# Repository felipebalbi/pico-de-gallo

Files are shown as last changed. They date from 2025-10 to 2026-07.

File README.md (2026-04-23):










# Pico de Gallo

A USB bridge that turns a [Raspberry Pi Pico 2](https://www.raspberrypi.com/products/raspberry-pi-pico-2/)
into a host-accessible I²C, SPI, UART, GPIO, PWM, ADC, and 1-Wire interface. Write and test
embedded Rust drivers on your development machine without cross-compiling
or flashing firmware to a target board.

## Overview

Pico de Gallo provides:

- **I²C**: read, write, write-then-read, bus scanning, and transaction batching
- **SPI**: read, write, full-duplex transfer, write-then-read, and transaction batching
- **UART**: read, write, flush, and baud rate configuration
- **GPIO**: digital input/output, edge event monitoring (subscribe/unsubscribe)
- **PWM**: 4-channel PWM output with configurable frequency and duty cycle
- **ADC**: 4 GPIO-based analog inputs (12-bit)
- **1-Wire**: bus reset, read, write, strong pullup, and ROM search (PIO hardware)
- **Configuration**: runtime I²C/SPI/UART/PWM frequency and SPI mode changes

All communication uses [postcard-rpc](https://docs.rs/postcard-rpc) over
USB — a compact, typed, binary RPC protocol.

## Book

The [Pico de Gallo Book](https://opendevicepartnership.github.io/pico-de-gallo/)
covers hardware assembly, firmware flashing, and a step-by-step guide to
writing an embedded device driver using Pico de Gallo.

## Crates

| Crate | Description |
|---|---|
| [`pico-de-gallo-firmware`](crates/pico-de-gallo-firmware) | Embassy-rs firmware for the RP2350 |
| [`pico-de-gallo-lib`](crates/pico-de-gallo-lib) | Async host library (requires tokio) |
| [`pico-de-gallo-hal`](crates/pico-de-gallo-hal) | `embedded-hal` + `embedded-hal-async` implementation |
| [`pico-de-gallo-ffi`](crates/pico-de-gallo-ffi) | C FFI bindings (shared library + header) |
| [`gallo`](crates/pico-de-gallo-app) | CLI application for batch-mode access |
| [`pico-de-gallo-internal`](crates/pico-de-gallo-internal) | Shared wire-protocol types (internal) |

### Firmware

Embassy-rs firmware for the RP2350 that exposes I²C, SPI, UART, and GPIO
peripherals over USB via postcard-rpc endpoints.

### Library

Async host-side library wrapping the postcard-rpc transport. Provides
typed methods for every firmware endpoint. Requires the tokio runtime.

### HAL

Implements both `embedded-hal` and `embedded-hal-async` traits — including
`I2c`, `SpiBus`, `SpiDevice`, GPIO digital I/O, delay, and `embedded-io`
Read/Write for UART — so embedded device drivers written against those traits
can be tested on a host machine with real hardware attached to the Pico de Gallo.

### App

Command-line tool (`gallo`) for interactive and batch-mode I²C/SPI/UART/GPIO
access. Supports hex, binary, and ASCII output formats.

### FFI

C-compatible shared library wrapping the Rust host library. Generates a
C header via cbindgen. Suitable for integration into C/C++/Python/etc.
projects.

### Internal

Shared wire-protocol crate defining all postcard-rpc endpoints, request
and response types, and constants. Used by both firmware and host crates.

## Hardware

KiCAD schematic and PCB design for a Pico 2 daughter board. The v1.1
board features a single keyed 2x12 shrouded header that routes all 20
firmware signals with on-board I²C pull-ups and ADC input protection.

## Case

3D-printable snap-fit enclosure (FreeCAD) in two parts — body and lid.

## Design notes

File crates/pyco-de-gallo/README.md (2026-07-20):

# pyco-de-gallo

Python bindings for [Pico de Gallo](https://github.com/OpenDevicePartnership/pico-de-gallo),
a USB-attached protocol bridge built on the
[Raspberry Pi Pico 2](https://www.raspberrypi.com/products/raspberry-pi-pico-2/)
(RP2350). Talk **I²C, SPI, UART, GPIO, PWM, ADC, and 1-Wire** straight from
Python — no cross-compiling, no flashing on every change. Develop and test
your embedded drivers on your laptop and let the Pico do the wiggling.

The native extension wraps the async Rust host library (`pico-de-gallo-lib`)
with [PyO3](https://pyo3.rs). Every method is **synchronous** from Python's
point of view; the async USB I/O is driven by a Tokio runtime owned by each
device handle, and the GIL is released for the duration of each round-trip so
your other Python threads keep running.

## Requirements

`pip install` gives you the host-side library. To do anything useful you also
need the hardware: a Raspberry Pi Pico 2 (or a Pico de Gallo landing board)
running the [Pico de Gallo firmware](https://github.com/OpenDevicePartnership/pico-de-gallo).

- **Python:** CPython 3.8+ (and PyPy). Prebuilt wheels are published for
  CPython 3.8–3.14.
- **Platforms:** Linux (x86_64 / aarch64, manylinux + musllinux),
  Windows (x64 / x86), macOS (Apple silicon).

## Installation

```sh
pip install pyco-de-gallo
```

The Python import name is `pyco_de_gallo` (underscores), while the
distribution name on PyPI is `pyco-de-gallo` (hyphens).

## Quick start

```python
import pyco_de_gallo as gallo

# Connect to the first attached board and verify the firmware is
# wire-compatible with this library. Raises RuntimeError on mismatch.
dev = gallo.open_strict()

v = dev.version()
print(f"Firmware {v.major}.{v.minor}.{v.patch}")

# I²C: switch to 400 kHz, then write a register pointer and read it back.
dev.i2c_set_config(gallo.I2cFrequency.Fast)
data = dev.i2c_write_read(0x50, [0x00], 16)   # e.g. read 16 bytes from an EEPROM
print(list(data))
```

If several boards are connected, pick one deterministically by serial number:

```python
import pyco_de_gallo as gallo

for d in gallo.list_devices():
    print(d.serial_number, d.manufacturer, d.product)

dev = gallo.open_strict_with_serial_number("E6625C087B...")
```

> `open()` / `open_with_serial_number()` are the lazy variants: they connect
> but only surface failures on the first RPC call. Prefer the `*_strict`
> variants in real code — they fail fast with a clear exception if the device
> is unreachable or the firmware schema doesn't match.

## Peripherals

| Bus | Highlights |
|---|---|
| I²C | `i2c_read` / `i2c_write` / `i2c_write_read`, `i2c_scan`, `i2c_batch`, 100 kHz–1 MHz |
| SPI | `spi_read` / `spi_write` / `spi_transfer`, `spi_batch` under chip-select, configurable phase/polarity |
| UART | `uart_read` (with timeout) / `uart_write` / `uart_flush`, configurable baud rate |
| GPIO | read/write, blocking edge waits (with optional timeout), and push-based edge events |
| PWM | per-channel duty cycle, frequency, phase-correct, enable/disable |
| ADC | single-shot 12-bit reads on 4 channels |
| 1-Wire | reset/presence, read/write, strong-pullup, and ROM search |

> Some peripherals (ADC, UART, 1-Wire) require **hw-rev2** firmware, and not
> every signal is broken out on the V1 landing board. See the firmware and
> hardware docs for the routing details.

### Blink an LED (GPIO)

```python
import time
import pyco_de_gallo as gallo

dev = gallo.open_strict()
dev.gpio_set_config(0, gallo.GpioDirection.Output, gallo.GpioPull.Disabled)

while True:
    dev.gpio_put(0, True)
    time.sleep(0.5)
    dev.gpio_put(0, False)
    time.sleep(0.5)
```

### React to GPIO edges (push events)

```python
import pyco_de_gallo as gallo

dev = gallo.open_strict()

# The subscription must be live before the firmware will buffer events.
with dev.subscribe_gpio_events() as events:
    dev.gpio_subscribe(0, gallo.GpioEdge.Falling)
    for event in events:
        print(event.pin, event.edge, event.state, event.timestamp_us)
```

### Scan the I²C bus

```python
import pyco_de_gallo as gallo

dev = gallo.open_strict()
dev.i2c_set_config(gallo.I2cFrequency.Standard)

for addr in dev.i2c_scan(include_reserved=False):
    print(f"0x{addr:02x}")
```

## Error handling

Failures from the underlying transport and firmware are raised as Python
`RuntimeError` exceptions with a descriptive message (for example, an I²C
NACK, a GPIO timeout, or a firmware schema mismatch).

## More examples

Runnable scripts for every peripheral — including a live TMP108 temperature
graph, a PWM sine-wave fade, a SPI loopback test, and a 1-Wire ROM search —
live in the
[`examples/`](https://github.com/OpenDevicePartnership/pico-de-gallo/tree/main/crates/pyco-de-gallo/examples)
directory.

## Documentation

- Project book: <https://opendevicepartnership.github.io/pico-de-gallo/>
- Source and issues: <https://github.com/OpenDevicePartnership/pico-de-gallo>

## License

MIT

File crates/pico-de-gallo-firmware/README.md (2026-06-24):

# Pico de Gallo Firmware

Embassy-rs firmware for the Raspberry Pi Pico 2 (RP2350) that turns it into
a USB bridge for I2C, SPI, and GPIO access.

## Building

```console
$ rustup target add thumbv8m.main-none-eabihf
```

For rev1 hardware:

```console
$ cargo build --release --manifest-path crates/pico-de-gallo-firmware/Cargo.toml --target thumbv8m.main-none-eabihf
```

For rev2 hardware:

```console
$ cargo build --release --manifest-path crates/pico-de-gallo-firmware/Cargo.toml --target thumbv8m.main-none-eabihf --no-default-features --features hw-rev2
```

## Flashing

Convert the ELF to UF2 and copy to the Pico 2 in BOOTSEL mode:

```console
$ picotool uf2 convert crates/pico-de-gallo-firmware/target/thumbv8m.main-none-eabihf/release/pico-de-gallo-firmware -t elf firmware.uf2
$ picotool load firmware.uf2
```

Or simply drag `firmware.uf2` onto the `RP2350` USB mass storage drive.

## Peripheral Mapping

| Function | RP2350 Pins | Notes |
|---|---|---|
| I2C1 SDA | GPIO 2 | 7-bit addressing, async mode |
| I2C1 SCL | GPIO 3 | |
| SPI0 SCK | GPIO 6 | DMA-backed full-duplex |
| SPI0 TX  | GPIO 7 | |
| SPI0 RX  | GPIO 4 | |
| GPIO 0–7 | GPIO 8–15 | Input/output/edge-wait |
| USB | Native USB  | postcard-rpc transport |

## License

Licensed under the terms of the [MIT license](http://opensource.org/licenses/MIT).

## Contribution

Any contribution intentionally submitted for inclusion in the work by
you shall be licensed under the terms of the same MIT license, without
any additional terms or conditions.

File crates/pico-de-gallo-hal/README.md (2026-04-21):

# Pico de Gallo HAL




[embedded-hal](https://crates.io/crates/embedded-hal) and
[embedded-hal-async](https://crates.io/crates/embedded-hal-async)
implementation backed by a [Pico de Gallo](https://github.com/OpenDevicePartnership/pico-de-gallo)
USB bridge.

Run embedded Rust drivers on your host machine by forwarding I²C, SPI,
GPIO, and delay operations to real hardware via USB.

## Quick Start

```rust
use pico_de_gallo_hal::Hal;
use embedded_hal::i2c::I2c;

let hal = Hal::new();
let mut i2c = hal.i2c();

let mut buf = [0u8; 2];
i2c.write_read(0x48, &[0x00], &mut buf).unwrap();
```

Check out the
[examples](https://github.com/OpenDevicePartnership/pico-de-gallo/tree/main/crates/pico-de-gallo-hal/examples)
for more usage patterns.

## Implemented Traits

| Peripheral | Blocking | Async |
|---|---|---|
| GPIO | `OutputPin`, `InputPin`, `StatefulOutputPin` | `Wait` |
| I²C | `I2c` | `I2c` |
| SPI | `SpiBus`, `SpiDevice` | `SpiBus`, `SpiDevice` |
| Delay | `DelayNs` | `DelayNs` |

`SpiDevice` manages chip-select (CS) automatically via a GPIO pin.
Use `hal.spi_device(cs_pin)` to create one. For raw bus access without
CS management, use `hal.spi()`.

# License

Licensed under the terms of the [MIT license](http://opensource.org/licenses/MIT).

# Contribution

Any contribution intentionally submitted for inclusion in the work by
you shall be licensed under the terms of the same MIT license, without
any additional terms or conditions.

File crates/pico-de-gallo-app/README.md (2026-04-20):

# Gallo




Command-line interface for the [Pico de Gallo](https://github.com/OpenDevicePartnership/pico-de-gallo)
USB bridge. Provides direct access to I²C, SPI, and GPIO peripherals
in batch mode.

# Usage

```console
$ gallo list                             # List connected devices
$ gallo version                          # Query firmware version
$ gallo i2c scan                         # Scan I2C bus
$ gallo i2c read -a 0x48 -c 2            # Read 2 bytes from address 0x48
$ gallo i2c write -a 0x50 -b 0xDE 0xAD   # Write bytes to address 0x50
$ gallo spi transfer -b 0x01 0x02        # Full-duplex SPI transfer
$ gallo spi read -c 10 -f ascii          # Read 10 bytes, ASCII output
```

## Output Formats

Read data can be displayed in three formats via `-f` / `--format`:

- `hex` (default): hexadecimal byte dump
- `binary`: raw bytes to stdout
- `ascii`: printable characters, non-printable shown as `.`

# License

Licensed under the terms of the [MIT license](http://opensource.org/licenses/MIT).

# Contribution

Any contribution intentionally submitted for inclusion in the work by
you shall be licensed under the terms of the same MIT license, without
any additional terms or conditions.

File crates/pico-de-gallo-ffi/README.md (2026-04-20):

# Pico de Gallo FFI




C-compatible FFI bindings for the [Pico de Gallo](https://github.com/OpenDevicePartnership/pico-de-gallo)
USB bridge. Wraps the Rust host library in an opaque-pointer API with
integer status codes, suitable for use from C, C++, Python, and other
languages.

## Usage

```c
#include "pico_de_gallo.h"

const PicoDeGallo *gallo = gallo_init();
uint32_t id = 42;
Status status = gallo_ping(gallo, &id);
gallo_free(gallo);
```

A C header (`pico_de_gallo.h`) is generated automatically by
[cbindgen](https://docs.rs/cbindgen) at build time.

# License

Licensed under the terms of the [MIT license](http://opensource.org/licenses/MIT).

# Contribution

Any contribution intentionally submitted for inclusion in the work by
you shall be licensed under the terms of the same MIT license, without
any additional terms or conditions.

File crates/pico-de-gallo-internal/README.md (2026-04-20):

# Pico de Gallo Internal




Shared wire-protocol types for the [Pico de Gallo](https://github.com/OpenDevicePartnership/pico-de-gallo)
USB bridge. This crate defines all [postcard-rpc](https://docs.rs/postcard-rpc)
endpoints, request/response types, and constants used by both the
firmware and host-side library.

> **Note:** This is an internal crate. Application code should use
> [`pico-de-gallo-lib`](https://crates.io/crates/pico-de-gallo-lib) or
> [`pico-de-gallo-hal`](https://crates.io/crates/pico-de-gallo-hal) instead.

## Features

- `use-std` — Enables `Vec<u8>` response types for the host side.
  Without this feature (the firmware default), responses use borrowed
  `&[u8]` slices.

# License

Licensed under the terms of the [MIT license](http://opensource.org/licenses/MIT).

# Contribution

Any contribution intentionally submitted for inclusion in the work by
you shall be licensed under the terms of the same MIT license, without
any additional terms or conditions.

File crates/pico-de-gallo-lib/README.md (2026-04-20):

# Pico de Gallo Lib




Async host-side library for communicating with a [Pico de Gallo](https://github.com/OpenDevicePartnership/pico-de-gallo)
USB bridge device. Provides typed methods for I²C, SPI, GPIO, and
device configuration over USB.

Requires the [tokio](https://tokio.rs) async runtime.

## Quick Start

```rust
use pico_de_gallo_lib::PicoDeGallo;

#[tokio::main]
async fn main() {
    let gallo = PicoDeGallo::new();
    let version = gallo.version().await.unwrap();
    println!("Firmware v{}.{}.{}", version.major, version.minor, version.patch);
}
```

See the [examples](https://github.com/OpenDevicePartnership/pico-de-gallo/tree/main/crates/pico-de-gallo-lib/examples)
for more usage patterns.

# License

Licensed under the terms of the [MIT license](http://opensource.org/licenses/MIT).

# Contribution

Any contribution intentionally submitted for inclusion in the work by
you shall be licensed under the terms of the same MIT license, without
any additional terms or conditions.

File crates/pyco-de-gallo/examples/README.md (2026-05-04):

# pyco-de-gallo examples

Runnable Python scripts that demonstrate how to drive a Pico de Gallo
device from the `pyco_de_gallo` Python module.

## Setup

From the `crates/pyco-de-gallo` directory:

```sh
python -m venv .env
. .env/bin/activate          # Windows: .env\Scripts\Activate.ps1
pip install maturin
maturin develop --release
```

This builds the native extension and installs it into the active
virtual environment.

## Running

With the device plugged in:

```sh
python examples/tmp108_read.py
```

## Examples

| Script | Peripheral | What it does |
|---|---|---|
| `device_info.py`  | none | Lists every attached device and prints firmware/schema versions plus a capability matrix. |
| `i2c_scan.py` | I2C | Scans the I2C bus and prints every responding 7-bit address. |
| `tmp108_read.py`  | I2C | Reads ambient temperature from a TMP108 sensor at `0x48`. |
| `tmp108_live.py`  | I2C | Live scrolling temperature graph (Rich + braille). Needs `pip install rich`. |
| `gpio_blink.py` | GPIO | Blinks an LED on GPIO0. |
| `gpio_events.py`  | GPIO | Subscribes to falling edges on GPIO0 and prints each event. |
| `pwm_fade.py` | PWM | Smoothly fades an LED with a sine wave on PWM channel 0. |
| `adc_read.py` | ADC | Reads all 4 ADC channels and prints millivolts (needs hw-rev2 firmware). |
| `spi_loopback.py` | SPI | Verifies SPI by short-circuiting MOSI to MISO. |
| `uart_echo.py` | UART | Verifies UART by short-circuiting TX to RX (needs hw-rev2 firmware). |
| `onewire_scan.py` | 1-Wire | Discovers ROM IDs of every device on the 1-Wire bus (needs hw-rev2 firmware). |

Each script has a wiring comment at the top describing exactly how to
connect the parts. On the **V1 landing board**, only I2C, SPI (without
CS), GPIO 0–3, and PWM 0–3 are routed to connectors — for ADC, UART,
1-Wire, or SPI-CS you need to wire to the bare Pico's castellated
pads.

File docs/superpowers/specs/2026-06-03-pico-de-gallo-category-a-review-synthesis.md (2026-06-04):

# Spec: Category A Hotfix — Review Synthesis

- **Date:** 2026-06-03
- **Status:** Draft — basis for `2026-06-03-pico-de-gallo-category-a-hotfix.md` plan
- **Scope:** Captures findings from three parallel read-only subagent
  reviews (reviewer / reliability / architect) of the seven crates in
  `crates/` and partitions them into three categories. Specifies the
  Category A hotfix (this spec → that plan). Lists Category B and C as
  out-of-scope for the hotfix but tracked for future work.

## 1. Background

After PR #56 (the AI-agent HAL guide) shipped, we dispatched three
read-only subagents in parallel to audit the seven Rust crates under
`crates/`:

- **reviewer** (adversarial correctness) — looked for surface gaps,
  wire-protocol inconsistencies, cross-crate parity drift, test
  coverage holes, hygiene issues, book/code drift.
- **reliability** (failure modes) — looked for host crash recovery,
  USB transport failure, firmware-side panics / wedges, race
  conditions, timeouts, idempotency, observability.
- **architect** (design) — looked for module/crate boundary mistakes,
  API shape problems, error-type design, wire-protocol scalability,
  versioning model, long-term evolution.

This spec deduplicates their findings, prioritizes by severity, and
groups them by what work each finding implies.

## 2. Findings (43 items, prioritized)

### 2.1 Critical bugs — Category A (fix before next release)

| # | Finding | Source | Severity |
|---|---|---|---|
| 1 | `validate()` ignores `schema_major` — only compares minor. Today the minor is the pre-1.0 breaking-change axis so the check works; the moment `internal` hits 1.0 or someone bumps major by mistake, validation silently accepts a mismatched device. | reviewer B1: `crates/pico-de-gallo-lib/src/lib.rs:667` | Blocker for 1.0 |
| 2 | GPIO `wait_for_*` wedges the entire firmware dispatcher. Host crash + `gpio_wait_for_high` on a pin that never transitions = device unusable until power-cycle. Worse than the original `system/reset-subscriptions` regression because it bricks the whole device. | reliability B1: `crates/pico-de-gallo-firmware/src/handlers/gpio.rs:86–143` | Blocker — field reproducible |
| 3 | No watchdog in firmware. Any handler hang (B2 above, I²C stuck bus, 1-Wire PIO stall) requires power-cycle to recover. | reliability R5: `crates/pico-de-gallo-firmware/src/main.rs:354–468` | Blocker — defense-in-depth |

### 2.2 Real bugs — Category A (fix before next release if practical)

| # | Finding | Source | Effort |
|---|---|---|---|
| 4 | Schema validation opt-in everywhere except FFI `gallo_get_device_info`. `Hal::new`, `gallo_init`, `pyco::open`, `app::Cli::connect` all skip `validate()`. | reliability R4 | S |
| 5 | HAL doesn't expose `system_reset_subscriptions` or `validate`. (PR #56 side finding #1; reliability R2.) | known | S |
| 6 | `AdcChannel`, `GpioDirection`, `GpioPull`, `GpioEdge`, `AdcConfigurationInfo` not re-exported by `pico-de-gallo-hal`. (PR #56 side finding #2.) | known | XS |
| 7 | `gpio_subscribe_handler` capacity-1 channel can wedge dispatcher. Same shape as B1, requires multiple things to go wrong but it exists. | reliability S6 | S |
| 8 | I²C stuck-bus has no recovery. Slave holds SDA after host crash → every future I²C op fails until power-cycle. Need 9-SCL bit-bang recovery or new `i2c/recover` endpoint. | reliability B3 | M |
| 9 | FFI error mappers route every `*::Other` to the *read* failure code regardless of which operation was called. Dedicated `*GetConfigFailed`/`*WriteFailed` codes exist but are unreachable. | reviewer S1: `crates/pico-de-gallo-ffi/src/lib.rs:223, 231, 242, 255, 268, 276, 287` | S |
| 10 | `spi_batch_handler` mutates GPIO direction without updating `pin_modes` — silent hardware/state divergence. | reliability S2: `crates/pico-de-gallo-firmware/src/handlers/spi.rs:138` | S |
| 11 | `pico-de-gallo-ffi` has no GPIO event subscription read surface. Codes exist; subscribe/unsubscribe exist; but no `gallo_gpio_poll_event` or iter. | reviewer S2 | M |
| 12 | `pyco-de-gallo` ADC binding takes raw `u8` instead of `AdcChannel` enum. Bypasses Python type system. | reviewer S5: `crates/pyco-de-gallo/src/lib.rs:1287` | XS |
| 13 | Stale doc reference to `Hal::uart_set_config` at `crates/pico-de-gallo-hal/src/lib.rs:1282`. (PR #56 side finding #3.) | known | XS |
| 14 | `pico-de-gallo-internal` GPIO range docs inconsistent — some say `0..=7` (wrong), some say `0..=3` (right). | reviewer S3 + PR #56 side finding #4: `crates/pico-de-gallo-internal/src/lib.rs:470, 482, 510, 547, 586` | XS |
| 15 | Book endpoint catalog (`book/src/appendix/endpoints.md` lines 77–88) describes `gpio/event` topic wrong — implies one stream per pin, actually one multiplexed stream. | reviewer S6 | XS |

### 2.3 Test / hygiene additions — Category A

| # | Finding | Source | Effort |
|---|---|---|---|
| 34 | FFI `Status` enum has no discriminant-uniqueness test. Copy-paste during enum extension could collide. | reviewer B2 | XS |
| 35 | `crates/pico-de-gallo-internal/build.rs` schema constants have no test asserting they match `[package].version`. Stale incremental cache could ship a mismatched build. | reviewer S8 | XS |
| 36 | CI grep guard for the PR #56 agent-guide markdown not yet implemented. (PR #56 side finding #5.) | known | XS |

### 2.4 Architectural commitments — Category B (decide before 1.0)

These are not part of the Category A hotfix. Listed for tracking and
for the post-hotfix architectural discussion.

| # | Decision | Source | Cost if deferred |
|---|---|---|---|
| 16 | Freeze `internal` enum-ordering ABI with explicit discriminants on every wire enum + golden-file postcard snapshot tests. Today enforced only by comments. | architect 1.1 | Major break post-1.0 |
| 17 | `PicoDeGallo` is a flat god-object (50+ methods). Split into per-peripheral handles so HAL is mostly mechanical and there's a place for cached session state. | architect 1.2 | Major break post-1.0 |
| 18 | FFI `Status` enum is sequential-by-insertion-order, not grouped. Reserve ranges per peripheral now, while still 0.x. | architect 1.6 + reviewer S1 | Major C ABI break post-1.0 |
| 19 | Add `gpio_pin_count`, `pwm_channel_count`, `adc_channel_count`, `i2c_bus_count`, `spi_bus_count` to `DeviceInfo` now. Host currently assumes 4/4/4/1/1. | architect 1.8 | Major break post-1.0 |
| 20 | Add optional `bus: u8` (default 0) to every peripheral request type now, before 1.0. Adding a second I²C/SPI bus later means duplicating every endpoint. | architect 3.1 | Major wire break post-1.0 |
| 21 | `Comms(String)` in seven HAL error types loses error chains. Carry the typed `HostErr<WireError>` instead. | architect 1.5 | Locked into stringly-typed errors |
| 22 | HAL pin ownership is runtime-enforced (`GpioError::PinMonitored`). Compile-time pin ownership tokens + typed pin direction would close the foot-gun. | architect 1.3 + 1.4 | One more outage of the same class |
| 23 | `Hal::new()` `.unwrap()` on `Runtime::new()` + silent multi-runtime creation. Should return `Result`, detect `current_thread` flavor, accept an existing `Handle`. | architect 1.7 | API break, but worse if it ships into 1.0 |

### 2.5 Sharp edges — Category C (convenience fixes, file as issues)

| # | Finding | Source | Effort |
|---|---|---|---|
| 24 | `SpiDev` cancellation-safety docstring is wrong. | reliability S1: `crates/pico-de-gallo-hal/src/lib.rs:1086–1091` | XS |
| 25 | No `system/reset-all` endpoint. Only `system/reset-subscriptions` exists; pin direction / PWM enable / configs survive across host crashes. | reliability R1 | M |
| 26 | `gallo_init` / `pyco::open` / `app::Cli::connect` are lazy — no enumeration check. | reliability R3 | S |
| 27 | `gpio_unsubscribe` race — event for unsubscribed pin can arrive after `Ok(())`. Doc only. | reliability S3 | XS |
| 28 | GPIO event publish failures silent. Add `warn!` on drop. | reliability S4 | XS |
| 29 | USB OTP-read failure → serial = `"0000000000000000"`. Collision risk. | reliability S5 | XS |
| 30 | `nusb` claims interface exclusively. Document "one host per device". | reliability S8 | XS doc-only |
| 31 | `onewire_search` silently restarts mid-enumeration if called instead of `search_next`. | reliability S9 | XS |
| 32 | PWM compare scaling truncates silently when reconfiguring frequency. 100%-on becomes 99.x%-on. | reliability S10: `crates/pico-de-gallo-firmware/src/handlers/pwm.rs:148–158` | S |
| 33 | `i2c_scan` blocks dispatcher for entire scan. **Becomes Category A** as a prereq for the watchdog (finding #3). | reliability B2 | S |
| 37 | `pico-de-gallo-driver-tests` crate that runs canonical drivers as HIL `#[test]`s gated by env var. | architect 2.5 | M (post-1.0) |
| 38 | `pyco-de-gallo` has no Rust-side tests. | known | M |
| 39 | `pico-de-gallo-app` magic `4` for event channel size. | reviewer S7: `crates/pico-de-gallo-app/src/lib.rs:1015` | XS |
| 40 | AGENTS.md is 800+ lines. Split into top-level + per-crate. | architect 3.6 | M (process work) |
| 41 | (Done in PR #56) — Hal::new async usage warning. | known | done |
| 42 | `Capabilities::contains(NONE)` always returns true — add doctest. | reviewer S4 | XS |
| 43 | (Will be done in Cat A) — Add gotcha rows to AGENTS.md §13 for B1, R4, B3. | reliability rec | XS |

## 3. Things verified clean (no work needed)

The reviewer and reliability subagents independently verified these
are **not** problems:

- Enum-variant ordering in `internal` (no reorderings vs. wire-index
  expectations).
- Endpoint catalog in `internal` matches AGENTS.md §6.3 and
  `book/src/appendix/endpoints.md` line-for-line.
- `Cargo.lock` present and committed for both workspaces.
- Pinned-deps rationale (`embassy-usb-driver = "=0.2.0"`) documented
  in AGENTS.md §7.2.
- All seven crates have `CHANGELOG.md`.
- 300+ wire-type round-trip tests in `internal`.
- FFI null-pointer tests for every batch / transfer / system endpoint.
- `Capabilities` round-trip + bitop tests present.
- CLI `version` correctly handles `LegacyFirmware` fallback.
- Cargo.toml metadata complete on all six published crates.
- `pyco` correctly `publish = false`.
- All seven crates pin `rust-version = "1.90"`.
- Batch handlers (`i2c_batch`, `spi_batch`) walk ops twice (validate-
  then-execute) — no partial state mutation on bad encoding.
- `map_validate_error` policy correct.
- `spi_set_config` and `uart_set_config` guard against zero
  frequency / baud.
- `pwm_channel_parts` bounds-checks — no `unwrap` reaches
  `pwm_slices`/`pwm_configs`.
- GPIO `set_config` correctly rejects monitored pins.
- No firmware NVM / persistent state — boot-clean.
- `compute_pwm_params` bounded loop, no panic paths.

## 4. Category A scope (this hotfix)

The Category A hotfix ships as **two PRs**:

### 4.1 PR 1 — wire-change lockstep release

Covers findings **#1** (validate major), **#2** (GPIO wait wedge),
**#3** (no watchdog), **#33** (i2c_scan blocks dispatcher — prereq
for the watchdog timing budget).

**Wire change:** append `timeout_ms: u32` field to all five
`gpio_wait_*` request types in `pico-de-gallo-internal`; append
`GpioError::Timeout` variant at end of enum. Bumps schema minor
0.6 → 0.7. Per AGENTS.md §6.5, requires lockstep release of
`internal`, `firmware`, and every host crate.

**Firmware changes:** wrap `gpio_wait_*` handlers in
`embassy_time::with_timeout` when `timeout_ms > 0`; enable
`embassy_rp::watchdog::Watchdog` at 2 s in a dedicated
`embassy_executor::task` that feeds periodically; fix `i2c_scan`
with per-address `with_timeout(50ms)` to bound worst-case below
the watchdog window.

**Host changes:** every host surface adds a `_with_timeout(Duration)`
overload (`lib`, `hal`, `ffi`, `app` CLI flag, `pyco`).

### 4.2 PR 2 — host-only fixes

Covers findings **#1** (validate major check), **#4** (schema
validation at all entry points), **#5** (HAL exposes
`system_reset_subscriptions` + `validate`), **#6** (HAL re-exports),
**#13** (stale doc), **#14** (GPIO range doc drift), **#15**
(book endpoints doc), **#34** (Status uniqueness test),
**#35** (schema version test), **#36** (agent-guide CI guard).

No wire change. Each crate releases independently via release-please.

### 4.3 Out of scope

- All Category B items (architectural commitments — separate plan).
- All Category C items (file as issues, batch later).
- Findings 7, 8, 10, 11, 12 (deferred to Category C unless trivial
  to fold into PR 2):
  - **#7** GPIO subscribe wedge — kept on Cat C; same fix shape as
    the watchdog covers the worst case.
  - **#8** I²C stuck bus — Cat C; requires bit-bang recovery design.
  - **#10** SPI batch pin_mode tracking — Cat C; doc-fix it in the
    same area in PR 2 if cheap.
  - **#11** FFI GPIO event read surface — Cat C; design needed.
  - **#12** pyco ADC raw u8 — Cat C; folded into a pyco hygiene PR.
  - **#9** FFI Other → ReadFailed mis-routing — Cat C; structural,
    needs the renumbering decision (#18) first.

## 5. Acceptance criteria

The Category A hotfix is complete when:

1. PR 1 is open as a draft against `OpenDevicePartnership/pico-de-gallo:main`
   from `felipebalbi:category-a-hotfix-wire`.
2. PR 2 is open as a draft against the same base from
   `felipebalbi:category-a-hotfix-host`.
3. Every finding in §2.1, §2.2, §2.3 has a closing commit in one of
   the two PRs.
4. Every commit honors AGENTS.md §4 hard rules (LF endings, both AI
   attribution trailers, no `Signed-off-by:`, lockfile pairing,
   `--locked` validation, no enum reordering).
5. CI on both PRs is green (`check`, `lockfile`, `deny`, `semver`,
   `actionlint`, `nostd`).
6. PR 1's description contains the release-operator runbook from
   the plan (six-step merge order, 60-second waits, re-run
   instructions, tag-prefix typo trap).
7. AGENTS.md §13 has two new rows logging the regressions closed
   (B1 dispatcher wedge, R4 silent schema mismatch).

## 6. Open questions

None. All decisions are locked. Discussion is in this conversation's
brainstorming and review history.

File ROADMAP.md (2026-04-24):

# Pico de Gallo — Roadmap to 1.0

> Last updated: 2026-04-24

This document lays out the path to a 1.0 release of the pico-de-gallo
project. Changes are grouped into phases and listed in ascending order of
complexity. Each entry explains *what*, *why*, and *what it unlocks*.

---

## Table of Contents

- [Where We Are Today](#where-we-are-today)
- [Design Philosophy](#design-philosophy)
- [Phase 1 — Polish What Exists](#phase-1--polish-what-exists)
- [Phase 2 — New Protocols (Software Only)](#phase-2--new-protocols-software-only)
- [Phase 3 — Advanced Features](#phase-3--advanced-features)
- [Phase 4 — Hardware Rev 2](#phase-4--hardware-rev-2)
- [Phase 5 — 1.0 Release Criteria](#phase-5--10-release-criteria)
- [Should the RP2350 Stay?](#should-the-rp2350-stay)
- [Appendix A — embedded-hal Trait Coverage Matrix](#appendix-a--embedded-hal-trait-coverage-matrix)
- [Appendix B — Competitive Landscape](#appendix-b--competitive-landscape)
- [Appendix C — RP2350 Peripheral Budget](#appendix-c--rp2350-peripheral-budget)
- [Conventions — How to Update This File](#conventions--how-to-update-this-file)

---

## Progress Overview

| Phase | Description | Items | Done | Status |
|---|---|---|---|---|
| **1** | Polish What Exists | 6 | 6 | ✅ Complete |
| **2** | New Protocols | 4 | 3 | 🟡 In progress (2.6 blocked) |
| **3** | Advanced Features  | 6 | 3 | 🟡 In progress (3.4–3.6 deferred) |
| **4** | Hardware Rev 2 | 6 | 1 | 🟡 In progress |

---

## Where We Are Today

| Area | Status |
|---|---|
| **I2C** | 1 bus (I2C1), 7-bit addressing, read/write/write-read/scan, configurable frequency (Standard/Fast/Fast+) |
| **SPI** | 1 bus (SPI0), read/write/flush/transfer, configurable polarity/phase, DMA-backed |
| **UART** | 1 bus (UART0), read/write/flush, configurable baud rate, interrupt-driven with 1024-byte TX/RX buffers. **hw-rev2 only.** |
| **GPIO** | 4 pins (GPIO8–11), input/output/wait-for-edge, push-based edge event monitoring |
| **USB** | Full Speed (12 Mbps), postcard-rpc over raw USB bulk |
| **HAL traits**  | `I2c`, `SpiBus`, `InputPin`, `OutputPin`, `StatefulOutputPin`, `Wait`, `DelayNs`, `embedded_io::{Read,Write}` (sync + async) |
| **Hardware** | v1.0 landing board (7 connectors, 13/20 signals); v1.1 landing board (2×12 header, all 20 signals, I²C pull-ups, ADC protection). `hw-rev1`/`hw-rev2` feature flags gate peripheral availability. No level shifters, no ESD. |
| **Host crates** | internal (protocol), lib (high-level API), hal (embedded-hal bridge), ffi (C bindings), app (CLI) |
| **Endpoints** | 27 total (ping, version, I2C×5, SPI×5, UART×5, GPIO×8, config×4). UART/ADC/1-Wire return `Unsupported` on hw-rev1. |
| **Tests** | 298 unit + 5 doctests, CI on every push (both hardware revisions) |

### What's Missing

Compared to what embedded developers routinely need, pico-de-gallo is
still missing:

- **10-bit I2C** — some devices use extended addressing (blocked on upstream embassy-rp)
- **Voltage flexibility** — hardware is 3.3 V only; no path to 1.8 V or 5 V
- **Target power** — users must externally power their target

---

## Design Philosophy

Pico de Gallo's unique value proposition is not raw speed or protocol
coverage — commercial bridges like the FT2232H and Total Phase Aardvark
will always win on throughput and polish. The value is:

> **Any driver on crates.io that uses `embedded-hal` traits can be
> developed and tested on a host PC using pico-de-gallo as the hardware
> backend.**

Every design decision should maximize embedded-hal trait coverage and
driver compatibility. If a driver author uses `I2c + OutputPin + DelayNs`
(the most common combination), pico-de-gallo should Just Work™.

The priority order for trait implementations is driven by how commonly
each trait appears in crates.io drivers:

1. `I2c` — ✅ done
2. `SpiDevice` / `SpiBus` — ✅ done
3. `OutputPin` / `InputPin` — ✅ done
4. `DelayNs` — ✅ done
5. `embedded-io Read/Write` (UART) — ✅ done
6. `SetDutyCycle` (PWM) — ✅ done

---

## Phase 1 — Polish What Exists

*Complexity: low. No new hardware. Mostly non-breaking changes.*

These are quality improvements that make the existing feature set more
reliable and complete before adding new capabilities.

| | Item | Tracking |
|---|---|---|
| ☑ | [1.1 Rich Error Types](#11-rich-error-types) | [#1](https://github.com/OpenDevicePartnership/pico-de-gallo/issues/1) |
| ☑ | [1.2 SpiDevice Trait](#12-spidevice-trait-implementation) | [#2](https://github.com/OpenDevicePartnership/pico-de-gallo/issues/2) |
| ☑ | [1.3 I2C Bus Scan](#13-i2c-bus-scan-endpoint) | [#3](https://github.com/OpenDevicePartnership/pico-de-gallo/issues/3) |
| ☑ | [1.4 GPIO Direction Control](#14-gpio-direction-control) | [#4](https://github.com/OpenDevicePartnership/pico-de-gallo/issues/4) |
| ☑ | [1.5 Config Query Endpoints](#15-configuration-query-endpoints) | [#5](https://github.com/OpenDevicePartnership/pico-de-gallo/issues/5) |
| ☑ | [1.6 MAX_TRANSFER_SIZE Audit](#16-max_transfer_size-audit) | [#6](https://github.com/OpenDevicePartnership/pico-de-gallo/issues/6) |

### 1.1 Rich Error Types

**What:** Replace unit-struct failures (`I2cReadFail`, `SpiWriteFail`, etc.)
with enums carrying error detail from the firmware.

**Why:** When an I2C write fails, the user currently gets `I2cWriteFail` with
no indication whether it was a NACK, bus timeout, arbitration loss, or
firmware bug. Real embedded-hal `ErrorKind` variants (`NoAcknowledge`,
`Bus`, `ArbitrationLoss`, `Overrun`) should propagate from firmware through
the host crates.

**Impact:** Breaking change to internal + lib + hal. This is the single most
impactful quality improvement possible.

```
Firmware  →  I2cError::Nack  →  postcard  →  lib  →  hal  →  ErrorKind::NoAcknowledge
```

### 1.2 SpiDevice Trait Implementation

**What:** Implement `embedded_hal::spi::SpiDevice` (and the async variant)
in the HAL crate, with firmware-managed CS assertion.

**Why:** Most SPI drivers on crates.io use `SpiDevice`, not `SpiBus`.
`SpiDevice` wraps a full CS-assert → transfer → CS-deassert transaction.
Without it, users must manually wrap `SpiBus` with `embedded-hal-bus`
adapters, which adds friction and can be error-prone over USB.

**Design:** Add a firmware endpoint `spi/transaction` that holds CS low
across a sequence of operations, or use one of the existing GPIO pins as a
firmware-controlled CS with automatic assertion on each SPI endpoint call.

### 1.3 I2C Bus Scan Endpoint

**What:** Add an `i2c/scan` endpoint that probes all 7-bit addresses
(0x08–0x77) and returns a list of responding addresses.

**Why:** This is the first thing every embedded developer does when hooking
up an I2C bus. Every competing tool has it. The CLI app should print a
nice matrix like `i2cdetect`.

### 1.4 GPIO Direction Control

**What:** Add endpoints to configure individual GPIO pins as input or
output at runtime, with optional pull-up/pull-down configuration.

**Why:** Currently the firmware decides pin direction. Users should be able
to reconfigure pins dynamically — this is especially important for
open-drain protocols and bidirectional signaling.

### 1.5 Configuration Query Endpoints

**What:** Add `i2c/get-config` and `spi/get-config` endpoints that return
the current bus configuration.

**Why:** When writing multi-step automation scripts or debugging, it's
useful to confirm what configuration is active without relying on
local state.

### 1.6 MAX_TRANSFER_SIZE Audit

**What:** `pico-de-gallo-internal` defines `MAX_TRANSFER_SIZE = 4096`, but
comments in `pico-de-gallo-lib` still reference `512`. Audit and
synchronize all documentation and buffer sizes.

**Why:** Mismatched expectations between crates could cause silent data
truncation.

---

## Phase 2 — New Protocols (Software Only)

*Complexity: medium. No new hardware required (pins are already broken out
on the Pico 2 module), but requires new firmware drivers and new
endpoint families.*

| | Item | Tracking |
|---|---|---|
| ☑ | [2.1 UART Support](#21-uart-support) | [#7](https://github.com/OpenDevicePartnership/pico-de-gallo/issues/7) |
| ☑ | [2.2 PWM Support](#22-pwm-support) | [#8](https://github.com/OpenDevicePartnership/pico-de-gallo/issues/8) |
| ☑ | [2.3 ADC Support](#23-adc-support) | [#9](https://github.com/OpenDevicePartnership/pico-de-gallo/issues/9) |
| ☐ | [2.4 10-Bit I2C Addressing](#24-10-bit-i2c-addressing) | [#12](https://github.com/OpenDevicePartnership/pico-de-gallo/issues/12) |

### 2.1 UART Support

**What:** Implement UART bridging using RP2350's UART0 peripheral. Add
endpoints for read, write, and configuration (baud rate, data bits,
parity, stop bits). Implement `embedded_io::Read` and `embedded_io::Write`
(plus async variants) in the HAL crate.

**Why:** UART is the most universal embedded interface. It's used for:
- Serial console access
- Bootloader communication
- GPS modules, cellular modems, Bluetooth modules
- Debug logging
- Firmware upload/recovery

Not having UART is the single biggest functional gap compared to every
competing tool. Even the $4 CH340 does UART.

**Pin assignment:** Use GPIO0 (TX) and GPIO1 (RX) — these are the default
UART0 pins and are directly accessible on the Pico 2 header.

**Hardware note:** UART doesn't need board changes. The Pico 2's GPIO0/1
are already on the module header. A future board revision could add a
dedicated UART header/connector, but it's not required.

**Baud rates:** Support standard rates: 9600, 19200, 38400, 57600, 115200,
230400, 460800, 921600. Expose as a plain `u32` — the RP2350 will silently
clamp out-of-range values. Data bits, parity, and stop bits are deferred
to a future version (requires unsafe PAC register writes while interrupts
are active).

### 2.2 PWM Support

**What:** Expose 2–4 PWM outputs using RP2350's PWM slices. Add endpoints
for setting frequency, duty cycle, enable/disable. Implement the
`embedded_hal::pwm::SetDutyCycle` trait in the HAL crate.

**Why:** PWM is essential for:
- Servo control
- LED brightness (backlight controllers, RGB LEDs)
- Motor drivers
- Buzzer/audio tone generation
- Power supply enable/control

The `SetDutyCycle` trait is the last "common" embedded-hal trait not
implemented. Adding it means pico-de-gallo covers every standard trait
in embedded-hal 1.0.

**Pin assignment:** Repurpose 2–4 of the current GPIO pins (GPIO8–15 map
to PWM slices 4–7), or use additional Pico 2 header pins. PWM and GPIO
can coexist — a pin configured for PWM simply stops being a
general-purpose GPIO until reconfigured.

### 2.3 ADC Support

**What:** Expose RP2350's ADC channels (GPIO26–29 = ADC0–3).
Add endpoints for single-shot reads and
optionally continuous sampling. There is no standard embedded-hal ADC trait
in 1.0, so expose a project-specific API.

**Why:** ADC enables:
- Voltage monitoring (power rails, battery levels)
- Analog sensor reading (thermistors, potentiometers, light sensors)
- Signal level debugging

**Resolution:** RP2350 has a 12-bit ADC with 500 ksps. Single-shot reads
are simple; continuous streaming would benefit from DMA but pushes against
USB FS bandwidth limits for high sample rates.

**Hardware note:** GPIO26–29 are on the Pico 2 module header. No board
change needed, but a future revision should break these out to dedicated
ADC-labeled headers.

### 2.4 10-Bit I2C Addressing

**What:** Support `TenBitAddress` in addition to `SevenBitAddress` for I2C
operations.

**Why:** Some devices (particularly EEPROMs with large address spaces) use
10-bit addressing. The `embedded_hal::i2c::I2c` trait is generic over
address type, so the HAL should implement both.

---

## Phase 3 — Advanced Features

*Complexity: high. Software only, but requires deeper firmware
architecture changes.*

| | Item | Tracking |
|----|---|---|
| ☑  | [3.1 GPIO Event Topics](#31-gpio-event-topics-push-notifications) | [#13](https://github.com/OpenDevicePartnership/pico-de-gallo/issues/13) |
| ☑  | [3.2 Transaction Batching](#32-i2cspi-transaction-batching) | [#14](https://github.com/OpenDevicePartnership/pico-de-gallo/issues/14) |
| ☑  | [3.3 1-Wire via PIO](#33-1-wire-support-via-pio) | [#15](https://github.com/OpenDevicePartnership/pico-de-gallo/issues/15) |
| ⏳ | [3.4 Protocol Sniffing](#34-protocol-sniffing--logic-capture) | [#16](https://github.com/OpenDevicePartnership/pico-de-gallo/issues/16) — deferred to post-1.0 |
| ⏳ | [3.5 Config Persistence](#35-configuration-persistence) | [#17](https://github.com/OpenDevicePartnership/pico-de-gallo/issues/17) — deferred to post-1.0 |
| ⏳ | [3.6 Multi-Device Host](#36-multi-device-host-support) | [#18](https://github.com/OpenDevicePartnership/pico-de-gallo/issues/18) — deferred to post-1.0 |

### 3.1 GPIO Event Topics (Push Notifications)

**What:** Use postcard-rpc's topic mechanism (currently unused —
`TOPICS_IN_LIST` and `TOPICS_OUT_LIST` are empty) to push GPIO state
changes from firmware to host without polling.

**Why:** Polling `gpio/wait-*` endpoints ties up a USB transfer for each
pin being monitored. With topics, the firmware can notify the host of edge
events asynchronously. This enables interrupt-driven workflows and is
closer to how real embedded systems handle GPIO interrupts.

**Design:** Define a `GpioEvent` topic containing `{ pin: u8, state:
GpioState, timestamp_us: u64 }`. The host subscribes and receives events
as they occur.

### 3.2 I2C/SPI Transaction Batching

**What:** Allow a sequence of I2C or SPI operations to be sent as a single
USB transfer and executed atomically on the firmware side.

**Why:** Each USB round-trip adds 1–2 ms of latency. For multi-register
reads or device initialization sequences that require dozens of
operations, the cumulative latency dominates. Batching could speed up
EEPROM programming by 10–50×.

**Design:** A new `i2c/batch` endpoint that accepts a `Vec<I2cOperation>`
and returns `Vec<I2cResult>`. Similar for SPI.

### 3.3 1-Wire Support via PIO

**What:** Implement 1-Wire protocol using RP2350's PIO (Programmable I/O)
state machine. Embassy-rp already has a PIO 1-Wire program.

**Why:** 1-Wire is used by DS18B20 temperature sensors (extremely popular),
iButton devices, and some ID/authentication chips. It's a niche but
well-loved protocol that few USB bridges support — this would be a genuine
differentiator.

**Complexity:** PIO programming is non-trivial, but embassy-rp's existing
`pio_programs/onewire.rs` provides a starting point.

### 3.4 Protocol Sniffing / Logic Capture

**What:** Use a PIO state machine to passively monitor an I2C or SPI bus
and stream decoded frames to the host.

**Why:** This transforms pico-de-gallo from a pure master/controller into
a debugging tool. Being able to sniff what's happening on a bus (even one
driven by a different controller) is invaluable for hardware debugging.

**Limitations:** USB FS bandwidth caps continuous capture at ~700 KB/s
raw throughput. This is adequate for I2C (max 1 MHz = 125 KB/s) and
moderate SPI, but not for high-speed SPI or comprehensive logic analysis.
This is NOT a Saleae replacement — it's a "quick look at what's on the
bus" tool.

### 3.5 Configuration Persistence

**What:** Store the current bus configurations (I2C frequency, SPI mode,
GPIO directions, UART baud rate) in RP2350's flash so they survive
power cycles.

**Why:** Users who always work with the same target shouldn't have to
reconfigure on every plug-in. Useful for production test fixtures that
need deterministic startup.

### 3.6 Multi-Device Host Support

**What:** Allow multiple host applications to connect to separate
interfaces on the same pico-de-gallo simultaneously (e.g., one app uses
I2C, another uses UART).

**Why:** In complex setups, different tools may need to access different
buses. This requires firmware-side resource locking and multiple USB
endpoints or interfaces.

---

## Phase 4 — Hardware Rev 2

*Complexity: high. Requires PCB re-spin, component sourcing, and
potentially case redesign.*

This is the section that addresses the board re-spin directly. Changes are
ordered by impact-to-cost ratio.

| | Item | Tracking |
|----|---|---|
| ☐  | [4.1 Voltage Level Translators](#41-voltage-level-translators) | [#20](https://github.com/OpenDevicePartnership/pico-de-gallo/issues/20) |
| ☐  | [4.2 Target Power Output](#42-target-power-output) | [#21](https://github.com/OpenDevicePartnership/pico-de-gallo/issues/21) |
| ✅ | [4.3 Dedicated Connector Layout](#43-dedicated-connector-layout) | [#22](https://github.com/OpenDevicePartnership/pico-de-gallo/issues/22) — shipped in v1.1 |
| ☐  | [4.4 ESD Protection](#44-esd-protection) | [#23](https://github.com/OpenDevicePartnership/pico-de-gallo/issues/23) |
| ☐  | [4.5 Activity LEDs](#45-activity-leds) | [#24](https://github.com/OpenDevicePartnership/pico-de-gallo/issues/24) |
| ☐  | [4.6 Board Size and Mounting](#46-board-size-and-mounting) | [#25](https://github.com/OpenDevicePartnership/pico-de-gallo/issues/25) |

### 4.1 Voltage Level Translators

**Priority: CRITICAL — the single most impactful hardware change.**

**What:** Add bidirectional voltage level translators between the RP2350
(3.3 V) and the target connectors, with a user-selectable target voltage
(VREF) pin.

**Why:** The embedded world runs at many voltages:

| Voltage | Common Uses |
|---|---|
| 1.8 V | Modern SoCs, LPDDR interfaces, low-power sensors |
| 2.5 V | Some FPGAs, legacy parts |
| 3.3 V | Most microcontrollers, sensors, EEPROMs |
| 5.0 V | Arduino ecosystem, RS-232 level, automotive, legacy industrial |

Without level translators, pico-de-gallo is limited to 3.3 V targets.
This excludes a huge portion of the embedded ecosystem, especially:
- 5 V Arduino shields and legacy sensors
- 1.8 V modern SoC I2C buses (increasingly common)
- Mixed-voltage designs where the bridge must match the target

**Recommended parts:**

| Bus | Part | Notes |
|---|---|---|
| I2C | **PCA9306** or **TXS0102** | Bidirectional, open-drain compatible, designed for I2C. Do NOT use TXB0108 for I2C — it fights the open-drain pull-ups. |
| SPI / GPIO | **TXB0108** or **SN74LVC8T245** | Unidirectional or auto-direction. The SN74LVC8T245 is more predictable for high-speed SPI. |
| UART | **SN74LVC2T45** | 2-channel, dual-supply. TX is always host→target, RX is target→host, so direction is fixed. |

**Design approach:**
- Add a **VREF pin** on the target connector. The user supplies target
  voltage on this pin (or a jumper selects from 3.3 V / 5 V).
- Level translators reference VREF on the target side and 3.3 V on the
  RP2350 side.
- If VREF is not supplied, the translators can be powered from the
  on-board 3.3 V rail (passthrough mode, no translation).

### 4.2 Target Power Output

**What:** Provide switchable 3.3 V and 5 V power outputs to power small
target boards directly from USB.

**Why:** When prototyping with a single sensor or small target board,
needing a separate power supply is friction. The Total Phase Aardvark
provides target power and it's one of its most-loved features.

**Implementation:**
- **5 V:** Directly from USB VBUS through a current-limited switch
  (e.g., TPS2051B, 500 mA limit).
- **3.3 V:** From the Pico 2's on-board regulator or a dedicated LDO,
  also current-limited.
- **Control:** A GPIO pin enables/disables target power via firmware. Add
  a `power/enable` endpoint.
- **Protection:** Include a polyfuse or electronic fuse to protect against
  target short circuits.

**Budget:** USB 2.0 provides 500 mA total. The Pico 2 itself draws
~30–50 mA. Safely offer 200–300 mA to targets.

### 4.3 Dedicated Connector Layout

**What:** Redesign the connector layout with labeled, purpose-specific
headers:

| Connector | Type | Pins |
|---|---|---|
| **I2C** | JST SH 4-pin (Qwiic/STEMMA QT compatible) | VCC, GND, SDA, SCL |
| **SPI** | 2×4 pin header | VCC, GND, SCK, MOSI, MISO, CS0, CS1, CS2 |
| **UART**  | 1×4 pin header | VCC, GND, TX, RX |
| **GPIO**  | 2×5 pin header | 8× GPIO + GND + VREF |
| **ADC** | 1×6 pin header | 4× ADC channels + GND + VREF |
| **PWM** | 1×4 pin header | 2–4× PWM outputs + GND |
| **Power** | 1×3 pin header | 5V, 3.3V, GND |

**Why the Qwiic/STEMMA QT connector matters:** The JST SH 4-pin I2C
connector is a de facto standard in the maker/prototyping ecosystem.
SparkFun (Qwiic) and Adafruit (STEMMA QT) both use it. Adding one means
users can plug in any Qwiic/STEMMA sensor board with a single cable — no
wiring, no breadboard.

### 4.4 ESD Protection

**What:** Add ESD protection diodes (e.g., TPD4E05U06 for 4-channel, or
PRTR5V0U2X for USB/I2C) on all external-facing signal lines.

**Why:** USB bridges get plugged and unplugged constantly, often into
unknown targets. A single ESD event can destroy the RP2350. This is
table stakes for any tool that's meant to be handled daily.

**Cost:** Negligible — TVS diode arrays are $0.10–0.30 each.

### 4.5 Activity LEDs

**What:** Add per-bus activity LEDs:

| LED | Color | Indicates |
|---|---|---|
| Power | Green | Board powered |
| USB | Blue | USB enumerated |
| I2C | Yellow | I2C bus activity |
| SPI | Orange | SPI bus activity |
| UART  | Red | UART TX/RX activity |
| Error | Red (blink) | Last operation failed |

**Why:** Visual feedback is surprisingly important for debugging. "Is it
even talking to the bus?" is a question users ask constantly. A quick
glance at blinking LEDs answers it immediately.

**Implementation:** Use remaining GPIOs to drive LEDs. The firmware
toggles them in the endpoint handlers. Total current draw: ~12 mA for
6 LEDs at 2 mA each.

### 4.6 Board Size and Mounting

**What:** Consider whether the case design needs updating for the new
connectors. The current design uses M3 mounting holes; keep those but
potentially expand the PCB footprint to accommodate level translators and
additional connectors.

**Tradeoff:** A larger board costs more to fabricate and doesn't fit the
current 3D-printed case, but a cramped board with too-small connectors is
worse.

---

## Phase 5 — 1.0 Release Criteria

The 1.0 release should be declared when the items below are complete.
Each references the phase item where the work is tracked — check progress
there, not here.

### Must Have (1.0 blockers)

| Requirement | Phase Item |
|---|---|
| All `embedded-hal` 1.0 sync + async traits implemented | 1.2, 2.2 |
| `embedded-io` Read/Write for UART | 2.1 |
| Rich error types mapping firmware errors to `ErrorKind` | 1.1 |
| I2C bus scan | 1.3 |
| GPIO direction + pull configuration | 1.4 |
| UART support (at least one UART) | 2.1 |
| Configuration query endpoints | 1.5 |
| All public API types documented with rustdoc | — (ongoing)|
| Book updated with all interfaces and examples | — (ongoing)|
| Stable wire protocol (no breaking serialization changes after 1.0) | — (policy) |

### Should Have (target for 1.0, can slip)

| Requirement | Phase Item |
|---|---|
| PWM support | 2.2 |
| ADC support (at least single-shot reads) | 2.3 |
| GPIO event topics | 3.1 |
| I2C transaction batching | 3.2 |
| 10-bit I2C addressing | 2.4 |
| CLI app with bus scan, UART terminal, interactive GPIO | — (app work) |

### Nice to Have (post-1.0)

| Requirement | Phase Item |
|---|---|
| 1-Wire via PIO | 3.3 |
| Protocol sniffing | 3.4 |
| Configuration persistence | 3.5 |
| Multi-device host support | 3.6 |
| SPI target mode | — (future) |
| Hardware Rev 2 features | Phase 4 |

---

## Should the RP2350 Stay?

**Short answer: Yes.**

### The Case For RP2350

| Factor | Assessment |
|---|---|
| **Price** | ~$1 chip, ~$5 Pico 2 board. Unbeatable. |
| **Embassy support** | First-class. Active upstream development. |
| **Peripheral set**  | 2× I2C, 2× SPI, 2× UART, 12× PWM, 4× ADC, 3× PIO — more than enough. |
| **PIO** | Unique advantage. Enables 1-Wire, protocol sniffing, custom protocols. No competitor at this price has anything similar. |
| **SRAM** | 520 KB. Plenty for USB buffers and protocol state. |
| **Dual-core** | Available if needed for parallel bus monitoring. |
| **Community** | Huge Raspberry Pi ecosystem. Easy to source globally. |
| **Tooling** | UF2 flashing, SWD debug, picotool — all mature. |

### The USB Full Speed Question

The RP2350 only supports USB Full Speed (12 Mbps). In practice, bulk
transfers achieve ~700 KB/s to ~1 MB/s. Is this a problem?

**For I2C:** No. I2C Fast+ (the fastest mode pico-de-gallo supports) runs
at 1 MHz = 125 KB/s. USB FS has 5–8× headroom.

**For SPI:** Marginal. SPI at 8 MHz full-duplex = 1 MB/s, which is right
at the USB FS ceiling. For sustained streaming (e.g., display refresh),
USB becomes the bottleneck. For transactional workloads (register reads,
EEPROM pages), it's fine because the per-transfer overhead dominates
anyway.

**For UART:** No. Even at 921600 baud, that's only ~92 KB/s. Trivial for
USB FS.

**For ADC:** Depends on sample rate. Single-shot reads are fine.
Continuous streaming at 500 ksps × 12-bit = 750 KB/s — right at the
limit. A practical continuous mode would need to decimate or buffer.

**For protocol sniffing:** USB FS is the real constraint. I2C sniffing is
comfortable; SPI sniffing at high clock rates would need on-device
buffering and burst transfers.

**The Total Phase Aardvark also uses USB Full Speed** and is the industry
standard at $375. If it's good enough for professional engineers paying
$375, it's good enough for pico-de-gallo.

### What Would USB High Speed Buy?

If USB HS were critical, the alternatives are:

| MCU | USB | Price | Embassy Support | Notes |
|---|---|---|---|---|
| **STM32F723** | HS with internal PHY | ~$8 | Yes (embassy-stm32) | Rare chip with built-in HS PHY. Limited availability. |
| **STM32H7xx** | HS with external ULPI PHY | ~$12 + $3 PHY | Yes (embassy-stm32) | Complex layout, BGA packages, 4+ layer PCB. |
| **ESP32-S3** | FS only | ~$3 | No (no embassy) | Same FS limitation, worse ecosystem. |
| **NXP i.MX RT** | HS with internal PHY | ~$10 | Experimental | Overkill. Cortex-M7, complex clock tree. |

**Verdict:** Moving to USB HS would 3-5× the BOM cost, require a 4-layer
PCB, and add significant design complexity — all for a throughput gain
that only matters in a few niche scenarios (continuous high-speed SPI
streaming, high-rate ADC capture). The RP2350's PIO capability, price,
and Embassy support make it the right choice for a tool focused on
driver development and hardware prototyping.

**Recommendation:** Keep RP2350. If a "Pro" variant is ever warranted,
the STM32F723 (HS PHY built-in) would be the most practical upgrade path,
but that's a separate product, not a replacement.

---

## Appendix A — embedded-hal Trait Coverage Matrix

| Trait | Crate | Blocking | Async | Status |
|---|---|---|---|---|
| `I2c<SevenBitAddress>` | `embedded-hal` | ✅ | ✅ | Done |
| `I2c<TenBitAddress>` | `embedded-hal` | ❌ | ❌ | Phase 2.4 |
| `SpiBus` | `embedded-hal` | ✅ | ✅ | Done |
| `SpiDevice` | `embedded-hal` | ✅ | ✅ | Done |
| `InputPin` | `embedded-hal` | ✅ | — | Done |
| `OutputPin` | `embedded-hal` | ✅ | — | Done |
| `StatefulOutputPin` | `embedded-hal` | ✅ | — | Done |
| `Wait` | `embedded-hal-async` | — | ✅ | Done |
| `DelayNs` | `embedded-hal` | ✅ | ✅ | Done |
| `SetDutyCycle` | `embedded-hal` | ✅ | — | Done |
| `Read` | `embedded-io` | ✅ | ✅ | Done |
| `Write` | `embedded-io` | ✅ | ✅ | Done |
| `ReadReady` | `embedded-io` | ❌ | — | Future |
| `WriteReady` | `embedded-io` | ❌ | — | Future |

**At 1.0:** every cell should be ✅ or have a documented reason for
exclusion.

---

## Appendix B — Competitive Landscape

| Feature | Pico de Gallo (current) | Pico de Gallo (1.0 target) | Total Phase Aardvark ($375) | FTDI FT2232H (~$30) | Bus Pirate (~$40) | MCP2221A (~$5) |
|---|---|---|---|---|---|---|
| **I2C** | ✅ (+ scan, batch) | ✅ (+ 10-bit) | ✅ (+ slave) | ✅ (MPSSE) | ✅ | ✅ |
| **SPI** | ✅ (+ SpiDevice) | ✅ | ✅ (+ slave) | ✅ (MPSSE) | ✅ | ❌ |
| **UART** | ✅ | ✅ | ❌ | ✅ (dual) | ✅ | ✅ |
| **GPIO** | ✅ (8 pins) | ✅ | ✅ (6 pins) | ✅ (limited) | ✅ | ✅ (4 pins) |
| **PWM** | ✅ | ✅ | ✅ | ✅ | ✅ | ✅ |
| **ADC** | ✅ (4-ch, 12-bit) | ✅ | ❌ | ❌ | ✅ | ✅ (3-ch) |
| **1-Wire** | ✅ (PIO) | ✅ | ❌ | ❌ | ✅ | ❌ |
| **Level shift**  | ❌ | Rev 2 | ❌ (accessory) | ❌ (5V tolerant) | ✅ | ❌ |
| **Target power** | ❌ | Rev 2 | ✅ | ❌ | ✅ | ❌ |
| **embedded-hal** | ✅ | ✅ (complete) | ❌ | ❌ | ❌ | ❌ |
| **Rust-native**  | ✅ | ✅ | ❌ | ❌ | ❌ | ❌ |
| **USB speed** | FS | FS | FS | HS | FS | FS |
| **Open source**  | ✅ | ✅ | ❌ | ❌ | ✅ | ❌ |
| **Price** | ~$5 | ~$10–15 (Rev 2) | $375 | ~$30 | ~$40 | ~$5 |

**Unique differentiators at 1.0:**
1. Only bridge with native `embedded-hal` trait support
2. Only bridge that's both open-source hardware AND Rust-native
3. Price/feature ratio competitive with Bus Pirate, with far better
   Rust integration
4. PIO enables custom protocols no other bridge at this price can match

---

## Appendix C — RP2350 Peripheral Budget

The RP2350 (as used on Pico 2) has the following peripherals. This table
shows current usage and planned allocation:

| Peripheral | Total Available | Currently Used | Planned (1.0) | Notes |
|---|---|---|---|---|
| **I2C** | 2 (I2C0, I2C1) | 1 (I2C1) | 1 | Second bus dropped |
| **SPI** | 2 (SPI0, SPI1) | 1 (SPI0) | 1 | Second bus dropped |
| **UART** | 2 (UART0, UART1)  | 1 (UART0) | 1 (UART0) | GPIO0/1 |
| **PWM** | 12 slices (24 ch) | 4 slices | 4 slices | GPIO8–15, PWM slices 4–7 |
| **ADC** | 4 GPIO | 4 (GPIO26–29) | 4 GPIO | GPIO26–29 |
| **PIO** | 3 (PIO0–2) | 1 (1-Wire) | 1–2 | 1-Wire, sniffing |
| **DMA** | 16 channels | 2 (SPI) | 4–6 | ADC continuous, UART, SPI |
| **GPIO** | 30 (on Pico 2) | 10 (I2C: 2, SPI: 3, user: 8, USB: ~0) | ~24 | Plenty of headroom |
| **USB** | 1 (FS) | 1 | 1 | Fully committed |
| **Flash**  | 4 MB (on Pico 2)  | ~256 KB firmware | ~256 KB + config | Config persistence in reserved sector |
| **SRAM** | 520 KB | ~64 KB (estimated) | ~128 KB | Buffer growth for batching/ADC |

**Conclusion:** The RP2350 has substantial unused peripheral capacity.
We can implement every feature in this roadmap without running out of
resources. The main constraint is USB bandwidth, not peripheral count.

---

## Summary

The path to 1.0 is primarily a **software effort**. The RP2350 hardware
is capable of far more than we currently use. The recommended sequence:

1. **Phase 1** (polish) — can start immediately, mostly non-breaking
2. **Phase 2** (new protocols) — the big value add; UART is the priority
3. **Phase 3** (advanced) — differentiating features; topics and batching
   have the highest impact
4. **Phase 4** (hardware) — plan the Rev 2 board in parallel with Phase 2
   software work; order prototypes during Phase 3
5. **Phase 5** (release) — 1.0 when all must-have criteria are met

The hardware re-spin should be done **once** with all changes in this
document. Level translators and ESD protection are the non-negotiable
additions. Target power and the Qwiic connector are high-value, low-cost
additions that should be included. Activity LEDs are nice to have if board
space permits.

The RP2350 is the right MCU. Keep it.

---

## Conventions — How to Update This File

### Checking off items

When a phase item is complete, update its row in the phase summary table:

```
| ☑ | [1.3 I2C Bus Scan](#13-i2c-bus-scan-endpoint) | #42 |
```

Then update the [Progress Overview](#progress-overview) table: increment
the "Done" column and update the status emoji:

- 🔴 Not started (0 done)
- 🟡 In progress (some done)
- 🟢 Complete (all done)

### Linking issues and PRs

Use the **Tracking** column to record the GitHub issue or PR number that
implements the item. Use `#N` format for issues/PRs in this repo:

```
| ☐ | [2.1 UART Support](#21-uart-support) | #57, #63 |
```

### Adding new items

If a new work item is discovered:

1. Add it to the appropriate phase as a new subsection (e.g., `### 2.7 ...`)
2. Add a row to that phase's summary table
3. Update the item count in the Progress Overview
4. If it's a 1.0 requirement, add a row to Phase 5

### Updating the date

Update the `> Last updated:` line at the top whenever you commit changes
to this file.

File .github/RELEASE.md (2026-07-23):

# Release process (manual)

Releases in this repository are performed **by hand**. There is no
release automation: no release-please, no bots opening release PRs,
no auto-generated CHANGELOG. A maintainer bumps versions, writes the
CHANGELOG, merges to `main`, and pushes tags. The tag-triggered
publish workflows then take over.

> **Why manual?** The release-please setup caused repeated,
> hard-to-diagnose problems (version/manifest drift that silently
> disabled releases, seven-PR fan-out per cycle, plugin interaction
> bugs). We traded automation for a small, explicit checklist that a
> human runs and can reason about.

## What is still automated

Tag-triggered workflows fire on pushed tags — these are unchanged and
remain the publish mechanism:

| Workflow | Tag trigger | Produces |
|---|---|---|
| `release-crates.yml` | `internal-v*`, `library-v*`, `hal-v*`, `ffi-v*`, `application-v*` | `cargo publish` to crates.io |
| `release-application.yml` | `application-v*` | `gallo` binaries (Linux/Windows/macOS) |
| `release-ffi.yml` | `ffi-v*` | `.so` / `.dll` / `.dylib` + C header |
| `release-firmware.yml` | `firmware-v*` (and PRs, build-only) | `.uf2` + `.elf` |
| `release-pyco.yml` | `pyco-v*` | Python wheels (attached to GitHub Release)  |
| `release-hardware.yml` | `hardware-v*` | KiCad gerbers, schematic PDF |

You create the tag; the workflow does the rest. **Creating and
pushing the tag is now a manual step** (release-please used to create
it when a release PR merged).

## Source of truth

Each crate's `[package].version` in its own `Cargo.toml` is the
single source of truth for that crate's version. There is no manifest
file to keep in sync anymore. Edit the version directly.

## Tag conventions

| Crate | Tag prefix | Publishes to |
|---|---|---|
| `pico-de-gallo-internal` | `internal-v*` | crates.io |
| `pico-de-gallo-lib` | `library-v*` | crates.io |
| `pico-de-gallo-hal` | `hal-v*` | crates.io |
| `pico-de-gallo-ffi` | `ffi-v*` | crates.io |
| `gallo` (CLI) | `application-v*` | crates.io + binaries|
| `pyco-de-gallo` | `pyco-v*` | PyPI (wheels) |
| `pico-de-gallo-firmware` | `firmware-v*` | `.uf2` / `.elf` |
| KiCad gerbers | `hardware-v*` | gerbers / PDF |

Common typos that break a release: `lib-v*` (it's `library-v*`),
`app-v*` (it's `application-v*`), `fw-v*` (it's `firmware-v*`). The
tag prefix is `library`/`application`, not the crate directory name.

## Cross-crate dependency graph

Bumping a crate that others depend on means bumping the dependents'
`version = "..."` dep specs too (there is no `cargo-workspace` plugin
rewriting them anymore):

```text
internal ──► lib ──► hal
                 ├─► ffi
                 ├─► application (gallo)
                 └─► pyco
internal ──► firmware        (separate workspace)
```

crates.io publish order is therefore: `internal → lib → {hal, ffi,
application}`. `pyco` publishes to PyPI (not crates.io); `firmware`
produces artifacts only.

## Wire-protocol lockstep invariant

`pico-de-gallo-internal`'s `[package].version` is reflected at runtime
via `SCHEMA_VERSION_{MAJOR,MINOR,PATCH}` (auto-generated by
`build.rs` — do not hand-edit those constants). When the wire
protocol changes (see AGENTS.md §6):

- bump **`pico-de-gallo-internal`** (pre-1.0: minor bump for any wire
  change),
- bump **every other released component in the same release** so the
  firmware encodes the new schema version and every host surface sees
  the new types: `lib`, `hal`, `ffi`, `application`, `pyco`,
  `firmware`.

Nothing enforces this for you now — it is on the maintainer. A
version bump alone does not change the firmware's schema encoding;
the firmware source must carry the matching change.

## Step-by-step: cutting a release

Suppose you are releasing a wire-protocol change that bumps every
component. Adjust the crate set for a non-wire, single-crate release.

1. **Pick the new version(s).** Pre-1.0, a wire change is a minor
   bump on `internal` and every dependent (e.g. `0.6.0 → 0.7.0`). A
   non-wire fix is a patch bump on just the affected crate(s).

2. **Bump `[package].version`** in each crate's `Cargo.toml` that is
   part of this release.

3. **Bump cross-crate dep specs.** For every dependent, update the
   `version = "..."` in its `pico-de-gallo-* = { version = "...",
   path = "..." }` lines to match the new versions. Dependents:
   - `lib` → `internal`
   - `hal`, `ffi`, `application`, `pyco` → `lib`
   - `firmware` → `internal` (separate workspace — do not forget it)

4. **Update `CHANGELOG.md`** by hand, following
   [Keep a Changelog](https://keepachangelog.com/). Add a dated
   section per crate that changed. This is no longer generated — an
   empty or missing entry means the release ships undocumented.

5. **Regenerate both lockfiles** so they match the new versions:
   ```bash
   # host workspace (repo root)
   cargo update --workspace --locked
   # firmware workspace
   cd crates/pico-de-gallo-firmware
   cargo update -p pico-de-gallo-internal
   ```
   If `--locked` refuses because versions moved, drop it for the
   regeneration step, then verify with a locked check below.

6. **Verify both workspaces build locked:**
   ```bash
   cargo check --locked                                   # repo root
   cd crates/pico-de-gallo-firmware && \
     cargo check --locked --target thumbv8m.main-none-eabihf
   ```
   CI's `lockfile` job gates this; if it fails, the lock is out of
   sync with a `Cargo.toml`.

7. **Commit** everything together with a Conventional Commit, e.g.:
   ```text
   chore(release): internal/lib/hal 0.7.0, ffi/application 0.8.0, ...
   ```
   The version bumps, dep-spec bumps, both `Cargo.lock`s, and the
   `CHANGELOG.md` edits all belong in one commit.

8. **Open a PR, get CI green, merge to `main`** (rebase or
   merge-commit — no squash).

9. **Tag the merged commit** — one tag per released component, using
   the prefixes in the table above:
   ```bash
   git checkout main && git pull
   git tag internal-v0.7.0
   git tag library-v0.7.0
   git tag hal-v0.7.0
   git tag ffi-v0.8.0
   git tag application-v0.8.0
   git tag pyco-v0.5.0
   git tag firmware-v0.11.0
   git push upstream --tags
   ```
   For crates.io, push `internal-v*` first and wait ~60s for it to
   index before the dependents' tags, or expect to re-run the failed
   downstream publish jobs (crates.io indexing race — see
   `release-crates.yml`).

10. **Watch the release workflows.** Each `*-v*` tag fires its
    workflow. `release-crates.yml` publishes to crates.io;
    `release-pyco.yml` builds wheels; `release-firmware.yml` builds
    the `.uf2`/`.elf`. Re-run any job that lost the crates.io
    indexing race.

## Gotchas

- **Tag-triggered workflows use the workflow YAML as it existed at
  the tagged commit**, not tip-of-`main`. If you rewrite a release
  commit, delete and re-create the tag, and verify with
  `git show <tag>:.github/workflows/release-crates.yml`.
- **`CARGO_REGISTRY_TOKEN`** must have `publish-update` scope for the
  five published crate names (internal, lib, hal, ffi, gallo). The
  crates already exist; `publish-new` is not needed.
- **Don't forget the firmware.** It is a separate workspace with its
  own `Cargo.lock`; its `pico-de-gallo-internal` dep spec and lock
  entry must be bumped in the same release or CI's `lockfile` job
  fails.
- **`pyco-de-gallo` and `pico-de-gallo-firmware` are not on
  crates.io** (`publish = false` / artifact-only). Their tags drive
  PyPI wheels and firmware binaries respectively, not `cargo
  publish`.

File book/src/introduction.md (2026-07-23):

# Introduction

*Pico de Gallo* turns a [Raspberry Pi
Pico 2](https://www.raspberrypi.com/products/raspberry-pi-pico-2/)
into a USB-attached protocol bridge so you can drive **I²C, SPI,
UART, GPIO, PWM, ADC,** and **1-Wire** peripherals from a host PC —
and, more importantly, so you can develop and test embedded
device drivers **on your laptop**, with no flashing, no SWD probe,
no clock or pin-mux setup, and no linker scripts in your way.

If you've ever wanted to:

- prototype a driver against `embedded-hal` traits without booting
  an MCU each time you change a line,
- script a sensor or actuator from Python or a shell one-liner,
- write an integration test that talks to real silicon from your
  CI runner,

then *Pico de Gallo* is for you.

## What's in the Box

A small landing-board PCB with castellated pads for the Pico 2, a
firmware image that speaks
[postcard-rpc](https://docs.rs/postcard-rpc) over USB, and a small
constellation of host-side crates:

- **`gallo`** — a CLI for one-off and scripted access to every
  interface.
- **`pico-de-gallo-lib`** — an async Rust client built on
  [`nusb`](https://docs.rs/nusb) and `tokio`.
- **`pico-de-gallo-hal`** — a host-side
  [`embedded-hal`](https://docs.rs/embedded-hal) /
  [`embedded-hal-async`](https://docs.rs/embedded-hal-async) shim
  so existing drivers work unchanged.
- **`pico-de-gallo-ffi`** — a C shared library with a stable
  opaque-pointer API.
- **`pyco-de-gallo`** — Python bindings via PyO3 and maturin.

<table>
<tr>
<td align="center">Pico de Gallo rev1<br><em>Pico de Gallo v1.0</em></td>
<td align="center">Pico de Gallo rev1.1<br><em>Pico de Gallo v1.1</em></td>
</tr>
</table>

## Hardware Revisions at a Glance

| Revision | Firmware feature | Connector | Capabilities |
|---|---|---|---|
| **v1.0** | `hw-rev1` | seven pin headers | I²C, SPI, GPIO, PWM |
| **v1.1** | `hw-rev2` | one keyed 2×12 box | I²C, SPI, UART, GPIO, PWM, ADC, 1-Wire |
| v2 (WIP) | `hw-rev2` | 2×12 box + level Tx  | same as v1.1, plus variable VREF |

You'll want **v1.1 or later** if you need UART, ADC, or 1-Wire. See
[Revisions: v1.0 vs v1.1](./hardware/revisions.md).

## How to Read This Book

The book is laid out as six parts plus appendices:

1. **The Hardware** — what's on the PCB, which revision to pick,
   how to flash firmware.
2. **Getting Started** — install the toolchain and verify your
   device.
3. **The Interfaces** — one chapter per peripheral. Each follows
   the same template: overview, pin mapping, CLI usage, Rust,
   C, Python, error handling.
4. **The Crates** — reference for each crate in the workspace.
5. **Writing a Device Driver** — the longest part. A TMP102
   walkthrough showing the dev loop, the blocking/async parity, and
   how to write hardware-in-the-loop tests that run on your laptop.
6. **Under the Hood** — the wire protocol, schema versioning,
   firmware architecture, and the release cadence.

Read top-to-bottom for a tour, or jump straight to the chapter you
need — each chapter stands on its own.

## The Optional Case

A 3D-printable, snap-fit enclosure lives in the
[`case/`](https://github.com/OpenDevicePartnership/pico-de-gallo/tree/main/case)
folder of the repository if you want to keep the board safe on your
bench.

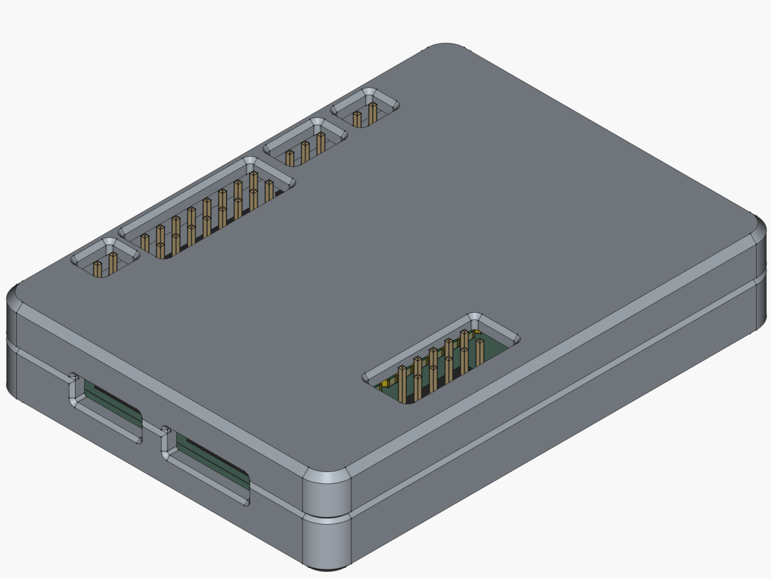
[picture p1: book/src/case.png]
3D printable case Pico de Gallo Case


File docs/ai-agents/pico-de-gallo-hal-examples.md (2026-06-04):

# Pico de Gallo HAL — AI Agent Guide

Audience: AI coding agents writing host-side examples or HIL tests that
exercise an `embedded-hal` driver against real hardware via a Pico de
Gallo USB bridge.

**Source of truth:** `crates/pico-de-gallo-hal/src/lib.rs` on `main`.
If this file contradicts that file, the source wins — file an issue at
<https://github.com/OpenDevicePartnership/pico-de-gallo/issues>.

## 1. TL;DR

You are generating either a host-side **example binary** at
`examples/<chip>.rs` or a **hardware-in-the-loop test** gated behind
`#[cfg(feature = "hil")]`. Both shapes exercise an `embedded-hal`
driver against real hardware through a Pico de Gallo USB bridge.

Decide which shape to produce (§2), pick blocking or async (§3), set
up `Cargo.toml` (§4), look up which HAL accessor your device needs
(§5 decision tree → §6 per-peripheral reference), drop a fixed-format
decision-log header at the top of the generated file (format defined
in §7), and verify against the checklist in §8.

The HAL exposes I²C, SPI, GPIO, PWM, ADC, 1-Wire, UART, and Delay.
Pin range for any GPIO is **0..=3** (the firmware only exposes four
pins). The HAL is `pico-de-gallo-hal` on crates.io.

## 2. Output-shape rule (binary vs. HIL test)

**Default: binary at `examples/<chip>.rs`.**

Pick **HIL test** (`#[cfg(feature = "hil")] #[test]` inside a driver
crate, gated behind a `hil` Cargo feature) only when **at least one**
of these is true:

- The user explicitly says "test", "validate the driver", "regression
  test", "CI", or "hardware-in-the-loop".
- The user names an existing driver crate they want regression
  coverage for.

Otherwise produce the binary. "Show me X works", "make X blink",
"read a value from X", and bring-up scripts are all binary requests.

If both shapes seem to fit, default to binary; binaries are easier to
run by hand and the user can always wrap one in a test later.

The HIL-test shape pattern is:

```rust
#[cfg(feature = "hil")]
#[test]
fn <chip>_<assertion>() {
    let hal = pico_de_gallo_hal::Hal::new();
    // ... assert something the user would actually want to know
    //     is true for their hardware ...
}
```

Gate it in the driver crate's `Cargo.toml`:

```toml
[features]
default = []
hil = ["dep:pico-de-gallo-hal"]

[dev-dependencies]
pico-de-gallo-hal = { version = "*", optional = true }
```

## 3. Sync-vs-async rule

Selection algorithm, in order:

1. If the driver crate's primary API is `async fn` → **async**
   (`#[tokio::main]`).
2. If the driver crate's primary API is blocking → **blocking**.
3. If the driver crate offers both → **blocking** (simpler).
4. If the example needs GPIO edge waits (the `Wait` trait:
   `wait_for_falling_edge`, etc.) → **async** regardless of (1)–(3).
5. If both async edge waits **and** blocking driver methods are
   needed → **async**. The HAL's `block_in_place` plumbing lets
   blocking trait calls run inside a tokio task, **but read the
   warning below first**.

> ### ⚠ Mandatory: never use `current_thread` tokio
>
> If you pick async, you MUST use the **default multi-thread**
> tokio runtime:
>
> - `#[tokio::main]` — correct.
> - `#[tokio::main(flavor = "current_thread")]` — **will panic**
>   the first time a driver issues a blocking I²C, SPI, GPIO,
>   UART, PWM, ADC, or 1-Wire call.
>
> The HAL detects "in async context" but cannot detect runtime
> flavor (see the private `in_async_context` helper at `lib.rs:463`),
> so it unconditionally calls `tokio::task::block_in_place`, which
> tokio documents as panicking on single-threaded runtimes.

Default tokio dep when async is chosen:

```toml
tokio = { version = "1", features = ["rt-multi-thread", "macros", "time"] }
```

Do **not** add `"current_thread"` to the feature list and do **not**
override the flavor.

## 4. Cargo setup

This file does not pin versions. Resolve current versions from
crates.io when you edit `Cargo.toml`. The crates you need are:

- `pico-de-gallo-hal` — the HAL itself. Goes in `[dependencies]` for
  binaries, `[dev-dependencies]` (optional, gated by the `hil`
  feature) for HIL tests.
- `embedded-hal` — required if your driver returns
  `embedded_hal::*::Error` types.
- `embedded-hal-async` — required only if you use async traits
  (`embedded_hal_async::digital::Wait`, etc.).
- `tokio` — required only if async, with features
  `["rt-multi-thread", "macros", "time"]`. **Do not** pick
  `current_thread` — see §3.
- `pico-de-gallo-lib` — required directly only when you need
  `PicoDeGallo::uart_set_config` (UART baud-rate setter; not on the
  HAL). As of HAL 0.7, `AdcChannel`, `AdcConfigurationInfo`,
  `GpioDirection`, `GpioEdge`, and `GpioPull` are re-exported by
  `pico_de_gallo_hal` and no longer require depending on the lib
  directly.
- The driver crate(s) for the device you're exercising.

Re-exported by `pico_de_gallo_hal` (no extra dependency needed):
`AdcChannel`, `AdcConfigurationInfo`, `GpioDirection`, `GpioEdge`,
`GpioEvent`, `GpioPull`, `I2cFrequency`, `SpiConfigurationInfo`,
`SpiPhase`, `SpiPolarity`, `UartConfigurationInfo`.

## 5. Peripheral decision tree

| Your device… | Jump to |
|---|---|
| Talks I²C (sensor, EEPROM, expander) | §6.1 |
| Talks SPI, driver manages CS itself | §6.2 |
| Talks SPI, you provide a CS pin (typical) | §6.3 |
| Is an LED, relay, or reset line (drives a level) | §6.4 |
| Is a button or switch you poll | §6.5 |
| Is a button you wait on (edge-triggered) | §6.6 |
| Needs streamed edge events (rotary encoder, etc.) | §6.7 |
| Is a motor or LED needing a duty cycle | §6.8 |
| Is an analog input (potentiometer, thermistor) | §6.9 |
| Is a 1-Wire device (DS18B20, DS2401) | §6.10 |
| Talks UART or serial | §6.11 |
| The driver needs `&mut impl DelayNs` | §6.12 |

Most drivers combine 2–3 of these (e.g. SPI device + GPIO output for
reset + Delay). Pull each one in from its subsection independently.

## 6. Per-peripheral reference

### 6.1 I²C

**When to use:** the device is on an I²C bus and uses 7-bit addressing.

**HAL accessor:** `hal.i2c()` → returns `I2c`.

**Traits implemented:** `embedded_hal::i2c::I2c`,
`embedded_hal_async::i2c::I2c`.

#### Snippet — binary form

```rust
// examples/<chip>.rs
// pico-de-gallo decision log:
//   shape:        binary
//   sync/async:   sync (reason: driver is blocking)
//   peripherals:  i2c
//   hal version:  <crate version observed at generation time>

use embedded_hal::i2c::I2c;
use pico_de_gallo_hal::Hal;

fn main() {
    let hal = Hal::new();
    let mut i2c = hal.i2c();

    let mut buf = [0u8; 2];
    i2c.write_read(0x48, &[0x00], &mut buf).unwrap();
    println!("raw: {:02x?}", buf);
}
```

#### Snippet — HIL-test form

```rust
#[cfg(feature = "hil")]
#[test]
fn tmp102_responds_on_default_address() {
    use embedded_hal::i2c::I2c;
    let hal = pico_de_gallo_hal::Hal::new();
    let mut i2c = hal.i2c();
    let mut buf = [0u8; 2];
    // A successful write_read with an ACK proves the device is wired.
    i2c.write_read(0x48, &[0x00], &mut buf).unwrap();
}
```

#### Gotchas

- 7-bit addressing only. Pass `0x48`, not `0x90`.
- `I2c::transaction()` (and `write_read`) is batched as a single USB
  round-trip by the HAL — prefer it over separate `write` + `read`.
- Default bus frequency is 100 kHz. Bump with
  `hal.i2c_set_config(I2cFrequency::Fast)?` for 400 kHz or
  `I2cFrequency::FastPlus` for 1 MHz.
- Async usage: see §3 for the mandatory `current_thread` warning.

#### Config knobs

- `hal.i2c_set_config(I2cFrequency)` — bus frequency. Default
  `Standard` (100 kHz). Variants: `Standard`, `Fast`, `FastPlus`.
- `hal.i2c_get_config() -> Result<I2cFrequency, _>` — read current
  frequency.
- `hal.i2c_scan(include_reserved: bool) -> Result<Vec<u8>, _>` —
  scan for devices. `false` scans `0x08..=0x77`, `true` scans the
  full `0x00..=0x7F`.

### 6.2 SPI bus (no CS)

**When to use:** rarely — only when the driver crate manages chip
select itself (passes its own GPIO handle, talks to a non-CS device,
or daisy-chains). Otherwise prefer §6.3.

**HAL accessor:** `hal.spi()` → returns `Spi`.

**Traits implemented:** `embedded_hal::spi::SpiBus`,
`embedded_hal_async::spi::SpiBus`.

```rust
use embedded_hal::spi::SpiBus;
use pico_de_gallo_hal::Hal;

fn main() {
    let hal = Hal::new();
    let mut spi = hal.spi();

    let tx = [0xAA, 0x55];
    let mut rx = [0u8; 2];
    spi.transfer(&mut rx, &tx).unwrap();
    println!("rx: {:02x?}", rx);
}
```

#### Gotchas

- No automatic CS. The bus is always live.
- Config knobs are shared with §6.3: `hal.spi_set_config(...)` and
  `hal.spi_get_config()`.
- Async usage: see §3 for the mandatory `current_thread` warning.

### 6.3 SPI device (with CS)

**When to use:** the device is on an SPI bus and you provide a GPIO
pin as chip-select. This is the common case — most drivers expect an
`SpiDevice` that wraps CS handling for them.

**HAL accessor:** `hal.spi_device(cs_pin)` → returns
`Result<SpiDev, SpiHalError>`. CS pin range: `0..=3`.

**Traits implemented:** `embedded_hal::spi::SpiDevice`,
`embedded_hal_async::spi::SpiDevice`.

#### Snippet — binary form

```rust
// examples/<chip>.rs
// pico-de-gallo decision log:
//   shape:        binary
//   sync/async:   sync (reason: driver is blocking)
//   peripherals:  spi_device(cs=0)
//   hal version:  <crate version observed at generation time>

use pico_de_gallo_hal::Hal;
use <driver_crate>::Driver;

fn main() {
    let hal = Hal::new();
    let spi = hal.spi_device(0).expect("spi_device failed");
    let mut driver = Driver::new(spi);
    // ... use driver ...
}
```

#### Snippet — HIL-test form

```rust
#[cfg(feature = "hil")]
#[test]
fn driver_who_am_i_matches_datasheet() {
    let hal = pico_de_gallo_hal::Hal::new();
    let spi = hal.spi_device(0).unwrap();
    let mut driver = <DriverCrate>::new(spi);
    assert_eq!(driver.who_am_i().unwrap(), 0xAB);
}
```

#### Gotchas

- CS pin range is `0..=3`. The pin **must not** also be used as a
  `Gpio` elsewhere in the program (no concurrent ownership).
- The async `SpiDevice::transaction` is **not** cancellation-safe:
  if the future is dropped after CS is asserted low but before it is
  deasserted, CS stays low. Match the behavior of
  `embedded-hal-bus::ExclusiveDevice`.
- `Operation::TransferInPlace(buf)` works, but the implementation
  allocates a `Vec` the same size as `buf` per occurrence in a
  transaction. For large in-place transfers prefer
  `Operation::Transfer(read, write)` with two buffers.
- Async usage: see §3 for the mandatory `current_thread` warning.

#### Config knobs

- `hal.spi_set_config(freq_hz, SpiPhase, SpiPolarity)` — clock
  frequency, phase, polarity. Defaults: 1 MHz,
  `SpiPhase::CaptureOnFirstTransition`, `SpiPolarity::IdleLow`
  (mode 0).
- `hal.spi_get_config() -> Result<SpiConfigurationInfo, _>` — read
  back current configuration.

### GPIO subsections (§§6.4–6.7) — read first

**Pin range:** `0..=3` (firmware exposes four pins). Any pin number
outside this range returns `GpioError::InvalidPin`.

**Pin state machine** — at any moment a pin is in exactly one of
these states, and only the listed ops are valid:

| State | Reached by | Allowed ops |
|---|---|---|
| Unconfigured | freshly-booted firmware | `Gpio::set_config(...)` only |
| Output | `set_config(GpioDirection::Output,_)` | `OutputPin::set_low/high`, `StatefulOutputPin::is_set_low/high`|
| Input | `set_config(GpioDirection::Input,_)`  | `InputPin::is_low/high`, async `Wait::wait_for_*` |
| Subscribed (Input) | `hal.gpio_subscribe(pin, edge)` | receive `GpioEvent`s; **no other ops** until `gpio_unsubscribe`|

Cross-state transitions: call `set_config(...)` again to flip
direction; call `gpio_unsubscribe(pin)` to leave Subscribed. **A pin
that is Subscribed cannot also be wait()'d on or read/written**: the
firmware returns `GpioError::PinMonitored`.

`use pico_de_gallo_hal::{GpioDirection, GpioPull, GpioEdge};` —
re-exported from `pico-de-gallo-lib` (HAL 0.7+).

### 6.4 GPIO output

**When to use:** drive a line high or low — LED, relay, reset line,
manual CS pin (only if you're **not** using `hal.spi_device(cs)`).

**HAL accessor:** `hal.gpio(pin)` → returns `Gpio`. Pin range
`0..=3`.

**Traits implemented:** `embedded_hal::digital::OutputPin`,
`embedded_hal::digital::StatefulOutputPin`.

#### Snippet — binary form

```rust
// examples/blink.rs
// pico-de-gallo decision log:
//   shape:        binary
//   sync/async:   sync (reason: trivial blocking loop)
//   peripherals:  gpio(0)
//   hal version:  <crate version observed at generation time>

use embedded_hal::digital::OutputPin;
use pico_de_gallo_hal::Hal;
use pico_de_gallo_hal::{GpioDirection, GpioPull};
use std::time::Duration;

fn main() {
    let hal = Hal::new();
    let mut gpio = hal.gpio(0);
    gpio.set_config(GpioDirection::Output, GpioPull::None).unwrap();

    loop {
        gpio.set_high().unwrap();
        std::thread::sleep(Duration::from_secs(1));
        gpio.set_low().unwrap();
        std::thread::sleep(Duration::from_secs(1));
    }
}
```

#### Gotchas

- Pin range `0..=3`.
- Call `set_config(Output, _)` before driving the pin — pins boot
  unconfigured.
- The CS pin you pass to `hal.spi_device(cs)` is **not** usable here.
  Don't share pin numbers.
- Async usage: see §3 for the mandatory `current_thread` warning.

#### Config knobs

- `Gpio::set_config(GpioDirection, GpioPull)` — direction + internal
  pull resistor. Variants: `GpioDirection::{Input, Output}`,
  `GpioPull::{None, Up, Down}`. Default after firmware boot: input,
  no pull.

### 6.5 GPIO input

**When to use:** poll a digital line — a switch, a status pin, a
strap.

**HAL accessor:** `hal.gpio(pin)` → returns `Gpio`. Pin range
`0..=3`.

**Traits implemented:** `embedded_hal::digital::InputPin`.

#### Snippet — binary form

```rust
// examples/<chip>.rs
// pico-de-gallo decision log:
//   shape:        binary
//   sync/async:   sync (reason: polled, no edge wait)
//   peripherals:  gpio(1)
//   hal version:  <crate version observed at generation time>

use embedded_hal::digital::InputPin;
use pico_de_gallo_hal::Hal;
use pico_de_gallo_hal::{GpioDirection, GpioPull};

fn main() {
    let hal = Hal::new();
    let mut button = hal.gpio(1);
    button.set_config(GpioDirection::Input, GpioPull::Up).unwrap();

    if button.is_low().unwrap() {
        println!("button pressed");
    }
}
```

#### Snippet — HIL-test form

```rust
#[cfg(feature = "hil")]
#[test]
fn strap_pin_reads_low_with_pullup() {
    use embedded_hal::digital::InputPin;
    use pico_de_gallo_hal::{GpioDirection, GpioPull};
    let hal = pico_de_gallo_hal::Hal::new();
    let mut pin = hal.gpio(2);
    pin.set_config(GpioDirection::Input, GpioPull::Up).unwrap();
    // Strapped low → pull-up loses, pin reads low.
    assert!(pin.is_low().unwrap());
}
```

#### Gotchas

- Pin range `0..=3`.
- Default pull is `None`. For a button-to-ground use
  `GpioPull::Up`; for a button-to-VCC use `GpioPull::Down`.
- For edge-triggered waiting use §6.6; for streamed events §6.7.
- Async usage: see §3 for the mandatory `current_thread` warning.

### 6.6 GPIO async wait

**When to use:** block the current async task until a GPIO edge or
level happens. Common for button presses, IRQ lines from sensors,
SPI BUSY/READY pins. **This subsection is the only reason most
examples need to be async.**

**HAL accessor:** `hal.gpio(pin)` → returns `Gpio`. Pin range
`0..=3`.

**Traits implemented:** `embedded_hal_async::digital::Wait` —
methods `wait_for_high`, `wait_for_low`, `wait_for_rising_edge`,
`wait_for_falling_edge`, `wait_for_any_edge`.

#### Snippet — binary form

```rust
// examples/button.rs
// pico-de-gallo decision log:
//   shape:        binary
//   sync/async:   async (reason: GPIO Wait trait is async-only)
//   peripherals:  gpio(0)
//   hal version:  <crate version observed at generation time>

use embedded_hal_async::digital::Wait;
use pico_de_gallo_hal::Hal;
use pico_de_gallo_hal::{GpioDirection, GpioPull};

#[tokio::main]               // multi-thread — DO NOT use current_thread
async fn main() {
    let hal = Hal::new();
    let mut button = hal.gpio(0);
    button.set_config(GpioDirection::Input, GpioPull::Up).unwrap();

    loop {
        button.wait_for_falling_edge().await.unwrap();
        println!("pressed");
        button.wait_for_rising_edge().await.unwrap();
        println!("released");
    }
}
```

#### Gotchas

- Pin range `0..=3`.
- The pin must be configured as Input first. The default firmware
  state is unconfigured; call `set_config(Input, _)`.
- The pin **must not** also be Subscribed (§6.7) — pick one
  mechanism per pin.
- `#[tokio::main]` only — see §3 for the mandatory `current_thread`
  warning.
- The `Wait` trait methods wait forever. Production code should
  prefer the bounded inherent methods `Gpio::wait_for_*_with_timeout(Duration)`
  (HAL 0.7+) which return `GpioHalError::Gpio(GpioError::Timeout)`
  on expiry. The trait methods exist for compatibility with
  embedded-hal drivers; the inherent methods exist because
  `embedded-hal-async::Wait` does not accept a timeout.

### 6.7 GPIO subscribe (push events)

**When to use:** the application needs a stream of edge events from
a pin (rotary encoders, repeated button events) without polling and
without holding an async `wait_for_*` future per edge.

**HAL accessors:**

- `hal.gpio_subscribe(pin, edge)` → `Result<(), GpioHalError>` —
  start firmware-side monitoring. `edge` is `GpioEdge::Rising`,
  `Falling`, or `Any`.
- `hal.gpio_unsubscribe(pin)` → `Result<(), GpioHalError>` — stop
  monitoring and return the pin to ordinary use.

Push events arrive on the `"gpio/event"` topic as `GpioEvent` values.
**Receiving them from the HAL is not currently exposed as a typed
stream**; for end-to-end push handling you may need to drop down to
`pico_de_gallo_lib::PicoDeGallo` directly.

**Traits implemented:** n/a (project-specific).

#### Snippet — binary form

```rust
// examples/<chip>.rs
// pico-de-gallo decision log:
//   shape:        binary
//   sync/async:   sync (reason: subscribe/unsubscribe are blocking calls)
//   peripherals:  gpio_subscribe(2)
//   hal version:  <crate version observed at generation time>

use pico_de_gallo_hal::Hal;
use pico_de_gallo_hal::{GpioDirection, GpioEdge, GpioPull};

fn main() {
    let hal = Hal::new();

    // Configure the pin as Input first.
    let mut pin = hal.gpio(2);
    pin.set_config(GpioDirection::Input, GpioPull::Up).unwrap();
    drop(pin);  // release the Gpio handle so the subscription owns it

    hal.gpio_subscribe(2, GpioEdge::Falling).unwrap();
    // Consume GpioEvents via pico_de_gallo_lib::PicoDeGallo if needed.
    // ... eventually:
    hal.gpio_unsubscribe(2).unwrap();
}
```

#### Gotchas

- Pin range `0..=3`.
- While subscribed, the pin **cannot** be `is_low`/`is_high`/`set_*`/`wait_for_*`'d.
  Those calls return `GpioError::PinMonitored`. Call
  `hal.gpio_unsubscribe(pin)` first.
- If a previous host process died while holding a subscription,
  subsequent GPIO operations on that pin fail with `PinMonitored`
  until the firmware is reset. **Recovery:** call
  `hal.system_reset_subscriptions()?` after connect (recommended on
  every `Hal::new_validated()` flow). As of HAL 0.7, the recovery
  endpoint is exposed directly; older HALs required dropping to
  `pico-de-gallo-lib`. Power-cycling the board also works.
- The HAL does not currently surface push events as a stream. For
  full producer/consumer behavior you'll need
  `pico-de-gallo-lib` directly.

### 6.8 PWM

**When to use:** the device needs a duty-cycle waveform — motor
ESCs, dimmable LEDs, servo control.

**HAL accessor:** `hal.pwm_channel(channel)` → returns `PwmChannel`.
Channels `0..=3` (channels 0/1 share slice 6 on GPIO 12/13, channels
2/3 share slice 7 on GPIO 14/15).

```rust
use embedded_hal::pwm::SetDutyCycle;
use pico_de_gallo_hal::Hal;

fn main() {
    let mut hal = Hal::new();
    hal.pwm_set_config(0, 1_000, false).unwrap();  // 1 kHz, edge-aligned
    let mut ch = hal.pwm_channel(0);
    ch.set_duty_cycle_percent(50).unwrap();
}
```

Gotchas: `pwm_set_config(channel, freq_hz, phase_correct)` affects
the whole slice — channels 0/1 cannot use different frequencies, and
neither can 2/3. Async usage: see §3 for the mandatory
`current_thread` warning. See
[`pico-de-gallo-hal` docs.rs](https://docs.rs/pico-de-gallo-hal) for
the full surface.

### 6.9 ADC

**When to use:** read an analog input — potentiometer, thermistor,
battery voltage.

**HAL accessor:** `hal.adc_read(channel)` →
`Result<u16, AdcHalError>`. There is **no `embedded-hal` 1.0 ADC
trait**, so this is a project-specific method.

**Traits implemented:** n/a.

```rust
use pico_de_gallo_hal::{AdcChannel, Hal}; // AdcChannel re-exported by HAL 0.7+

fn main() {
    let hal = Hal::new();
    let raw = hal.adc_read(AdcChannel::Adc0).unwrap();
    let volts = raw as f32 * 3.3 / 4096.0;
    println!("raw: {raw}, V≈{volts:.3}");
}
```

#### Snippet — HIL-test form

```rust
#[cfg(feature = "hil")]
#[test]
fn adc0_reads_in_valid_range() {
    use pico_de_gallo_hal::AdcChannel;
    let hal = pico_de_gallo_hal::Hal::new();
    let raw = hal.adc_read(AdcChannel::Adc0).unwrap();
    assert!(raw <= 4095, "12-bit ADC must be ≤ 4095, got {raw}");
}
```

#### Gotchas

- `AdcChannel` is re-exported by `pico_de_gallo_hal` as of HAL 0.7.
  Older HALs required `use pico_de_gallo_lib::AdcChannel;`.
- 12-bit raw value (`0..=4095`). Convert with `raw × 3.3 / 4096`.
- Use `hal.adc_get_config()` for resolution/reference details
  (returns `AdcConfigurationInfo`, also re-exported as of HAL 0.7).
- Async usage: see §3 for the mandatory `current_thread` warning.

### 6.10 1-Wire

**When to use:** the device is on a Dallas/Maxim 1-Wire bus — DS18B20
temperature sensor, DS2401 silicon serial number, etc.

**HAL accessor:** `hal.onewire()` → returns `OneWire`. No
`embedded-hal` 1-Wire trait exists.

**Traits implemented:** n/a.

```rust
use pico_de_gallo_hal::Hal;

fn main() {
    let hal = Hal::new();
    let ow = hal.onewire();

    let present = ow.reset().unwrap();
    println!("device present: {present}");

    // Issue ROM-skip + convert-T to all devices on the bus.
    ow.write(&[0xCC, 0x44]).unwrap();
}
```

Available methods: `reset()`, `read(len)`, `write(data)`,
`write_pullup(data, pullup_ms)`, `search()`, `search_next()`.

#### Snippet — HIL-test form

```rust
#[cfg(feature = "hil")]
#[test]
fn onewire_bus_has_at_least_one_device() {
    let hal = pico_de_gallo_hal::Hal::new();
    let ow = hal.onewire();
    assert!(ow.reset().unwrap(), "no 1-Wire device responded");
}
```

#### Gotchas

- Enumerate devices with `search()` for the first address, then
  `search_next()` until it returns `None`.
- Parasitic-power parts (DS18B20 in 2-wire mode) need
  `write_pullup(data, pullup_ms)` to hold the line high after the
  convert command.
- Async usage: see §3 for the mandatory `current_thread` warning.

### 6.11 UART

**When to use:** the device speaks serial — a GPS module, a
debug-port-on-UART chip, AT-command modem.

**HAL accessor:** `hal.uart()` → returns `Uart`. Implements
`embedded_io::{Read,Write}` and `embedded_io_async::{Read,Write}`.

```rust
use embedded_io::Write as _;
use pico_de_gallo_hal::Hal;

fn main() {
    let hal = Hal::new();
    let mut uart = hal.uart();
    uart.write_all(b"AT\r\n").unwrap();
}
```

Gotchas: read uses a timeout (default 1000 ms). Set with
`uart.set_timeout_ms(0)` for non-blocking. **Baud rate is fixed at
the firmware default. The HAL does not expose a baud-rate setter** —
to change baud, depend on `pico-de-gallo-lib` and call
`PicoDeGallo::uart_set_config(...)` directly. Async usage: see §3
for the mandatory `current_thread` warning. See
[`pico-de-gallo-hal` docs.rs](https://docs.rs/pico-de-gallo-hal) for
the full surface.

### 6.12 Delay

**When to use:** the driver wants `&mut impl DelayNs` for
register-settle delays, reset sequences, sensor warm-up.

**HAL accessor:** `hal.delay()` → returns `Delay`. Implements
`embedded_hal::delay::DelayNs` and
`embedded_hal_async::delay::DelayNs`.

```rust
use pico_de_gallo_hal::Hal;

fn main() {
    let hal = Hal::new();
    let i2c = hal.i2c();
    let mut delay = hal.delay();
    let mut sensor = MyDriver::new(i2c);
    sensor.init(&mut delay).unwrap();
}
```

Gotchas: blocking `Delay` uses `std::thread::sleep`; async `Delay`
uses `tokio::time::sleep`. Pass `&mut delay` by-mutable-reference to
driver methods. See
[`pico-de-gallo-hal` docs.rs](https://docs.rs/pico-de-gallo-hal) for
the full surface.

## 7. Worked end-to-end example

A complete `examples/shtc3.rs` for the Sensirion SHTC3 temperature
+ humidity sensor. The four-line decision log at the top is
**mandatory** in every generated example — same prefixes, same
order, four lines exactly.

```rust
// examples/shtc3.rs
// pico-de-gallo decision log:
//   shape:        binary
//   sync/async:   sync (reason: shtcx is blocking; no edge wait needed)
//   peripherals:  i2c, delay
//   hal version:  0.6

use pico_de_gallo_hal::Hal;
use shtcx::{shtc3, PowerMode};

fn main() {
    let hal = Hal::new();
    let i2c = hal.i2c();           // §6.1
    let mut delay = hal.delay();   // §6.12

    let mut sensor = shtc3(i2c);
    let m = sensor.measure(PowerMode::NormalMode, &mut delay).unwrap();

    println!(
        "{:.2} °C / {:.2} %RH",
        m.temperature.as_degrees_celsius(),
        m.humidity.as_percent(),
    );
}
```

Decision-log format — **literal, four lines, exact prefixes**:

```text
// pico-de-gallo decision log:
//   shape:        binary | hil-test
//   sync/async:   sync | async (reason: …)
//   peripherals:  i2c, gpio(3)
//   hal version:  <crate version observed at generation time>
```

Free-form variants are not permitted. The fixed format is
grep-checkable by the maintainer drift-prevention hooks (see §9).

## 8. Completion checklist

Before declaring the example done, verify every one of these:

- [ ] The `Cargo.toml` entries from §4 are present and correct.
- [ ] The chosen output shape (binary vs HIL test) matches the
      user's intent per §2.
- [ ] The sync/async choice follows §3, and if async, the runtime is
      multi-thread (`#[tokio::main]` with **no** `current_thread`
      flavor).
- [ ] Every HAL accessor used appears in the approved list below
      (i.e. is one of `hal.i2c`, `hal.spi`, `hal.spi_device`,
      `hal.gpio`, `hal.gpio_subscribe`, `hal.gpio_unsubscribe`,
      `hal.pwm_channel`, `hal.adc_read`, `hal.uart`, `hal.delay`,
      `hal.onewire`, or one of their associated `*_set_config`/
      `*_get_config` siblings). No invented APIs.
- [ ] Pin numbers are in range: GPIO `0..=3`, PWM channel `0..=3`,
      ADC channel is an `AdcChannel` enum variant.
- [ ] If using `spi_device(cs)`, the `cs` pin is **not** also used
      as a `Gpio` elsewhere.
- [ ] If using `gpio_subscribe(pin, …)`, a matching
      `gpio_unsubscribe(pin)` exists on every exit path.
- [ ] The mandatory four-line decision-log comment block is at the
      top of the example, with the literal prefixes from §7.
- [ ] If the host can run `cargo check` against the generated file,
      it passes.

## 9. Drift-prevention note (for maintainers)

This file documents the public surface of `pico-de-gallo-hal`. It is
listed in `AGENTS.md` §15.1 as a parity target for
`crates/pico-de-gallo-hal/src/`. Any PR that changes the HAL public
surface (accessor added/removed/renamed, gotcha discovered, trait
impl changed) must update this file in the same commit. Reviewers
treat omissions as a blocker, not a nit.

**Recommended CI guard (not yet implemented):** a regex check that
extracts every `hal\.\w+\(` and `Hal::\w+\b` from this file and
asserts the symbol exists as a `pub fn` in
`crates/pico-de-gallo-hal/src/lib.rs`. A one-liner that catches the
common drift mode:

```bash
diff <(grep -oE '(hal\.[a-z0-9_]+\()|(Hal::[a-z0-9_]+\b)' \
        docs/ai-agents/pico-de-gallo-hal-examples.md | sort -u) \
     <(grep -oE 'pub fn [a-z0-9_]+' \
        crates/pico-de-gallo-hal/src/lib.rs | sort -u)
```

If the file disagrees with the source, the **source wins** — file an
issue at
<https://github.com/OpenDevicePartnership/pico-de-gallo/issues>.

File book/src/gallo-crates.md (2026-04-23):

# Gallo Crates

*Pico de Gallo* provides several different crates to provide a
comfortable and ergonomic experience to its users. The most relevant
crates are discussed below.

## Gallo App

The `gallo` app's main purpose is that of one-off, or batch-mode
communication with *Pico de Gallo*'s I<sup>2</sup>C, SPI, UART, GPIO, and PWM buses. The
built-in help text gives us a little more information.

```console
$ gallo help
Access I2C/SPI devices through Pico De Gallo

Usage: gallo.exe [OPTIONS] [COMMAND]

Commands:
  list     List connected Pico de Gallo devices
  version  Get firmware version
  i2c      I2C access methods
  spi      SPI access methods
  gpio     GPIO access methods
  uart     UART access methods
  pwm      PWM control methods
  adc      ADC access methods
  onewire  1-Wire bus access methods
  help     Print this message or the help of the given subcommand(s)

Options:
  -s, --serial-number <SERIAL_NUMBER>
  -h, --help                           Print help
  -V, --version                        Print version
```
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

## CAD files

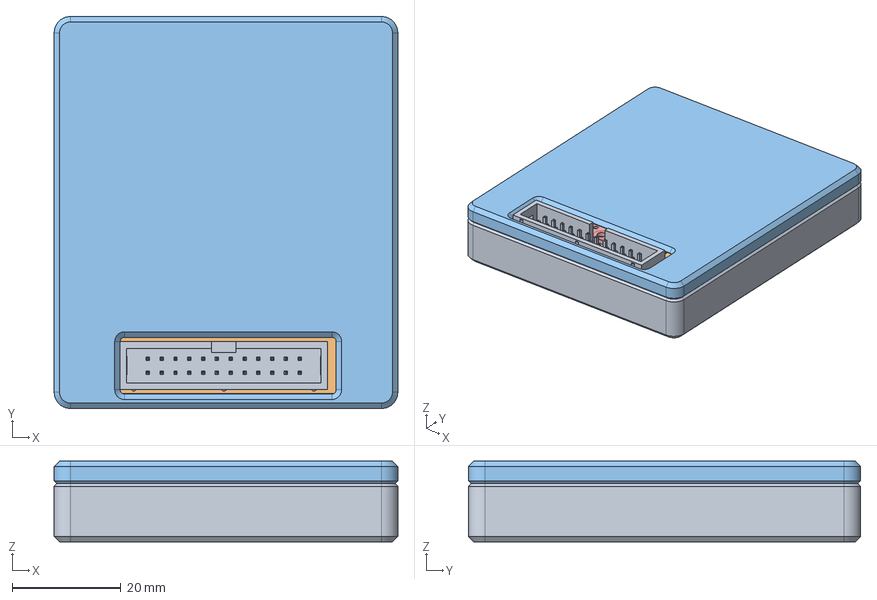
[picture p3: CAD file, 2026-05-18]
case/v1.1/Case.FCStd
63.2 x 72.1 x 14.9 mm
R_0603_1608Metric
R_0603_1608Metric001
R_0603_1608Metric002
RaspberryPi_Pico_Module_KiCad
C_0603_1608Metric
R_0603_1608Metric003
R_0603_1608Metric004
IDC-Header_2x12_P2.54mm_Vertical
pico-de-gallo_PCB
Lid

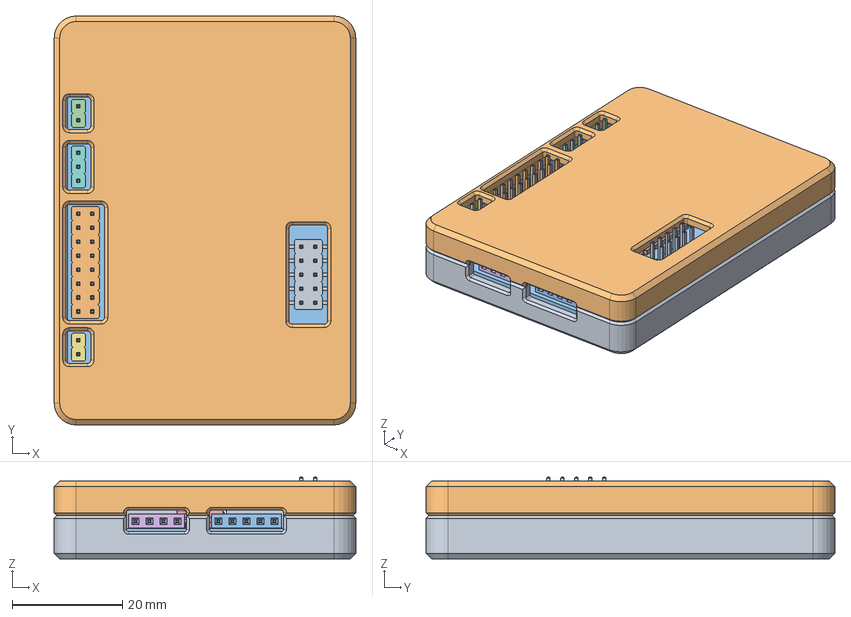
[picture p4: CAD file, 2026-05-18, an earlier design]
case/v1.0/Case.FCStd
54.8 x 74.3 x 14.9 mm
Lid
PinSocket_1x05_P2.54mm_Horizontal
PinHeader_1x02_P2.54mm_Vertical
RaspberryPi_Pico_Module_KiCad
PinSocket_1x04_P2.54mm_Horizontal
PinHeader_1x02_P2.54mm_Vertical001
PinHeader_1x03_P2.54mm_Vertical
PinHeader_2x05_P2.54mm_Vertical_SMD
PinHeader_2x08_P2.54mm_Vertical
pico-de-gallo_PCB

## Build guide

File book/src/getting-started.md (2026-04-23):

# Getting Started

There are just a few steps needed in order to get a functioning *Pico
de Gallo* on your hands:

1. Fabricate the landing board
2. Solder components
3. Flash latest Firmware

We will look at the each in the following sections, but first we need
to discuss materials and equipment needed to assemble a *Pico de
Gallo* PCB.

## Equipment and materials

1. Soldering iron or soldering station
2. Solder wire spool
3. Soldering iron tip cleaner (either sponge or brass will work)
4. Good quality no-clean liquid flux
5. Raspberry pi Pico 2 board
6. *Pico de Gallo* landing board
7. ESD-safe cleaning brushes
8. (Optional) PCB holder or *helping hands*
9. (Optional) Soldering iron tip tinner

## PCB Fabrication

There are several suitable PCB fabrication services which can consume
our Gerbers and produce high quality PCBs delivered to your door. You
are free to choose whichever your want.

**DISCLAIMER: we are not responsible for anything related to PCB
fabrication. Any costs, mistakes, damages associated with it are your
responsibility.**

Our gerbers are hosted in the
[Releases](https://github.com/OpenDevicePartnership/pico-de-gallo/releases)
page for our [Github
repository](https://github.com/OpenDevicePartnership/pico-de-gallo). For
convenience, [here's the
link](https://github.com/OpenDevicePartnership/pico-de-gallo/releases/tag/hardware-v0.1.0)
to the latest Gerber release at the time of this writing.

For most of these PCB fabrication services, you can just upload the
`gerbers.zip` file downloaded from our Hardware release above, select
your desired silk screen color, solder mask color, and surface finish
and place the order. Once the boards are ready, they should be mailed
to your door.

## Soldering Components

> [!TIP]
>
> Soldering takes practice. Before starting make sure you have all
> necessary equipment and materials around you and no unnecessary
> obstructions.
>
> Make sure that the tip of your soldering iron touches both
> components being soldered together. That is, if you're soldering the
> Pico 2 to the landing board, the iron tip should touch both the pico
> 2 and the landing board's pad at the same time.
>
> Let the area heat up for a couple seconds before introducing the
> solder wire.

When soldering, it's wise to start with the lowest height components
first. In the case of *Pico de Gallo*, that will be the Pico 2
itself.

Here are some of materials and equipment necessary:

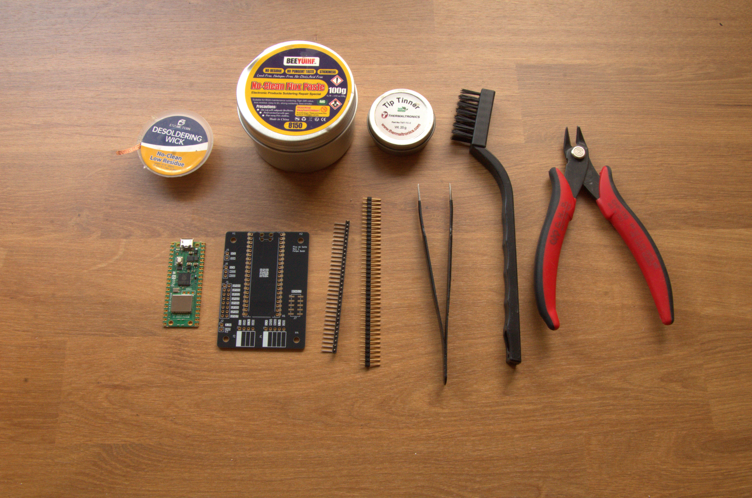
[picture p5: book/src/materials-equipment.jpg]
Materials and Equipment


### Soldering the Pico 2

Place the Pico 2 onto the landing board aligning the edge of
the Pico 2 board to the edge of the landing board as shown below:

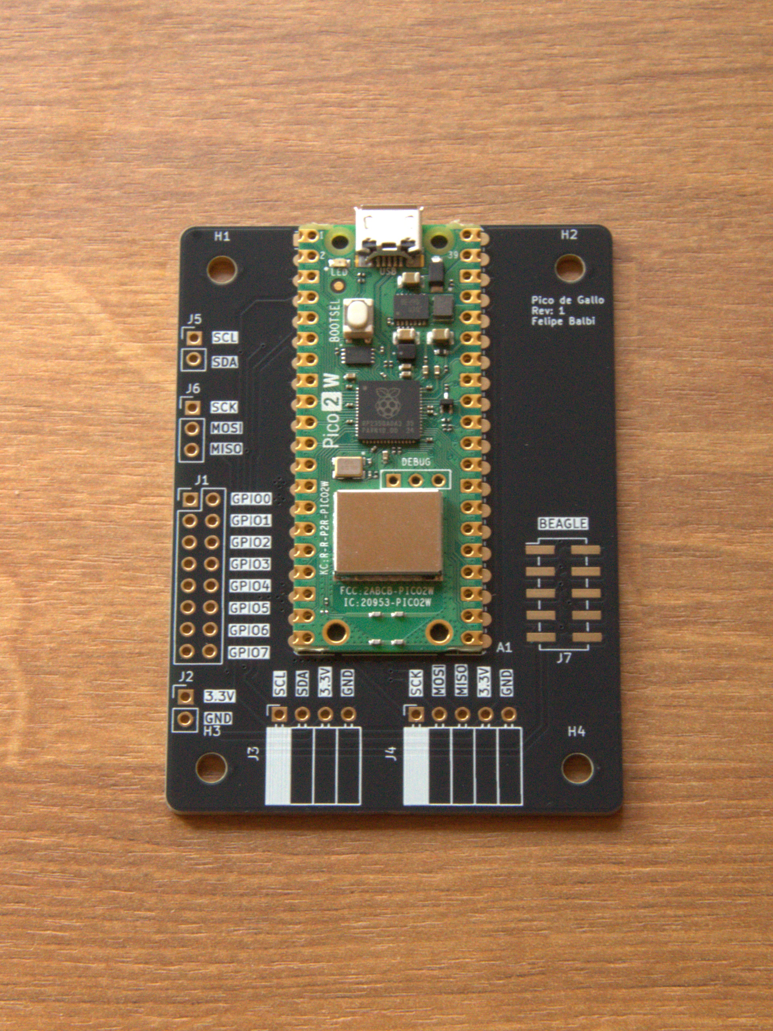
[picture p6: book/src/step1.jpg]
Step 1


Start by soldering one and only one corner pad:

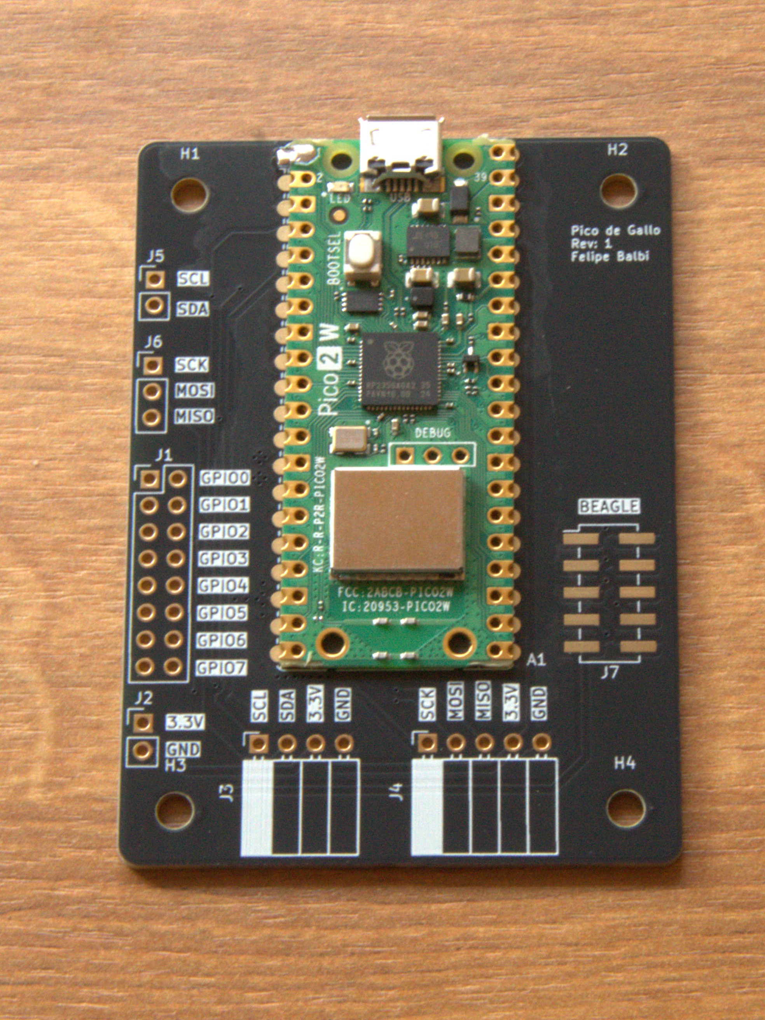
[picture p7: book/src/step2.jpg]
Step 2


This will allow you to reflow &mdash; that is, remelt &mdash; the
solder and move the board around in case it doesn't exactly align with
the other pads.

> [!TIP]
>
> Solder flux makes the process of soldering these components a lot
> easier. Grab some no-clean flux, spread around the pads and the
> solder will be *pulled onto* the pads by surface tension.
>
> As it turns out, solder really likes to stick to exposed copper and
> truly despises solder mask.

Once you align the board correctly &mdash; see the example below
&mdash;, you can move on to the opposite corner. This will help
prevent any further movement during the remainder of the soldering
process.

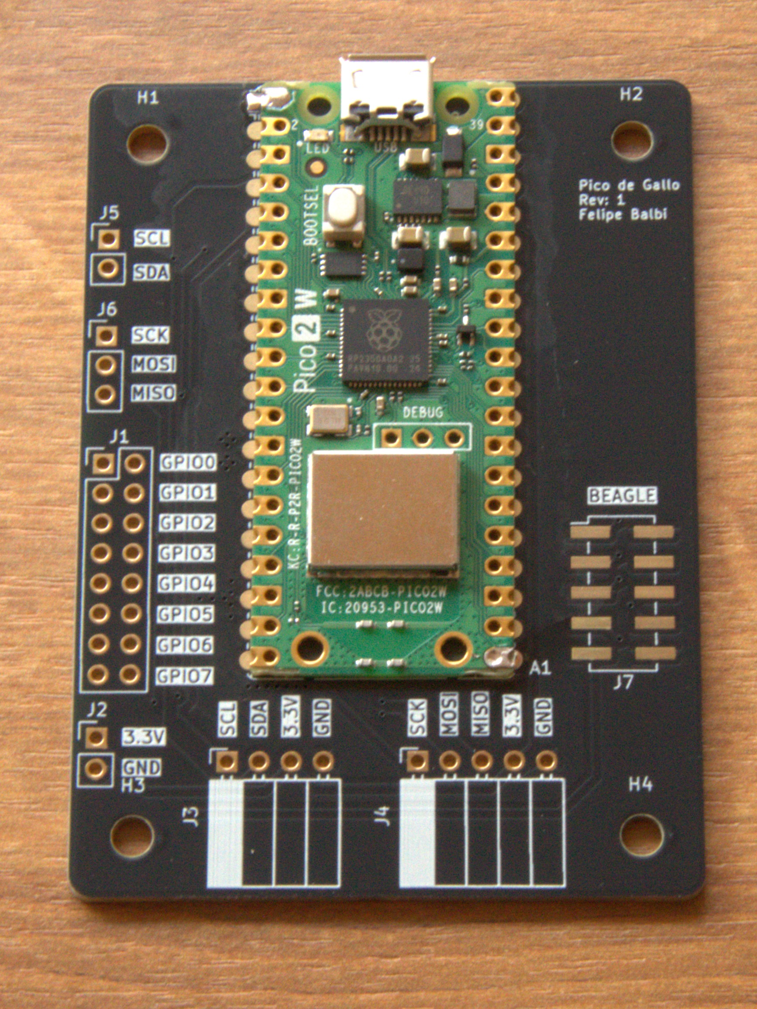
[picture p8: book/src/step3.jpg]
Step 3


At this point you are ready to solder all remaining pads. The landing
board and pico 2 should be strongly attached to one another as shown
below:

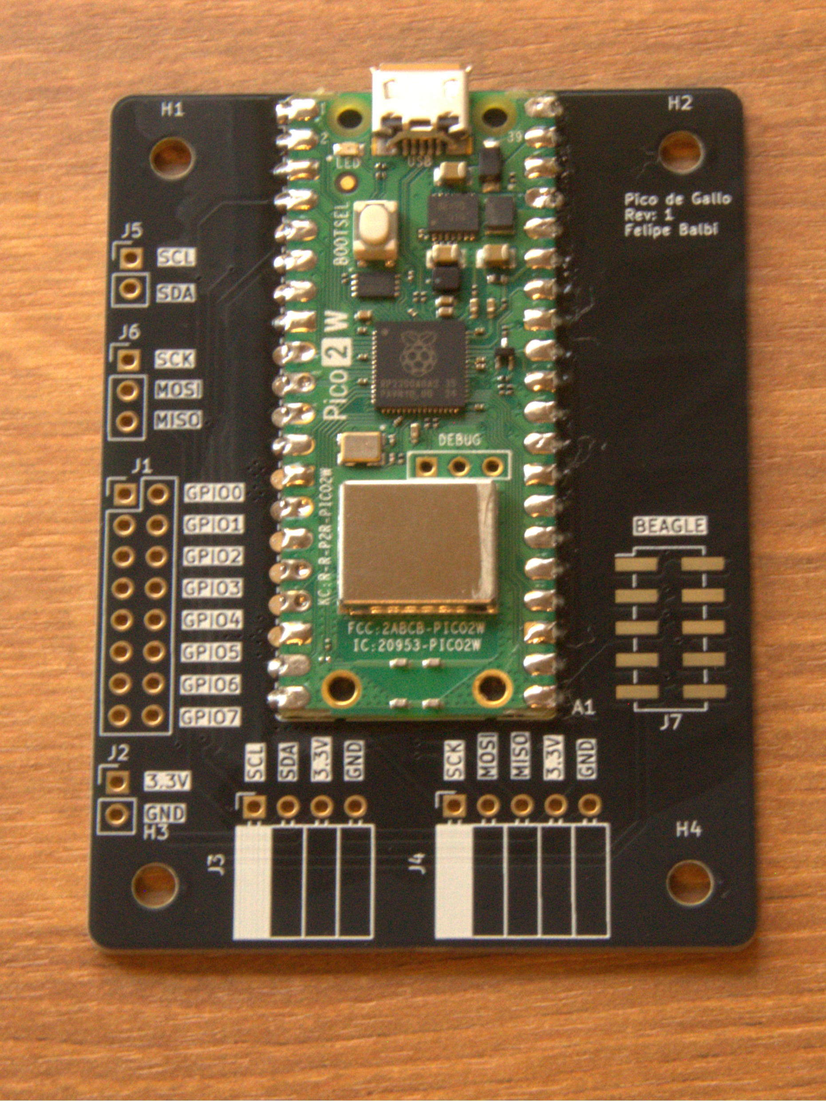
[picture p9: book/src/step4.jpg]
Step 4


### Soldering right angle headers

Next, you should move on to the right angle headers. These a bit
tricky to solder, but with some patience and, perhaps, a piece of
Polyimide Electrical Tape &mdash; also known as *Kapton Tape* &mdash;
to hold the headers while you solder, should make the process a little
easier.

Similarly to how we soldered the pico 2 to the landing board, here,
too, we want to solder one pin only and make sure everything remains
aligned before proceeding. Below you can see the process as a sequence
of images.

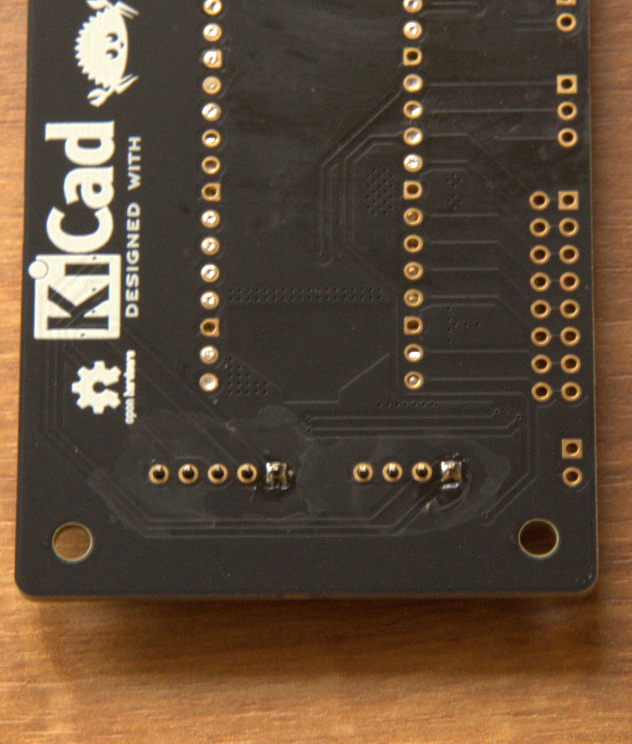
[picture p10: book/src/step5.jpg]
Step 5

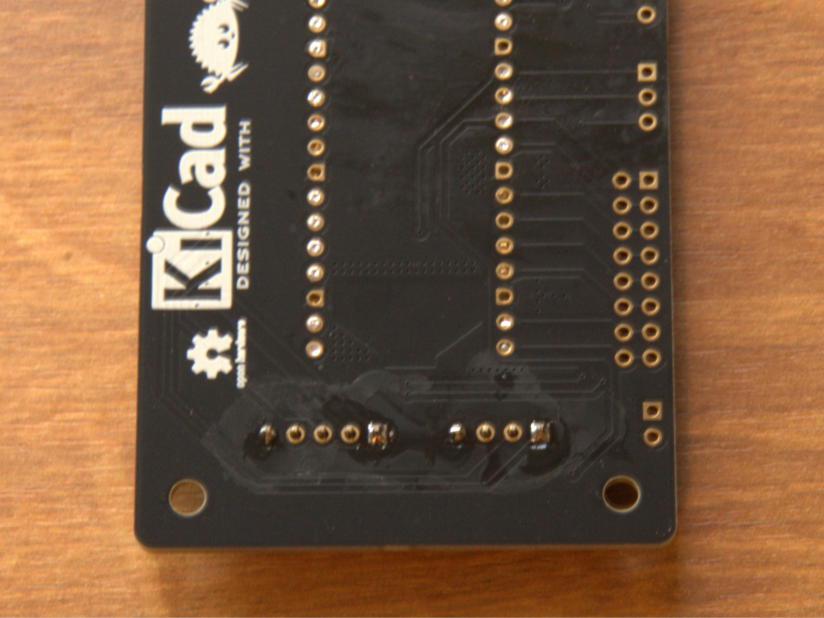
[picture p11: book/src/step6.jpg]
Step 6

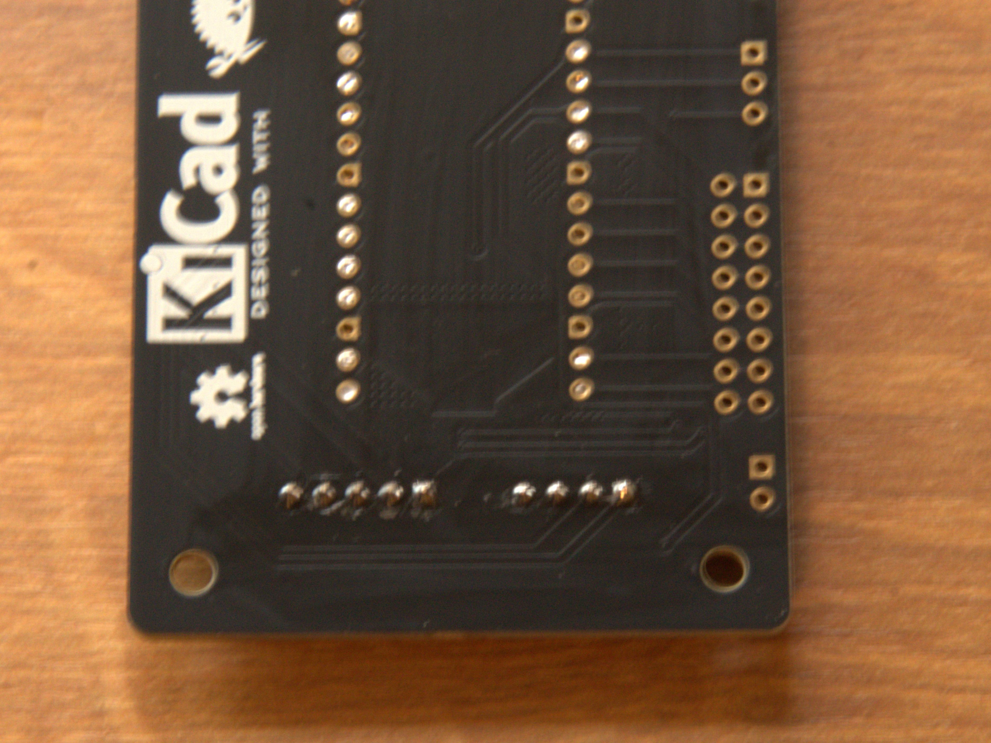
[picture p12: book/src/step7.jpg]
Step 7


Finally, we can solder all the remaining headers as they are all the
same height.

### Soldering remaining headers

Once again, solder one pin on each header:

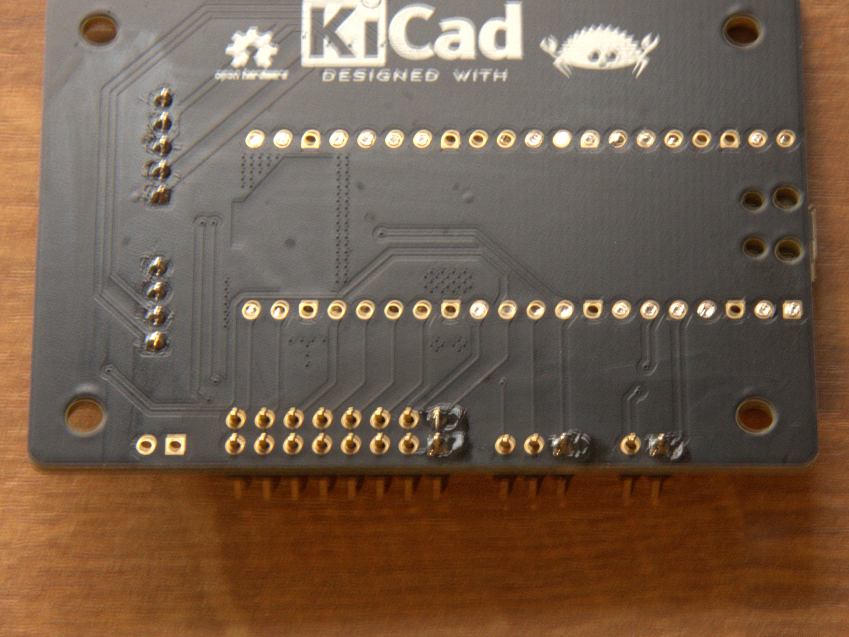
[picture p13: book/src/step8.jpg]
Step 8


If any of them hardened *crooked* or not flush with the landing board,
fix it before proceeding. Continue by soldering one more pin on the
opposite corner of each header. Finish by soldering all remaining pins.

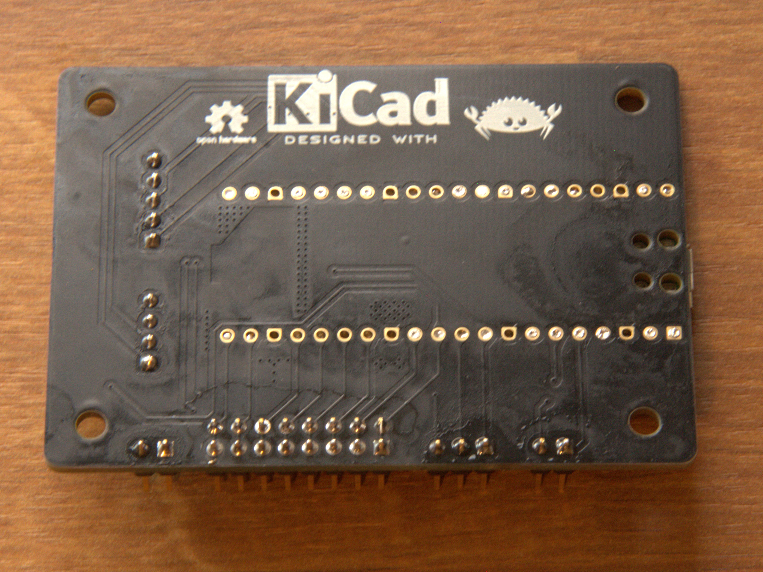
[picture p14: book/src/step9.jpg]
Step 9


### Finishing touches

Now is a good time to visually inspect the board. Make sure there are
no *bridged* pins or pads &mdash; that is, no solder shorting any
neighboring pins to each other &mdash; as that could cause unexpected
problems if you were to plug the USB cable.

After verifying that the board looks correct, now is the time to scrub
the excess flux residue off the board. This is achieved with ESD safe
brushes and 99% Isopropyl Alcohol.

> [!CAUTION]
>
> Isopropyl Alcohol (IPA) is highly flammable. Care should be taken to
> not inhale IPA fumes. Make sure you are in a well-ventilated area
> while cleaning the board with IPA.
>
> IPA can also some dryness upon skin contact.

## Flashing Firmware

With an assembled *Pico de Gallo*, the next step is to flash the
latest Firmware. In order to do so, we download the latest
`firmware.uf2` from the [Releases](https://github.com/OpenDevicePartnership/pico-de-gallo/releases)
page from our [Github
repository](https://github.com/OpenDevicePartnership/pico-de-gallo). At
the time of this writing, that is [Firmware
v0.5.0](https://github.com/OpenDevicePartnership/pico-de-gallo/releases/tag/firmware-v0.5.0).

It's very easy to update firmware on *Pico de Gallo*, simply:

1. Insert the USB cable to pico 2's micro-USB port
2. Press and hold the `BOOTSEL` button
3. Insert the other end of the USB cable to an available USB port on
   your computer

A new USB drive named `RP2350` should show on your computer. Simply
drag and drop the `firmware.uf2` file to this new USB drive. *Pico de
Gallo* will automatically disconnect and reconnect with the new
Firmware.

## Verifying Firmware Version

Finally, let's verify that the firmware running on the device matches
our expectation. Grab the `pico-de-gallo-app` suitable for your host
Operating System from our
[Releases](https://github.com/OpenDevicePartnership/pico-de-gallo/releases)
page. At the time of this writing, the latest version is [Application
v0.5.0](https://github.com/OpenDevicePartnership/pico-de-gallo/releases/tag/application-v0.5.0). We
currently support `x86_64` and `Aarch64` for both Windows and Linux,
and `Aarch64` for macOS.

Once you have the correct binary, run the `version` command:

```console
$ gallo version
Pico de Gallo FW v0.8.0
Schema v0.4.0
HW revision 1
Capabilities: I2C ✓ | SPI ✓ | UART ✗ | GPIO ✓ | PWM ✓ | ADC ✗ | 1-Wire ✗
```

Success 🎉. With this completed we can get familiarized with the other
parts of the *Pico de Gallo* ecosystem and write a driver for the
`tmp102` temperature sensor.

## Hardware Revisions

The firmware is compiled with a hardware revision feature flag that
controls which peripherals are available. The `gallo version` output
shows the hardware revision and its supported capabilities.

| Revision | Feature Flag | Connector | Capabilities |
|---|---|---|---|
| **v1.0** | `hw-rev1` (default) | 7 separate pin headers | I2C, SPI, GPIO, PWM |
| **v1.1** | `hw-rev2` | Single 2×12 shrouded header | I2C, SPI, UART, GPIO, PWM, ADC, 1-Wire |
| **v2** (future) | `hw-rev2` | Single 2×12 shrouded header + level translators | I2C, SPI, UART, GPIO, PWM, ADC, 1-Wire |

> **v1.0 — Best Effort**
>
> The v1.0 board only routes 13 of 20 firmware signals. UART (GPIO 0–1),
> SPI CS (GPIO 5), 1-Wire (GPIO 16), and ADC (GPIO 26–28) are **not
> connected** to any header. Calling an unsupported endpoint on v1
> firmware returns an `Unsupported` error. If you need the full
> peripheral set, upgrade to v1.1 or later.

The v1.1 board replaces the seven individual connectors with a single
keyed 2×12 (0.1″ pitch) shrouded header and routes all 20 firmware
signals. It uses the `hw-rev2` firmware and reports all seven
capabilities. On-board passives include I²C pull-ups (4.7 kΩ), ADC
series resistors (100 Ω), and a 100 nF decoupling capacitor.

### V1.1 Connector Pinout

Viewed from above with the USB connector facing up, pin 1 is at the
top-right of the header. The shroud key notch faces right. Even pins
(bottom row) are on the left, odd pins (top row) are on the right:

```
 Pin 2  GND          ┃ VREF (+3V3) Pin 1
 Pin 4  I2C_SCL      ┃ I2C_SDA     Pin 3
 Pin 6  SPI_MOSI     ┃ SPI_MISO    Pin 5
 Pin 8  SPI_CS       ┃ SPI_SCK     Pin 7
 Pin 10 UART_RX      ┃ UART_TX     Pin 9
 Pin 12 GPIO1        ┃ GPIO0       Pin 11
 Pin 14 GPIO3        ┃ GPIO2       Pin 13
 Pin 16 PWM1         ┃ PWM0        Pin 15
 Pin 18 PWM3         ┃ PWM2        Pin 17
 Pin 20 ADC0         ┃ ONEWIRE     Pin 19
 Pin 22 ADC2         ┃ ADC1        Pin 21
 Pin 24 GND          ┃ +3V3        Pin 23
```

**Pin 1 (VREF)** is hardwired to 3.3 V on v1.1. On the future v2
board it becomes a variable-voltage rail (1.8 V / 3.3 V / 5 V).
Adapter boards ("toppings") that plug into this header will see 3.3 V
on v1.1.

| Header Pin | Net | RP2350 GPIO | Direction | Notes |
|---|---|---|---|---|
| 1 | VREF | — | Power out | 3.3 V (hardwired) |
| 2 | GND | — | Power | Ground |
| 3 | SDA | GPIO 2 | Bidir | I²C1 SDA, 4.7 kΩ pull-up  |
| 4 | SCL | GPIO 3 | Bidir | I²C1 SCL, 4.7 kΩ pull-up  |
| 5 | SPI_MISO | GPIO 4 | Input | SPI0 RX |
| 6 | SPI_MOSI | GPIO 7 | Output | SPI0 TX |
| 7 | SPI_SCK  | GPIO 6 | Output | SPI0 SCK |
| 8 | SPI_CS | GPIO 5 | Output | SPI0 CSn |
| 9 | UART_TX  | GPIO 0 | Output | UART0 TX |
| 10 | UART_RX  | GPIO 1 | Input | UART0 RX |
| 11 | GPIO0 | GPIO 8 | Bidir | User GPIO 0 |
| 12 | GPIO1 | GPIO 9 | Bidir | User GPIO 1 |
| 13 | GPIO2 | GPIO 10 | Bidir | User GPIO 2 |
| 14 | GPIO3 | GPIO 11 | Bidir | User GPIO 3 |
| 15 | PWM0 | GPIO 12 | Output | PWM slice 6A |
| 16 | PWM1 | GPIO 13 | Output | PWM slice 6B |
| 17 | PWM2 | GPIO 14 | Output | PWM slice 7A |
| 18 | PWM3 | GPIO 15 | Output | PWM slice 7B |
| 19 | ONEWIRE  | GPIO 16 | Bidir | PIO0/SM0, open-drain |
| 20 | ADC0 | GPIO 26 | Input | Via 100 Ω series resistor |
| 21 | ADC1 | GPIO 27 | Input | Via 100 Ω series resistor |
| 22 | ADC2 | GPIO 28 | Input | Via 100 Ω series resistor |
| 23 | +3V3 | — | Power out | Direct 3.3 V |
| 24 | GND | — | Power | Ground |

## Pin Map

The table below shows every function exposed by the firmware and the
RP2350 GPIO it maps to. This is the authoritative pin assignment —
refer to this when wiring peripherals.

| Function | GPIO | HW Rev | Notes |
|---|---|---|---|
| UART TX | GPIO 0  | v1.1+  | Buffered, interrupt-driven  |
| UART RX | GPIO 1  | v1.1+  | |
| I²C SDA | GPIO 2  | v1+ | 7-bit addressing, async DMA |
| I²C SCL | GPIO 3  | v1+ | |
| SPI RX (MISO) | GPIO 4  | v1+ | DMA-backed full-duplex |
| SPI CS | GPIO 5  | v1.1+  | Active-low chip select |
| SPI SCK | GPIO 6  | v1+ | |
| SPI TX (MOSI) | GPIO 7  | v1+ | |
| GPIO 0 | GPIO 8  | v1+ | Input/output/edge events |
| GPIO 1 | GPIO 9  | v1+ | Input/output/edge events |
| GPIO 2 | GPIO 10 | v1+ | Input/output/edge events |
| GPIO 3 | GPIO 11 | v1+ | Input/output/edge events |
| PWM 0 | GPIO 12 | v1+ | Slice 6 channel A |
| PWM 1 | GPIO 13 | v1+ | Slice 6 channel B |
| PWM 2 | GPIO 14 | v1+ | Slice 7 channel A |
| PWM 3 | GPIO 15 | v1+ | Slice 7 channel B |
| 1-Wire | GPIO 16 | v1.1+  | PIO0/SM0, open-drain |
| ADC 0 | GPIO 26 | v1.1+  | 12-bit, 0–3.3 V nominal |
| ADC 1 | GPIO 27 | v1.1+  | 12-bit |
| ADC 2 | GPIO 28 | v1.1+  | 12-bit |

## Software Prerequisites

To use *Pico de Gallo* you need the `gallo` CLI application. Pre-built
binaries for Windows (x86_64, Aarch64), Linux (x86_64, Aarch64), and
macOS (Aarch64) are available on the
[Releases](https://github.com/OpenDevicePartnership/pico-de-gallo/releases) page.

If you prefer to build from source:

1. Install [Rust](https://rustup.rs/) (stable toolchain)
2. Clone the repository: `git clone https://github.com/OpenDevicePartnership/pico-de-gallo`
3. Build the CLI: `cd crates && cargo build --release -p gallo`
4. The binary will be at `target/release/gallo` (or `gallo.exe` on Windows)

### USB Driver Notes

- **Linux** — you may need a udev rule to allow non-root access. Create
  `/etc/udev/rules.d/99-pico-de-gallo.rules` with:
  ```
  SUBSYSTEM=="usb", ATTR{idVendor}=="045e", ATTR{idProduct}=="ffff", MODE="0666"
  ```
  Then run `sudo udevadm control --reload-rules && sudo udevadm trigger`.
- **Windows** — the device should be recognized automatically. If not,
  use [Zadig](https://zadig.akeo.ie/) to install the WinUSB driver.
- **macOS** — no additional drivers needed.

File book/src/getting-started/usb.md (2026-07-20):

# USB & OS Notes

The Pico de Gallo firmware uses a generic WinUSB-compatible
descriptor, so most operating systems pick it up without a custom
driver. The notes below cover the cases where you need to nudge
the OS.

## Linux

Out-of-the-box, libusb (and therefore `nusb`) requires root to
open arbitrary USB devices. To let your regular user account talk
to Pico de Gallo, drop a udev rule:

```text
# /etc/udev/rules.d/99-pico-de-gallo.rules
SUBSYSTEM=="usb", ATTR{idVendor}=="045e", ATTR{idProduct}=="067d", MODE="0666"
```

Then reload udev:

```console
$ sudo udevadm control --reload-rules
$ sudo udevadm trigger
```

Unplug and replug the device. `gallo version` should now work
without `sudo`.

> [!NOTE]
>
> The device enumerates with VID `045e` (Microsoft) and PID
> `067d`, defined by the firmware (`MICROSOFT_VID` /
> `PICO_DE_GALLO_PID` in `pico-de-gallo-internal`). They may
> change across firmware versions, so avoid hard-coding them in
> long-lived tooling.

## Windows

The firmware advertises a Microsoft OS 2.0 descriptor that tells
Windows to bind the WinUSB driver automatically. The first time
you plug in a Pico de Gallo, you may see a brief "installing
device" notification — that's normal. After that, `gallo` works
without any extra setup.

If for some reason WinUSB doesn't bind (e.g., a stale Zadig
override, or driver-signing policy on a corporate machine), use
[Zadig](https://zadig.akeo.ie/) to manually install the WinUSB
driver against the Pico de Gallo interface.

## macOS

No extra setup. macOS picks the device up automatically.

If `gallo list` returns nothing, check System Information →
USB and confirm the device enumerates. If it shows up there but
`gallo` can't find it, you might have a code-signing issue with a
locally-built `gallo` binary — try the pre-built release artifact.

## Troubleshooting

- **`gallo: device not found`** — Is the device plugged in? Did
  you flash firmware? Try `gallo list`.
- **`Permission denied` on Linux** — udev rule missing or not
  reloaded. See above.
- **`gallo version` succeeds but `gallo i2c scan` hangs** — the
  bus has no pull-ups, or your peripheral is clock-stretching
  forever. Add 4.7 kΩ pull-ups (v1.0 boards lack them on-board).
- **Device disappears after a write** — likely a brown-out from
  trying to source too much current through the on-board 3.3 V
  rail. Power the peripheral externally.

See also: [Troubleshooting](../appendix/troubleshooting.md) for
the full list.

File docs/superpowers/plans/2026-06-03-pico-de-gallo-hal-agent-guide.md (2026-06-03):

# Pico de Gallo HAL AI-Agent Guide — Implementation Plan

> **For agentic workers:** REQUIRED SUB-SKILL: Use superpowers:subagent-driven-development (recommended) or superpowers:executing-plans to implement this plan task-by-task. Steps use checkbox (`- [ ]`) syntax for tracking.

**Goal:** Add a single ~500–800-line markdown file at `docs/ai-agents/pico-de-gallo-hal-examples.md` that an AI coding agent fetches over HTTP and uses as a complete recipe for generating a working `pico-de-gallo-hal` example or HIL test. Add one row to `AGENTS.md` §15.1 so the file stays in lockstep with the HAL.

**Architecture:** Pure docs change. The file is built incrementally section-by-section (TL;DR → rules → decision tree → 12 peripheral subsections → worked example → checklist → drift note). After every task that adds code snippets, run the §15-acceptance grep to confirm no fabricated HAL accessors have appeared. One commit per task.

**Tech Stack:** Markdown only. Verification uses `grep`, `wc -l`, and `file`. No Rust, no build steps. LF line endings enforced by `.gitattributes`.

**Spec:** `docs/superpowers/specs/2026-06-03-pico-de-gallo-hal-agent-guide-design.md` is the source of truth for every decision. If the plan and spec disagree, the spec wins.

---

## Conventions

- **Working directory:** repo root (`/home/balbi/workspace/pico-de-gallo`) unless a step says otherwise.
- **Commit style:** Conventional Commit, scope `repo`, with the AI-agent attribution trailers from `AGENTS.md` §10:
  ```
  Co-authored-by: Copilot <223556219+Copilot@users.noreply.github.com>
  Assisted-by: <AGENT>:<MODEL>
  ```
  Substitute `<AGENT>:<MODEL>` with the actual agent/model running the task (verify before composing; do not guess). **Never** add `Signed-off-by:` on AI-assisted commits.
- **Per-task commit message body:** brief, ≤72-char wrap, says what and why.
- **Line endings:** LF only. After every file write, confirm with `file <path>` — output must not contain "CRLF".
- **Hard rules to honor:** AGENTS.md §4 (LF endings, never push without permission, no squash merge, AI-attribution trailers, no `Signed-off-by`, repo is `OpenDevicePartnership/pico-de-gallo`).
- **Verification grep (used in multiple tasks):**
  ```bash
  grep -oE '(hal\.[a-z_]+\()|(Hal::[a-z_]+\b)' \
      docs/ai-agents/pico-de-gallo-hal-examples.md | sort -u
  grep -oE 'pub fn [a-z_]+' \
      crates/pico-de-gallo-hal/src/lib.rs | sort -u
  ```
  Every name in the first list must appear in the second list, **or** be a method on `Gpio`, `I2c`, `Spi`, `SpiDev`, `Uart`, `PwmChannel`, `Delay`, or `OneWire` (the §11 surface table covers those).
- **Verified HAL surface** (do not invent anything beyond this — copy from spec §11):
  - `Hal::new()`, `Hal::new_with_serial_number(&str)`
  - `Hal::i2c()`, `Hal::i2c_set_config(I2cFrequency)`, `Hal::i2c_get_config()`, `Hal::i2c_scan(bool)`
  - `Hal::spi()`, `Hal::spi_device(u8) -> Result<SpiDev, SpiHalError>`, `Hal::spi_set_config(u32, SpiPhase, SpiPolarity)`, `Hal::spi_get_config()`
  - `Hal::gpio(u8) -> Gpio`, `Hal::gpio_subscribe(u8, GpioEdge)`, `Hal::gpio_unsubscribe(u8)`
  - `Hal::pwm_channel(u8) -> PwmChannel`, `Hal::pwm_set_config(u8, u32, bool)`, `Hal::pwm_get_config(u8)`
  - `Hal::adc_read(AdcChannel) -> Result<u16, AdcHalError>`, `Hal::adc_get_config()`
  - `Hal::uart() -> Uart`, `Hal::delay() -> Delay`, `Hal::onewire() -> OneWire`
  - `Gpio::set_config(GpioDirection, GpioPull)` plus blocking `OutputPin`/`InputPin`/`StatefulOutputPin` and async `Wait` trait methods (`is_high`, `is_low`, `set_high`, `set_low`, `is_set_high`, `is_set_low`, `wait_for_high`, `wait_for_low`, `wait_for_rising_edge`, `wait_for_falling_edge`, `wait_for_any_edge`).
  - `Uart::set_timeout_ms(u32)` plus `embedded_io::{Read,Write}` and `embedded_io_async::{Read,Write}` trait methods.
  - `OneWire::reset() -> Result<bool, _>`, `read(u16)`, `write(&[u8])`, `write_pullup(&[u8], u16)`, `search() -> Result<Option<u64>, _>`, `search_next()`.
  - Re-exported types from `pico_de_gallo_lib`: `GpioEvent`, `I2cFrequency`, `SpiConfigurationInfo`, `SpiPhase`, `SpiPolarity`, `UartConfigurationInfo`. **Not** re-exported: `AdcChannel`, `GpioDirection`, `GpioEdge`, `GpioPull`, `AdcConfigurationInfo`. Agent code must `use pico_de_gallo_lib::<Type>;` for those.

---

## Task 1: Create directory and frontmatter skeleton

**Files:**
- Create: `docs/ai-agents/pico-de-gallo-hal-examples.md`

- [ ] **Step 1: Create directory**

```bash
mkdir -p docs/ai-agents
ls docs/ai-agents
```
Expected: directory exists, empty.

- [ ] **Step 2: Write frontmatter + section headings shell**

Write `docs/ai-agents/pico-de-gallo-hal-examples.md` with this exact content (and nothing else yet):

```markdown
# Pico de Gallo HAL — AI Agent Guide

Audience: AI coding agents writing host-side examples or HIL tests that
exercise an `embedded-hal` driver against real hardware via a Pico de
Gallo USB bridge.

**Source of truth:** `crates/pico-de-gallo-hal/src/lib.rs` on `main`.
If this file contradicts that file, the source wins — file an issue at
<https://github.com/OpenDevicePartnership/pico-de-gallo/issues>.

## 1. TL;DR

<!-- filled in Task 2 -->

## 2. Output-shape rule (binary vs. HIL test)

<!-- filled in Task 3 -->

## 3. Sync-vs-async rule

<!-- filled in Task 4 -->

## 4. Cargo setup

<!-- filled in Task 5 -->

## 5. Peripheral decision tree

<!-- filled in Task 6 -->

## 6. Per-peripheral reference

<!-- filled in Tasks 7–11 -->

## 7. Worked end-to-end example

<!-- filled in Task 12 -->

## 8. Completion checklist

<!-- filled in Task 13 -->

## 9. Drift-prevention note (for maintainers)

<!-- filled in Task 14 -->
```

- [ ] **Step 3: Confirm LF line endings**

```bash
file docs/ai-agents/pico-de-gallo-hal-examples.md
```
Expected: output contains `UTF-8 text` and does **not** contain `CRLF`.

- [ ] **Step 4: Commit**

```bash
git add docs/ai-agents/pico-de-gallo-hal-examples.md
git commit -m "docs(repo): scaffold AI-agent guide for pico-de-gallo-hal

Add empty section skeleton at docs/ai-agents/pico-de-gallo-hal-examples.md.
Subsequent commits fill each section. See spec at
docs/superpowers/specs/2026-06-03-pico-de-gallo-hal-agent-guide-design.md.

Co-authored-by: Copilot <223556219+Copilot@users.noreply.github.com>
Assisted-by: <AGENT>:<MODEL>"
```

---

## Task 2: Fill §1 TL;DR

**Files:**
- Modify: `docs/ai-agents/pico-de-gallo-hal-examples.md` (replace the `<!-- filled in Task 2 -->` placeholder)

- [ ] **Step 1: Replace the §1 placeholder**

Replace exactly this string:

```
## 1. TL;DR

<!-- filled in Task 2 -->
```

with:

```
## 1. TL;DR

You are generating either a host-side **example binary** at
`examples/<chip>.rs` or a **hardware-in-the-loop test** gated behind
`#[cfg(feature = "hil")]`. Both shapes exercise an `embedded-hal`
driver against real hardware through a Pico de Gallo USB bridge.

Decide which shape to produce (§2), pick blocking or async (§3), set
up `Cargo.toml` (§4), look up which HAL accessor your device needs
(§5 decision tree → §6 per-peripheral reference), drop a fixed-format
decision-log header at the top of the generated file (§10.7 below),
and verify against the checklist in §8.

The HAL exposes I²C, SPI, GPIO, PWM, ADC, 1-Wire, UART, and Delay.
Pin range for any GPIO is **0..=3** (the firmware only exposes four
pins). The HAL is `pico-de-gallo-hal` on crates.io.
```

- [ ] **Step 2: Confirm placeholder is gone**

```bash
grep -n "filled in Task 2" docs/ai-agents/pico-de-gallo-hal-examples.md
```
Expected: no output (exit 1).

- [ ] **Step 3: Confirm LF endings**

```bash
file docs/ai-agents/pico-de-gallo-hal-examples.md
```
Expected: no `CRLF`.

- [ ] **Step 4: Commit**

```bash
git add docs/ai-agents/pico-de-gallo-hal-examples.md
git commit -m "docs(repo): fill TL;DR section in HAL agent guide

Co-authored-by: Copilot <223556219+Copilot@users.noreply.github.com>
Assisted-by: <AGENT>:<MODEL>"
```

---

## Task 3: Fill §2 Output-shape rule

**Files:**
- Modify: `docs/ai-agents/pico-de-gallo-hal-examples.md` (replace `<!-- filled in Task 3 -->`)

- [ ] **Step 1: Replace the §2 placeholder**

Replace:

```
## 2. Output-shape rule (binary vs. HIL test)

<!-- filled in Task 3 -->
```

with:

```
## 2. Output-shape rule (binary vs. HIL test)

**Default: binary at `examples/<chip>.rs`.**

Pick **HIL test** (`#[cfg(feature = "hil")] #[test]` inside a driver
crate, gated behind a `hil` Cargo feature) only when **at least one**
of these is true:

- The user explicitly says "test", "validate the driver", "regression
  test", "CI", or "hardware-in-the-loop".
- The user names an existing driver crate they want regression
  coverage for.

Otherwise produce the binary. "Show me X works", "make X blink",
"read a value from X", and bring-up scripts are all binary requests.

If both shapes seem to fit, default to binary; binaries are easier to
run by hand and the user can always wrap one in a test later.

The HIL-test shape pattern is:

\`\`\`rust
#[cfg(feature = "hil")]
#[test]
fn <chip>_<assertion>() {
    let hal = pico_de_gallo_hal::Hal::new();
    // ... assert something the user would actually want to know
    //     is true for their hardware ...
}
\`\`\`

Gate it in the driver crate's `Cargo.toml`:

\`\`\`toml
[features]
default = []
hil = ["dep:pico-de-gallo-hal"]

[dev-dependencies]
pico-de-gallo-hal = { version = "*", optional = true }
\`\`\`
```

> **Important:** the literal backticks in the example above must be
> escaped (`` \` ``) when typing into the markdown so they render
> inside the outer fenced block. In the actual file content, write
> ordinary backticks — the escape characters in this plan are only
> there so the plan itself can show the code fence. **Strip the
> backslashes when writing to the file.**

- [ ] **Step 2: Confirm placeholder is gone and backticks render correctly**

```bash
grep -n "filled in Task 3" docs/ai-agents/pico-de-gallo-hal-examples.md
grep -c '\\`' docs/ai-agents/pico-de-gallo-hal-examples.md
```
Expected: first grep no output (exit 1); second grep prints `0` (no escaped backticks left in the file).

- [ ] **Step 3: Confirm LF endings**

```bash
file docs/ai-agents/pico-de-gallo-hal-examples.md
```
Expected: no `CRLF`.

- [ ] **Step 4: Commit**

```bash
git add docs/ai-agents/pico-de-gallo-hal-examples.md
git commit -m "docs(repo): fill output-shape rule in HAL agent guide

Default to a host-side binary; switch to HIL test only on explicit
signals (test/CI keywords or named driver crate).

Co-authored-by: Copilot <223556219+Copilot@users.noreply.github.com>
Assisted-by: <AGENT>:<MODEL>"
```

---

## Task 4: Fill §3 Sync-vs-async rule

**Files:**
- Modify: `docs/ai-agents/pico-de-gallo-hal-examples.md` (replace `<!-- filled in Task 4 -->`)

- [ ] **Step 1: Replace the §3 placeholder**

Replace:

```
## 3. Sync-vs-async rule

<!-- filled in Task 4 -->
```

with:

```
## 3. Sync-vs-async rule

Selection algorithm, in order:

1. If the driver crate's primary API is `async fn` → **async**
   (`#[tokio::main]`).
2. If the driver crate's primary API is blocking → **blocking**.
3. If the driver crate offers both → **blocking** (simpler).
4. If the example needs GPIO edge waits (the `Wait` trait:
   `wait_for_falling_edge`, etc.) → **async** regardless of (1)–(3).
5. If both async edge waits **and** blocking driver methods are
   needed → **async**. The HAL's `block_in_place` plumbing lets
   blocking trait calls run inside a tokio task, **but read the
   warning below first**.

> ### ⚠ Mandatory: never use `current_thread` tokio
>
> If you pick async, you MUST use the **default multi-thread**
> tokio runtime:
>
> - `#[tokio::main]` — correct.
> - `#[tokio::main(flavor = "current_thread")]` — **will panic**
>   the first time a driver issues a blocking I²C, SPI, GPIO,
>   UART, PWM, ADC, or 1-Wire call.
>
> The HAL detects "in async context" but cannot detect runtime
> flavor (see `Hal::in_async_context` in `lib.rs:463`), so it
> unconditionally calls `tokio::task::block_in_place`, which tokio
> documents as panicking on single-threaded runtimes.

Default tokio dep when async is chosen:

\`\`\`toml
tokio = { version = "1", features = ["rt-multi-thread", "macros", "time"] }
\`\`\`

Do **not** add `"current_thread"` to the feature list and do **not**
override the flavor.

(Remember to strip the backslash-backticks shown in the plan — write
real backticks to the file.)
```

- [ ] **Step 2: Verify placeholder is gone**

```bash
grep -n "filled in Task 4" docs/ai-agents/pico-de-gallo-hal-examples.md
```
Expected: no output (exit 1).

- [ ] **Step 3: Confirm the `current_thread` warning is present**

```bash
grep -c "current_thread" docs/ai-agents/pico-de-gallo-hal-examples.md
```
Expected: at least `3` (warning header, prose, "do not" line).

- [ ] **Step 4: Commit**

```bash
git add docs/ai-agents/pico-de-gallo-hal-examples.md
git commit -m "docs(repo): fill sync-vs-async rule in HAL agent guide

Selection algorithm plus mandatory warning about current_thread tokio
runtimes panicking on block_in_place. See spec §10.3.

Co-authored-by: Copilot <223556219+Copilot@users.noreply.github.com>
Assisted-by: <AGENT>:<MODEL>"
```

---

## Task 5: Fill §4 Cargo setup

**Files:**
- Modify: `docs/ai-agents/pico-de-gallo-hal-examples.md` (replace `<!-- filled in Task 5 -->`)

- [ ] **Step 1: Replace the §4 placeholder**

Replace:

```
## 4. Cargo setup

<!-- filled in Task 5 -->
```

with:

```
## 4. Cargo setup

This file does not pin versions. Resolve current versions from
crates.io when you edit `Cargo.toml`. The crates you need are:

- `pico-de-gallo-hal` — the HAL itself. Goes in `[dependencies]` for
  binaries, `[dev-dependencies]` (optional, gated by the `hil`
  feature) for HIL tests.
- `embedded-hal` — required if your driver returns
  `embedded_hal::*::Error` types.
- `embedded-hal-async` — required only if you use async traits
  (`embedded_hal_async::digital::Wait`, etc.).
- `tokio` — required only if async, with features
  `["rt-multi-thread", "macros", "time"]`. **Do not** pick
  `current_thread` — see §3.
- `pico-de-gallo-lib` — required directly when you need
  `AdcChannel`, `GpioDirection`, `GpioPull`, `GpioEdge`,
  `AdcConfigurationInfo`, or `PicoDeGallo::uart_set_config` (none
  of these are re-exported by the HAL).
- The driver crate(s) for the device you're exercising.

Re-exported by `pico_de_gallo_hal` (no extra dependency needed):
`GpioEvent`, `I2cFrequency`, `SpiConfigurationInfo`, `SpiPhase`,
`SpiPolarity`, `UartConfigurationInfo`.
```

- [ ] **Step 2: Verify placeholder is gone**

```bash
grep -n "filled in Task 5" docs/ai-agents/pico-de-gallo-hal-examples.md
```
Expected: no output (exit 1).

- [ ] **Step 3: Commit**

```bash
git add docs/ai-agents/pico-de-gallo-hal-examples.md
git commit -m "docs(repo): fill Cargo setup in HAL agent guide

Name the crates without pinning versions; downstream skill resolves.
Document re-exports vs. types that require depending on
pico-de-gallo-lib directly (AdcChannel, GpioDirection, etc.).

Co-authored-by: Copilot <223556219+Copilot@users.noreply.github.com>
Assisted-by: <AGENT>:<MODEL>"
```

---

## Task 6: Fill §5 Peripheral decision tree

**Files:**
- Modify: `docs/ai-agents/pico-de-gallo-hal-examples.md` (replace `<!-- filled in Task 6 -->`)

- [ ] **Step 1: Replace the §5 placeholder**

Replace:

```
## 5. Peripheral decision tree

<!-- filled in Task 6 -->
```

with:

```
## 5. Peripheral decision tree

| Your device…                                          | Jump to       |
|-------------------------------------------------------|---------------|
| Talks I²C (sensor, EEPROM, expander)                  | §6.1          |
| Talks SPI, driver manages CS itself                   | §6.2          |
| Talks SPI, you provide a CS pin (typical)             | §6.3          |
| Is an LED, relay, or reset line (drives a level)      | §6.4          |
| Is a button or switch you poll                        | §6.5          |
| Is a button you wait on (edge-triggered)              | §6.6          |
| Needs streamed edge events (rotary encoder, etc.)     | §6.7          |
| Is a motor or LED needing a duty cycle                | §6.8          |
| Is an analog input (potentiometer, thermistor)        | §6.9          |
| Is a 1-Wire device (DS18B20, DS2401)                  | §6.10         |
| Talks UART or serial                                  | §6.11         |
| The driver needs `&mut impl DelayNs`                  | §6.12         |

Most drivers combine 2–3 of these (e.g. SPI device + GPIO output for
reset + Delay). Pull each one in from its subsection independently.
```

- [ ] **Step 2: Verify**

```bash
grep -n "filled in Task 6" docs/ai-agents/pico-de-gallo-hal-examples.md
```
Expected: no output.

- [ ] **Step 3: Commit**

```bash
git add docs/ai-agents/pico-de-gallo-hal-examples.md
git commit -m "docs(repo): fill peripheral decision tree in HAL agent guide

Co-authored-by: Copilot <223556219+Copilot@users.noreply.github.com>
Assisted-by: <AGENT>:<MODEL>"
```

---

## Task 7: Fill §6 — replace the bulk placeholder with subsection scaffolding, then fill §6.1 (I²C, Deep)

**Files:**
- Modify: `docs/ai-agents/pico-de-gallo-hal-examples.md`

- [ ] **Step 1: Replace the §6 placeholder with subsection scaffolding**

Replace:

```
## 6. Per-peripheral reference

<!-- filled in Tasks 7–11 -->
```

with:

```
## 6. Per-peripheral reference

### 6.1 I²C

<!-- filled in Task 7 -->

### 6.2 SPI bus (no CS)

<!-- filled in Task 11 -->

### 6.3 SPI device (with CS)

<!-- filled in Task 8 -->

### GPIO subsections (§§6.4–6.7) — read first

<!-- pin-state machine table filled in Task 9 -->

### 6.4 GPIO output

<!-- filled in Task 9 -->

### 6.5 GPIO input

<!-- filled in Task 9 -->

### 6.6 GPIO async wait

<!-- filled in Task 9 -->

### 6.7 GPIO subscribe (push events)

<!-- filled in Task 10 -->

### 6.8 PWM

<!-- filled in Task 11 -->

### 6.9 ADC

<!-- filled in Task 11 -->

### 6.10 1-Wire

<!-- filled in Task 11 -->

### 6.11 UART

<!-- filled in Task 11 -->

### 6.12 Delay

<!-- filled in Task 11 -->
```

- [ ] **Step 2: Replace the §6.1 placeholder with the full I²C subsection**

Replace:

```
### 6.1 I²C

<!-- filled in Task 7 -->
```

with:

```
### 6.1 I²C

**When to use:** the device is on an I²C bus and uses 7-bit addressing.

**HAL accessor:** `hal.i2c()` → returns `I2c`.

**Traits implemented:** `embedded_hal::i2c::I2c`,
`embedded_hal_async::i2c::I2c`.

#### Snippet — binary form

\`\`\`rust
// examples/<chip>.rs
// pico-de-gallo decision log:
//   shape:        binary
//   sync/async:   sync (reason: driver is blocking)
//   peripherals:  i2c
//   hal version:  <crate version observed at generation time>

use embedded_hal::i2c::I2c;
use pico_de_gallo_hal::Hal;

fn main() {
    let hal = Hal::new();
    let mut i2c = hal.i2c();

    let mut buf = [0u8; 2];
    i2c.write_read(0x48, &[0x00], &mut buf).unwrap();
    println!("raw: {:02x?}", buf);
}
\`\`\`

#### Snippet — HIL-test form

\`\`\`rust
#[cfg(feature = "hil")]
#[test]
fn tmp102_responds_on_default_address() {
    use embedded_hal::i2c::I2c;
    let hal = pico_de_gallo_hal::Hal::new();
    let mut i2c = hal.i2c();
    let mut buf = [0u8; 2];
    // A successful write_read with an ACK proves the device is wired.
    i2c.write_read(0x48, &[0x00], &mut buf).unwrap();
}
\`\`\`

#### Gotchas

- 7-bit addressing only. Pass `0x48`, not `0x90`.
- `I2c::transaction()` (and `write_read`) is batched as a single USB
  round-trip by the HAL — prefer it over separate `write` + `read`.
- Default bus frequency is 100 kHz. Bump with
  `hal.i2c_set_config(I2cFrequency::Fast)?` for 400 kHz or
  `I2cFrequency::FastPlus` for 1 MHz.
- Async usage: see §3 for the mandatory `current_thread` warning.

#### Config knobs

- `hal.i2c_set_config(I2cFrequency)` — bus frequency. Default
  `Standard` (100 kHz). Variants: `Standard`, `Fast`, `FastPlus`.
- `hal.i2c_get_config() -> Result<I2cFrequency, _>` — read current
  frequency.
- `hal.i2c_scan(include_reserved: bool) -> Result<Vec<u8>, _>` —
  scan for devices. `false` scans `0x08..=0x77`, `true` scans the
  full `0x00..=0x7F`.
```

(Strip the `\`` escapes; write real backticks.)

- [ ] **Step 3: Run the verification grep**

```bash
grep -oE '(hal\.[a-z_]+\()|(Hal::[a-z_]+\b)' \
    docs/ai-agents/pico-de-gallo-hal-examples.md | sort -u
```
Expected: every name should be one of `hal.i2c(`, `hal.i2c_set_config(`, `hal.i2c_get_config(`, `hal.i2c_scan(` — all of which match `pub fn` entries in `crates/pico-de-gallo-hal/src/lib.rs`. Confirm by:

```bash
grep -oE 'pub fn [a-z_]+' crates/pico-de-gallo-hal/src/lib.rs | sort -u
```

- [ ] **Step 4: Confirm LF endings**

```bash
file docs/ai-agents/pico-de-gallo-hal-examples.md
```
Expected: no `CRLF`.

- [ ] **Step 5: Commit**

```bash
git add docs/ai-agents/pico-de-gallo-hal-examples.md
git commit -m "docs(repo): scaffold §6 and fill I²C subsection in HAL agent guide

§6 now contains placeholders for all 12 peripheral subsections.
§6.1 (I²C, Deep tier) is fully populated: when-to-use, accessor,
traits, binary snippet, HIL-test snippet, gotchas, config knobs.

Co-authored-by: Copilot <223556219+Copilot@users.noreply.github.com>
Assisted-by: <AGENT>:<MODEL>"
```

---

## Task 8: Fill §6.3 SPI device with CS (Deep)

**Files:**
- Modify: `docs/ai-agents/pico-de-gallo-hal-examples.md`

- [ ] **Step 1: Replace the §6.3 placeholder**

Replace:

```
### 6.3 SPI device (with CS)

<!-- filled in Task 8 -->
```

with:

```
### 6.3 SPI device (with CS)

**When to use:** the device is on an SPI bus and you provide a GPIO
pin as chip-select. This is the common case — most drivers expect an
`SpiDevice` that wraps CS handling for them.

**HAL accessor:** `hal.spi_device(cs_pin)` → returns
`Result<SpiDev, SpiHalError>`. CS pin range: `0..=3`.

**Traits implemented:** `embedded_hal::spi::SpiDevice`,
`embedded_hal_async::spi::SpiDevice`.

#### Snippet — binary form

\`\`\`rust
// examples/<chip>.rs
// pico-de-gallo decision log:
//   shape:        binary
//   sync/async:   sync (reason: driver is blocking)
//   peripherals:  spi_device(cs=0)
//   hal version:  <crate version observed at generation time>

use pico_de_gallo_hal::Hal;
use <driver_crate>::Driver;

fn main() {
    let hal = Hal::new();
    let spi = hal.spi_device(0).expect("spi_device failed");
    let mut driver = Driver::new(spi);
    // ... use driver ...
}
\`\`\`

#### Snippet — HIL-test form

\`\`\`rust
#[cfg(feature = "hil")]
#[test]
fn driver_who_am_i_matches_datasheet() {
    let hal = pico_de_gallo_hal::Hal::new();
    let spi = hal.spi_device(0).unwrap();
    let mut driver = <DriverCrate>::new(spi);
    assert_eq!(driver.who_am_i().unwrap(), 0xAB);
}
\`\`\`

#### Gotchas

- CS pin range is `0..=3`. The pin **must not** also be used as a
  `Gpio` elsewhere in the program (no concurrent ownership).
- The async `SpiDevice::transaction` is **not** cancellation-safe:
  if the future is dropped after CS is asserted low but before it is
  deasserted, CS stays low. Match the behavior of
  `embedded-hal-bus::ExclusiveDevice`.
- `Operation::TransferInPlace(buf)` works, but the implementation
  allocates a `Vec` the same size as `buf` per occurrence in a
  transaction. For large in-place transfers prefer
  `Operation::Transfer(read, write)` with two buffers.
- Async usage: see §3 for the mandatory `current_thread` warning.

#### Config knobs

- `hal.spi_set_config(freq_hz, SpiPhase, SpiPolarity)` — clock
  frequency, phase, polarity. Defaults: 1 MHz,
  `SpiPhase::CaptureOnFirstTransition`, `SpiPolarity::IdleLow`
  (mode 0).
- `hal.spi_get_config() -> Result<SpiConfigurationInfo, _>` — read
  back current configuration.
```

- [ ] **Step 2: Verification grep**

```bash
grep -oE '(hal\.[a-z_]+\()|(Hal::[a-z_]+\b)' \
    docs/ai-agents/pico-de-gallo-hal-examples.md | sort -u
```
Expected: each new name (`hal.spi_device(`, `hal.spi_set_config(`, `hal.spi_get_config(`) appears as `pub fn` in `crates/pico-de-gallo-hal/src/lib.rs`.

- [ ] **Step 3: Commit**

```bash
git add docs/ai-agents/pico-de-gallo-hal-examples.md
git commit -m "docs(repo): fill §6.3 SPI device subsection

Covers spi_device(cs_pin), CS pin range (0..=3), cancellation-safety
note, TransferInPlace allocation note, and the spi_set_config /
spi_get_config knobs. See spec §10.6.

Co-authored-by: Copilot <223556219+Copilot@users.noreply.github.com>
Assisted-by: <AGENT>:<MODEL>"
```

---

## Task 9: Fill GPIO pin-state-machine table + §§6.4–6.6 (output, input, async wait — Deep)

**Files:**
- Modify: `docs/ai-agents/pico-de-gallo-hal-examples.md`

- [ ] **Step 1: Replace the GPIO pin-state-machine placeholder**

Replace:

```
### GPIO subsections (§§6.4–6.7) — read first

<!-- pin-state machine table filled in Task 9 -->
```

with:

```
### GPIO subsections (§§6.4–6.7) — read first

**Pin range:** `0..=3` (firmware exposes four pins). Any pin number
outside this range returns `GpioError::InvalidPin`.

**Pin state machine** — at any moment a pin is in exactly one of
these states, and only the listed ops are valid:

| State              | Reached by                            | Allowed ops                                                    |
|--------------------|---------------------------------------|----------------------------------------------------------------|
| Unconfigured       | freshly-booted firmware               | `Gpio::set_config(...)` only                                   |
| Output             | `set_config(GpioDirection::Output,_)` | `OutputPin::set_low/high`, `StatefulOutputPin::is_set_low/high`|
| Input              | `set_config(GpioDirection::Input,_)`  | `InputPin::is_low/high`, async `Wait::wait_for_*`              |
| Subscribed (Input) | `hal.gpio_subscribe(pin, edge)`       | receive `GpioEvent`s; **no other ops** until `gpio_unsubscribe`|

Cross-state transitions: call `set_config(...)` again to flip
direction; call `gpio_unsubscribe(pin)` to leave Subscribed. **A pin
that is Subscribed cannot also be wait()'d on or read/written**: the
firmware returns `GpioError::PinMonitored`.

`use pico_de_gallo_lib::{GpioDirection, GpioPull, GpioEdge};` —
these are not re-exported by the HAL.
```

- [ ] **Step 2: Replace the §6.4 placeholder (GPIO output)**

Replace:

```
### 6.4 GPIO output

<!-- filled in Task 9 -->
```

with:

```
### 6.4 GPIO output

**When to use:** drive a line high or low — LED, relay, reset line,
manual CS pin (only if you're **not** using `hal.spi_device(cs)`).

**HAL accessor:** `hal.gpio(pin)` → returns `Gpio`. Pin range
`0..=3`.

**Traits implemented:** `embedded_hal::digital::OutputPin`,
`embedded_hal::digital::StatefulOutputPin`.

#### Snippet — binary form

\`\`\`rust
// examples/blink.rs
// pico-de-gallo decision log:
//   shape:        binary
//   sync/async:   sync (reason: trivial blocking loop)
//   peripherals:  gpio(0)
//   hal version:  <crate version observed at generation time>

use embedded_hal::digital::OutputPin;
use pico_de_gallo_hal::Hal;
use pico_de_gallo_lib::{GpioDirection, GpioPull};
use std::time::Duration;

fn main() {
    let hal = Hal::new();
    let mut gpio = hal.gpio(0);
    gpio.set_config(GpioDirection::Output, GpioPull::None).unwrap();

    loop {
        gpio.set_high().unwrap();
        std::thread::sleep(Duration::from_secs(1));
        gpio.set_low().unwrap();
        std::thread::sleep(Duration::from_secs(1));
    }
}
\`\`\`

#### Gotchas

- Pin range `0..=3`.
- Call `set_config(Output, _)` before driving the pin — pins boot
  unconfigured.
- The CS pin you pass to `hal.spi_device(cs)` is **not** usable here.
  Don't share pin numbers.
- Async usage: see §3 for the mandatory `current_thread` warning.

#### Config knobs

- `Gpio::set_config(GpioDirection, GpioPull)` — direction + internal
  pull resistor. Variants: `GpioDirection::{Input, Output}`,
  `GpioPull::{None, Up, Down}`. Default after firmware boot: input,
  no pull.
```

- [ ] **Step 3: Replace the §6.5 placeholder (GPIO input)**

Replace:

```
### 6.5 GPIO input

<!-- filled in Task 9 -->
```

with:

```
### 6.5 GPIO input

**When to use:** poll a digital line — a switch, a status pin, a
strap.

**HAL accessor:** `hal.gpio(pin)` → returns `Gpio`. Pin range
`0..=3`.

**Traits implemented:** `embedded_hal::digital::InputPin`.

#### Snippet — binary form

\`\`\`rust
// examples/<chip>.rs
// pico-de-gallo decision log:
//   shape:        binary
//   sync/async:   sync (reason: polled, no edge wait)
//   peripherals:  gpio(1)
//   hal version:  <crate version observed at generation time>

use embedded_hal::digital::InputPin;
use pico_de_gallo_hal::Hal;
use pico_de_gallo_lib::{GpioDirection, GpioPull};

fn main() {
    let hal = Hal::new();
    let mut button = hal.gpio(1);
    button.set_config(GpioDirection::Input, GpioPull::Up).unwrap();

    if button.is_low().unwrap() {
        println!("button pressed");
    }
}
\`\`\`

#### Snippet — HIL-test form

\`\`\`rust
#[cfg(feature = "hil")]
#[test]
fn strap_pin_reads_low_with_pullup() {
    use embedded_hal::digital::InputPin;
    use pico_de_gallo_lib::{GpioDirection, GpioPull};
    let hal = pico_de_gallo_hal::Hal::new();
    let mut pin = hal.gpio(2);
    pin.set_config(GpioDirection::Input, GpioPull::Up).unwrap();
    // Strapped low → pull-up loses, pin reads low.
    assert!(pin.is_low().unwrap());
}
\`\`\`

#### Gotchas

- Pin range `0..=3`.
- Default pull is `None`. For a button-to-ground use
  `GpioPull::Up`; for a button-to-VCC use `GpioPull::Down`.
- For edge-triggered waiting use §6.6; for streamed events §6.7.
- Async usage: see §3 for the mandatory `current_thread` warning.
```

- [ ] **Step 4: Replace the §6.6 placeholder (GPIO async wait)**

Replace:

```
### 6.6 GPIO async wait

<!-- filled in Task 9 -->
```

with:

```
### 6.6 GPIO async wait

**When to use:** block the current async task until a GPIO edge or
level happens. Common for button presses, IRQ lines from sensors,
SPI BUSY/READY pins. **This subsection is the only reason most
examples need to be async.**

**HAL accessor:** `hal.gpio(pin)` → returns `Gpio`. Pin range
`0..=3`.

**Traits implemented:** `embedded_hal_async::digital::Wait` —
methods `wait_for_high`, `wait_for_low`, `wait_for_rising_edge`,
`wait_for_falling_edge`, `wait_for_any_edge`.

#### Snippet — binary form

\`\`\`rust
// examples/button.rs
// pico-de-gallo decision log:
//   shape:        binary
//   sync/async:   async (reason: GPIO Wait trait is async-only)
//   peripherals:  gpio(0)
//   hal version:  <crate version observed at generation time>

use embedded_hal_async::digital::Wait;
use pico_de_gallo_hal::Hal;
use pico_de_gallo_lib::{GpioDirection, GpioPull};

#[tokio::main]               // multi-thread — DO NOT use current_thread
async fn main() {
    let hal = Hal::new();
    let mut button = hal.gpio(0);
    button.set_config(GpioDirection::Input, GpioPull::Up).unwrap();

    loop {
        button.wait_for_falling_edge().await.unwrap();
        println!("pressed");
        button.wait_for_rising_edge().await.unwrap();
        println!("released");
    }
}
\`\`\`

#### Gotchas

- Pin range `0..=3`.
- The pin must be configured as Input first. The default firmware
  state is unconfigured; call `set_config(Input, _)`.
- The pin **must not** also be Subscribed (§6.7) — pick one
  mechanism per pin.
- `#[tokio::main]` only — see §3 for the mandatory `current_thread`
  warning.
```

- [ ] **Step 5: Verification grep**

```bash
grep -oE '(hal\.[a-z_]+\()|(Hal::[a-z_]+\b)' \
    docs/ai-agents/pico-de-gallo-hal-examples.md | sort -u
```
Expected: any new entries (`hal.gpio(`, `hal.gpio_subscribe(`, `hal.gpio_unsubscribe(`) appear as `pub fn` in `crates/pico-de-gallo-hal/src/lib.rs`.

- [ ] **Step 6: Commit**

```bash
git add docs/ai-agents/pico-de-gallo-hal-examples.md
git commit -m "docs(repo): fill GPIO state machine and §§6.4-6.6

GPIO output/input/async-wait subsections with pin-state machine
table at the top of the GPIO area surfacing the Subscribed-vs-other
mutual exclusion (spec §10.2).

Co-authored-by: Copilot <223556219+Copilot@users.noreply.github.com>
Assisted-by: <AGENT>:<MODEL>"
```

---

## Task 10: Fill §6.7 GPIO subscribe (Deep)

**Files:**
- Modify: `docs/ai-agents/pico-de-gallo-hal-examples.md`

- [ ] **Step 1: Replace the §6.7 placeholder**

Replace:

```
### 6.7 GPIO subscribe (push events)

<!-- filled in Task 10 -->
```

with:

```
### 6.7 GPIO subscribe (push events)

**When to use:** the application needs a stream of edge events from
a pin (rotary encoders, repeated button events) without polling and
without holding an async `wait_for_*` future per edge.

**HAL accessors:**

- `hal.gpio_subscribe(pin, edge)` → `Result<(), GpioHalError>` —
  start firmware-side monitoring. `edge` is `GpioEdge::Rising`,
  `Falling`, or `Any`.
- `hal.gpio_unsubscribe(pin)` → `Result<(), GpioHalError>` — stop
  monitoring and return the pin to ordinary use.

Push events arrive on the `"gpio/event"` topic as `GpioEvent` values.
**Receiving them from the HAL is not currently exposed as a typed
stream**; for end-to-end push handling you may need to drop down to
`pico_de_gallo_lib::PicoDeGallo` directly.

**Traits implemented:** n/a (project-specific).

#### Snippet — binary form

\`\`\`rust
// examples/<chip>.rs
// pico-de-gallo decision log:
//   shape:        binary
//   sync/async:   sync (reason: subscribe/unsubscribe are blocking calls)
//   peripherals:  gpio_subscribe(2)
//   hal version:  <crate version observed at generation time>

use pico_de_gallo_hal::Hal;
use pico_de_gallo_lib::{GpioDirection, GpioEdge, GpioPull};

fn main() {
    let hal = Hal::new();

    // Configure the pin as Input first.
    let mut pin = hal.gpio(2);
    pin.set_config(GpioDirection::Input, GpioPull::Up).unwrap();
    drop(pin);  // release the Gpio handle so the subscription owns it

    hal.gpio_subscribe(2, GpioEdge::Falling).unwrap();
    // Consume GpioEvents via pico_de_gallo_lib::PicoDeGallo if needed.
    // ... eventually:
    hal.gpio_unsubscribe(2).unwrap();
}
\`\`\`

#### Gotchas

- Pin range `0..=3`.
- While subscribed, the pin **cannot** be `is_low`/`is_high`/`set_*`/`wait_for_*`'d.
  Those calls return `GpioError::PinMonitored`. Call
  `hal.gpio_unsubscribe(pin)` first.
- If a previous host process died while holding a subscription,
  subsequent GPIO operations on that pin fail with `PinMonitored`
  until the firmware is reset. **The HAL does not expose a recovery
  method.** Recover by power-cycling the board, or by depending on
  `pico-de-gallo-lib` directly and calling
  `PicoDeGallo::system_reset_subscriptions().await`.
- The HAL does not currently surface push events as a stream. For
  full producer/consumer behavior you'll need
  `pico-de-gallo-lib` directly.
```

- [ ] **Step 2: Verification grep**

```bash
grep -oE '(hal\.[a-z_]+\()|(Hal::[a-z_]+\b)' \
    docs/ai-agents/pico-de-gallo-hal-examples.md | sort -u
```
Expected: `hal.gpio_subscribe(`, `hal.gpio_unsubscribe(` both match `pub fn` entries.

- [ ] **Step 3: Commit**

```bash
git add docs/ai-agents/pico-de-gallo-hal-examples.md
git commit -m "docs(repo): fill §6.7 GPIO subscribe subsection

Documents subscribe/unsubscribe, the PinMonitored failure mode after
a host crash, and the HAL's lack of a recovery accessor (spec §10.2).

Co-authored-by: Copilot <223556219+Copilot@users.noreply.github.com>
Assisted-by: <AGENT>:<MODEL>"
```

---

## Task 11: Fill §§6.2, 6.8–6.12 (SPI bus, PWM, ADC, 1-Wire, UART, Delay — Medium + Stub)

**Files:**
- Modify: `docs/ai-agents/pico-de-gallo-hal-examples.md`

This task fills six remaining subsections. Three are Medium (SPI bus, ADC, 1-Wire) and three are Stub (PWM, UART, Delay), per spec §9.

- [ ] **Step 1: Replace §6.2 (SPI bus, Medium)**

Replace:

```
### 6.2 SPI bus (no CS)

<!-- filled in Task 11 -->
```

with:

```
### 6.2 SPI bus (no CS)

**When to use:** rarely — only when the driver crate manages chip
select itself (passes its own GPIO handle, talks to a non-CS device,
or daisy-chains). Otherwise prefer §6.3.

**HAL accessor:** `hal.spi()` → returns `Spi`.

**Traits implemented:** `embedded_hal::spi::SpiBus`,
`embedded_hal_async::spi::SpiBus`.

\`\`\`rust
use embedded_hal::spi::SpiBus;
use pico_de_gallo_hal::Hal;

fn main() {
    let hal = Hal::new();
    let mut spi = hal.spi();

    let tx = [0xAA, 0x55];
    let mut rx = [0u8; 2];
    spi.transfer(&mut rx, &tx).unwrap();
    println!("rx: {:02x?}", rx);
}
\`\`\`

#### Gotchas

- No automatic CS. The bus is always live.
- Config knobs are shared with §6.3: `hal.spi_set_config(...)` and
  `hal.spi_get_config()`.
- Async usage: see §3 for the mandatory `current_thread` warning.
```

- [ ] **Step 2: Replace §6.8 (PWM, Stub)**

Replace:

```
### 6.8 PWM

<!-- filled in Task 11 -->
```

with:

```
### 6.8 PWM

**When to use:** the device needs a duty-cycle waveform — motor
ESCs, dimmable LEDs, servo control.

**HAL accessor:** `hal.pwm_channel(channel)` → returns `PwmChannel`.
Channels `0..=3` (channels 0/1 share slice 6 on GPIO 12/13, channels
2/3 share slice 7 on GPIO 14/15).

\`\`\`rust
use embedded_hal::pwm::SetDutyCycle;
use pico_de_gallo_hal::Hal;

fn main() {
    let mut hal = Hal::new();
    hal.pwm_set_config(0, 1_000, false).unwrap();  // 1 kHz, edge-aligned
    let mut ch = hal.pwm_channel(0);
    ch.set_duty_cycle_percent(50).unwrap();
}
\`\`\`

Gotchas: `pwm_set_config(channel, freq_hz, phase_correct)` affects
the whole slice — channels 0/1 cannot use different frequencies, and
neither can 2/3. Async usage: see §3 for the mandatory
`current_thread` warning. See
[`pico-de-gallo-hal` docs.rs](https://docs.rs/pico-de-gallo-hal) for
the full surface.
```

- [ ] **Step 3: Replace §6.9 (ADC, Medium)**

Replace:

```
### 6.9 ADC

<!-- filled in Task 11 -->
```

with:

```
### 6.9 ADC

**When to use:** read an analog input — potentiometer, thermistor,
battery voltage.

**HAL accessor:** `hal.adc_read(channel)` →
`Result<u16, AdcHalError>`. There is **no `embedded-hal` 1.0 ADC
trait**, so this is a project-specific method.

**Traits implemented:** n/a.

\`\`\`rust
use pico_de_gallo_hal::Hal;
use pico_de_gallo_lib::AdcChannel;  // not re-exported by the HAL

fn main() {
    let hal = Hal::new();
    let raw = hal.adc_read(AdcChannel::Adc0).unwrap();
    let volts = raw as f32 * 3.3 / 4096.0;
    println!("raw: {raw}, V≈{volts:.3}");
}
\`\`\`

#### Snippet — HIL-test form

\`\`\`rust
#[cfg(feature = "hil")]
#[test]
fn adc0_reads_in_valid_range() {
    use pico_de_gallo_lib::AdcChannel;
    let hal = pico_de_gallo_hal::Hal::new();
    let raw = hal.adc_read(AdcChannel::Adc0).unwrap();
    assert!(raw <= 4095, "12-bit ADC must be ≤ 4095, got {raw}");
}
\`\`\`

#### Gotchas

- `AdcChannel` is **not** re-exported by the HAL. Add
  `pico-de-gallo-lib` to your dependencies and
  `use pico_de_gallo_lib::AdcChannel;`.
- 12-bit raw value (`0..=4095`). Convert with `raw × 3.3 / 4096`.
- Use `hal.adc_get_config()` for resolution/reference details
  (returns `AdcConfigurationInfo`).
- Async usage: see §3 for the mandatory `current_thread` warning.
```

- [ ] **Step 4: Replace §6.10 (1-Wire, Medium)**

Replace:

```
### 6.10 1-Wire

<!-- filled in Task 11 -->
```

with:

```
### 6.10 1-Wire

**When to use:** the device is on a Dallas/Maxim 1-Wire bus — DS18B20
temperature sensor, DS2401 silicon serial number, etc.

**HAL accessor:** `hal.onewire()` → returns `OneWire`. No
`embedded-hal` 1-Wire trait exists.

**Traits implemented:** n/a.

\`\`\`rust
use pico_de_gallo_hal::Hal;

fn main() {
    let hal = Hal::new();
    let ow = hal.onewire();

    let present = ow.reset().unwrap();
    println!("device present: {present}");

    // Issue ROM-skip + convert-T to all devices on the bus.
    ow.write(&[0xCC, 0x44]).unwrap();
}
\`\`\`

Available methods: `reset()`, `read(len)`, `write(data)`,
`write_pullup(data, pullup_ms)`, `search()`, `search_next()`.

#### Snippet — HIL-test form

\`\`\`rust
#[cfg(feature = "hil")]
#[test]
fn onewire_bus_has_at_least_one_device() {
    let hal = pico_de_gallo_hal::Hal::new();
    let ow = hal.onewire();
    assert!(ow.reset().unwrap(), "no 1-Wire device responded");
}
\`\`\`

#### Gotchas

- Enumerate devices with `search()` for the first address, then
  `search_next()` until it returns `None`.
- Parasitic-power parts (DS18B20 in 2-wire mode) need
  `write_pullup(data, pullup_ms)` to hold the line high after the
  convert command.
- Async usage: see §3 for the mandatory `current_thread` warning.
```

- [ ] **Step 5: Replace §6.11 (UART, Stub)**

Replace:

```
### 6.11 UART

<!-- filled in Task 11 -->
```

with:

```
### 6.11 UART

**When to use:** the device speaks serial — a GPS module, a
debug-port-on-UART chip, AT-command modem.

**HAL accessor:** `hal.uart()` → returns `Uart`. Implements
`embedded_io::{Read,Write}` and `embedded_io_async::{Read,Write}`.

\`\`\`rust
use embedded_io::Write as _;
use pico_de_gallo_hal::Hal;

fn main() {
    let hal = Hal::new();
    let mut uart = hal.uart();
    uart.write_all(b"AT\r\n").unwrap();
}
\`\`\`

Gotchas: read uses a timeout (default 1000 ms). Set with
`uart.set_timeout_ms(0)` for non-blocking. **Baud rate is fixed at
the firmware default. The HAL does not expose a baud-rate setter** —
to change baud, depend on `pico-de-gallo-lib` and call
`PicoDeGallo::uart_set_config(...)` directly. Async usage: see §3
for the mandatory `current_thread` warning. See
[`pico-de-gallo-hal` docs.rs](https://docs.rs/pico-de-gallo-hal) for
the full surface.
```

- [ ] **Step 6: Replace §6.12 (Delay, Stub)**

Replace:

```
### 6.12 Delay

<!-- filled in Task 11 -->
```

with:

```
### 6.12 Delay

**When to use:** the driver wants `&mut impl DelayNs` for
register-settle delays, reset sequences, sensor warm-up.

**HAL accessor:** `hal.delay()` → returns `Delay`. Implements
`embedded_hal::delay::DelayNs` and
`embedded_hal_async::delay::DelayNs`.

\`\`\`rust
use pico_de_gallo_hal::Hal;

fn main() {
    let hal = Hal::new();
    let i2c = hal.i2c();
    let mut delay = hal.delay();
    let mut sensor = MyDriver::new(i2c);
    sensor.init(&mut delay).unwrap();
}
\`\`\`

Gotchas: blocking `Delay` uses `std::thread::sleep`; async `Delay`
uses `tokio::time::sleep`. Pass `&mut delay` by-mutable-reference to
driver methods. See
[`pico-de-gallo-hal` docs.rs](https://docs.rs/pico-de-gallo-hal) for
the full surface.
```

- [ ] **Step 7: Verification grep**

```bash
grep -oE '(hal\.[a-z_]+\()|(Hal::[a-z_]+\b)' \
    docs/ai-agents/pico-de-gallo-hal-examples.md | sort -u
```
Expected: every name resolves to a `pub fn` in
`crates/pico-de-gallo-hal/src/lib.rs`. Cross-check against:

```bash
grep -oE 'pub fn [a-z_]+' crates/pico-de-gallo-hal/src/lib.rs | sort -u
```

- [ ] **Step 8: Confirm no placeholders remain in §6**

```bash
grep -n "filled in Task" docs/ai-agents/pico-de-gallo-hal-examples.md
```
Expected: only matches in the §7, §8, §9 placeholders for the next tasks.

- [ ] **Step 9: Commit**

```bash
git add docs/ai-agents/pico-de-gallo-hal-examples.md
git commit -m "docs(repo): fill §§6.2, 6.8-6.12 — SPI bus, PWM, ADC, 1-Wire, UART, Delay

Medium and Stub tiers per spec §9. ADC subsection notes AdcChannel is
not re-exported (spec §10.5). UART subsection states baud cannot be
set via the HAL (spec §10.4).

Co-authored-by: Copilot <223556219+Copilot@users.noreply.github.com>
Assisted-by: <AGENT>:<MODEL>"
```

---

## Task 12: Fill §7 Worked end-to-end example

**Files:**
- Modify: `docs/ai-agents/pico-de-gallo-hal-examples.md`

- [ ] **Step 1: Replace the §7 placeholder**

Replace:

```
## 7. Worked end-to-end example

<!-- filled in Task 12 -->
```

with:

```
## 7. Worked end-to-end example

A complete `examples/shtc3.rs` for the Sensirion SHTC3 temperature
+ humidity sensor. The four-line decision log at the top is
**mandatory** in every generated example — same prefixes, same
order, four lines exactly.

\`\`\`rust
// examples/shtc3.rs
// pico-de-gallo decision log:
//   shape:        binary
//   sync/async:   sync (reason: shtcx is blocking; no edge wait needed)
//   peripherals:  i2c, delay
//   hal version:  0.6

use pico_de_gallo_hal::Hal;
use shtcx::{shtc3, PowerMode};

fn main() {
    let hal = Hal::new();
    let i2c = hal.i2c();           // §6.1
    let mut delay = hal.delay();   // §6.12

    let mut sensor = shtc3(i2c);
    let m = sensor.measure(PowerMode::NormalMode, &mut delay).unwrap();

    println!(
        "{:.2} °C / {:.2} %RH",
        m.temperature.as_degrees_celsius(),
        m.humidity.as_percent(),
    );
}
\`\`\`

Decision-log format — **literal, four lines, exact prefixes**:

\`\`\`text
// pico-de-gallo decision log:
//   shape:        binary | hil-test
//   sync/async:   sync | async (reason: …)
//   peripherals:  i2c, gpio(3)
//   hal version:  <crate version observed at generation time>
\`\`\`

Free-form variants are not permitted. The fixed format is
grep-checkable by the maintainer drift-prevention hooks (see §9).
```

- [ ] **Step 2: Confirm the decision-log format block is literal**

```bash
grep -c "pico-de-gallo decision log:" docs/ai-agents/pico-de-gallo-hal-examples.md
```
Expected: at least `2` (once in the worked example, once in the
literal-format spec block). Many of the per-peripheral snippets also
contain it, so the count will be higher — that's fine.

- [ ] **Step 3: Commit**

```bash
git add docs/ai-agents/pico-de-gallo-hal-examples.md
git commit -m "docs(repo): fill worked end-to-end example (shtc3) in HAL agent guide

Demonstrates a complete examples/<chip>.rs with the mandatory
decision-log header. Spec §10.7 format is reproduced verbatim.

Co-authored-by: Copilot <223556219+Copilot@users.noreply.github.com>
Assisted-by: <AGENT>:<MODEL>"
```

---

## Task 13: Fill §8 Completion checklist

**Files:**
- Modify: `docs/ai-agents/pico-de-gallo-hal-examples.md`

- [ ] **Step 1: Replace the §8 placeholder**

Replace:

```
## 8. Completion checklist

<!-- filled in Task 13 -->
```

with:

```
## 8. Completion checklist

Before declaring the example done, verify every one of these:

- [ ] The `Cargo.toml` entries from §4 are present and correct.
- [ ] The chosen output shape (binary vs HIL test) matches the
      user's intent per §2.
- [ ] The sync/async choice follows §3, and if async, the runtime is
      multi-thread (`#[tokio::main]` with **no** `current_thread`
      flavor).
- [ ] Every HAL accessor used appears in the §11-style table
      (i.e. is one of `hal.i2c`, `hal.spi`, `hal.spi_device`,
      `hal.gpio`, `hal.gpio_subscribe`, `hal.gpio_unsubscribe`,
      `hal.pwm_channel`, `hal.adc_read`, `hal.uart`, `hal.delay`,
      `hal.onewire`, or one of their associated `*_set_config`/
      `*_get_config` siblings). No invented APIs.
- [ ] Pin numbers are in range: GPIO `0..=3`, PWM channel `0..=3`,
      ADC channel is an `AdcChannel` enum variant.
- [ ] If using `spi_device(cs)`, the `cs` pin is **not** also used
      as a `Gpio` elsewhere.
- [ ] If using `gpio_subscribe(pin, …)`, a matching
      `gpio_unsubscribe(pin)` exists on every exit path.
- [ ] The mandatory four-line decision-log comment block is at the
      top of the example, with the literal prefixes from §7.
- [ ] If the host can run `cargo check` against the generated file,
      it passes.
```

- [ ] **Step 2: Verify placeholder is gone**

```bash
grep -n "filled in Task 13" docs/ai-agents/pico-de-gallo-hal-examples.md
```
Expected: no output.

- [ ] **Step 3: Commit**

```bash
git add docs/ai-agents/pico-de-gallo-hal-examples.md
git commit -m "docs(repo): fill completion checklist in HAL agent guide

Co-authored-by: Copilot <223556219+Copilot@users.noreply.github.com>
Assisted-by: <AGENT>:<MODEL>"
```

---

## Task 14: Fill §9 Drift-prevention note

**Files:**
- Modify: `docs/ai-agents/pico-de-gallo-hal-examples.md`

- [ ] **Step 1: Replace the §9 placeholder**

Replace:

```
## 9. Drift-prevention note (for maintainers)

<!-- filled in Task 14 -->
```

with:

```
## 9. Drift-prevention note (for maintainers)

This file documents the public surface of `pico-de-gallo-hal`. It is
listed in `AGENTS.md` §15.1 as a parity target for
`crates/pico-de-gallo-hal/src/`. Any PR that changes the HAL public
surface (accessor added/removed/renamed, gotcha discovered, trait
impl changed) must update this file in the same commit. Reviewers
treat omissions as a blocker, not a nit.

**Recommended CI guard (not yet implemented):** a regex check that
extracts every `hal\\.\\w+\\(` and `Hal::\\w+\\b` from this file and
asserts the symbol exists as a `pub fn` in
`crates/pico-de-gallo-hal/src/lib.rs`. A one-liner that catches the
common drift mode:

\`\`\`bash
diff <(grep -oE '(hal\\.[a-z_]+\\()|(Hal::[a-z_]+\\b)' \\
        docs/ai-agents/pico-de-gallo-hal-examples.md | sort -u) \\
     <(grep -oE 'pub fn [a-z_]+' \\
        crates/pico-de-gallo-hal/src/lib.rs | sort -u)
\`\`\`

If the file disagrees with the source, the **source wins** — file an
issue at
<https://github.com/OpenDevicePartnership/pico-de-gallo/issues>.
```

- [ ] **Step 2: Verify no placeholders remain anywhere in the file**

```bash
grep -n "filled in Task" docs/ai-agents/pico-de-gallo-hal-examples.md
```
Expected: no output. **If any match remains, fix it before continuing.**

- [ ] **Step 3: Confirm length is within budget**

```bash
wc -l docs/ai-agents/pico-de-gallo-hal-examples.md
```
Expected: between 500 and 900 lines. If under 500, sections were too
terse — re-read the spec §8 length budget and pad. If over 900,
shorten by removing redundant prose; the per-peripheral templates
must stay intact.

- [ ] **Step 4: Confirm LF endings**

```bash
file docs/ai-agents/pico-de-gallo-hal-examples.md
```
Expected: no `CRLF`.

- [ ] **Step 5: Commit**

```bash
git add docs/ai-agents/pico-de-gallo-hal-examples.md
git commit -m "docs(repo): fill drift-prevention note in HAL agent guide

Names the AGENTS.md §15.1 parity rule as the maintenance contract
and gives a one-liner regex check as the recommended CI guard.

Co-authored-by: Copilot <223556219+Copilot@users.noreply.github.com>
Assisted-by: <AGENT>:<MODEL>"
```

---

## Task 15: Add `AGENTS.md` §15.1 parity row

**Files:**
- Modify: `AGENTS.md` (single row added to §15.1 per-area mapping table)

- [ ] **Step 1: Read the existing §15.1 table to find the right insertion point**

```bash
grep -n "Per-area mapping" AGENTS.md
grep -n "pico-de-gallo-hal/src/" AGENTS.md
```
Expected: the §15.1 mapping table is around lines 750–770. Note the
existing row that mentions `pico-de-gallo-hal/src/...` (one row maps
HAL trait impls to `book/src/crates/hal.md`,
`book/src/driver/*`).

- [ ] **Step 2: Update that row**

The existing row reads:

```markdown
| `pico-de-gallo-hal/src/...` — trait impls                   | `book/src/crates/hal.md`, `book/src/driver/*`                            |
```

Replace it with:

```markdown
| `pico-de-gallo-hal/src/...` — trait impls                   | `book/src/crates/hal.md`, `book/src/driver/*`, `docs/ai-agents/pico-de-gallo-hal-examples.md` |
```

(Only the right-hand cell changes — append
`, docs/ai-agents/pico-de-gallo-hal-examples.md` to the existing
list. Do not change column widths beyond what the new path requires.)

- [ ] **Step 3: Verify the edit**

```bash
grep "pico-de-gallo-hal/src/" AGENTS.md
```
Expected: the row now includes `docs/ai-agents/pico-de-gallo-hal-examples.md`.

- [ ] **Step 4: Confirm LF endings**

```bash
file AGENTS.md
```
Expected: no `CRLF`.

- [ ] **Step 5: Commit**

```bash
git add AGENTS.md
git commit -m "docs(repo): add HAL agent guide to AGENTS.md §15.1 parity map

Treats docs/ai-agents/pico-de-gallo-hal-examples.md as a parity
target for crates/pico-de-gallo-hal/src/, so future HAL surface
changes must update the agent guide in the same PR.

Co-authored-by: Copilot <223556219+Copilot@users.noreply.github.com>
Assisted-by: <AGENT>:<MODEL>"
```

---

## Task 16: Final acceptance-criteria sweep

**Files:** (read-only verification; no edits unless a check fails)

- [ ] **Step 1: Acceptance criterion 1 — structure matches spec §8**

```bash
grep -nE '^## [0-9]\.' docs/ai-agents/pico-de-gallo-hal-examples.md
```
Expected exactly nine matches, in order: 1. TL;DR, 2. Output-shape
rule, 3. Sync-vs-async rule, 4. Cargo setup, 5. Peripheral decision
tree, 6. Per-peripheral reference, 7. Worked end-to-end example,
8. Completion checklist, 9. Drift-prevention note.

- [ ] **Step 2: Acceptance criterion 2 — length and EOL**

```bash
wc -l docs/ai-agents/pico-de-gallo-hal-examples.md
file docs/ai-agents/pico-de-gallo-hal-examples.md
```
Expected: line count between 500 and 900; `file` output contains
`UTF-8 text` and **not** `CRLF`.

- [ ] **Step 3: Acceptance criterion 3 — no fabricated accessors**

```bash
echo "=== names in the doc ==="
grep -oE '(hal\.[a-z_]+\()|(Hal::[a-z_]+\b)' \
    docs/ai-agents/pico-de-gallo-hal-examples.md | sort -u
echo "=== pub fn names in the HAL ==="
grep -oE 'pub fn [a-z_]+' \
    crates/pico-de-gallo-hal/src/lib.rs | sort -u
```
Expected: every entry in the first list is one of: a `pub fn` in the
second list **or** a method on one of the surface types listed in
the conventions block at the top of this plan (`Gpio`, `I2c`, `Spi`,
`SpiDev`, `Uart`, `PwmChannel`, `Delay`, `OneWire`). Inspect by eye.

- [ ] **Step 4: Acceptance criterion 4 — snippets are syntactically valid Rust**

For every fenced Rust block in the file, mentally (or by extraction
+ `rustc --edition 2024 -`) confirm it would parse if dropped into
a fresh crate with the correct deps. Common pitfalls to look for:

- Missing `use` for trait methods (`embedded_hal::digital::OutputPin`
  for `set_high`, etc.).
- Imports of types that aren't re-exported by the HAL
  (`GpioDirection`, `GpioPull`, `GpioEdge`, `AdcChannel`).
- Async snippets using a `current_thread` runtime (must not appear).

If any snippet fails this check, fix it in a follow-up commit:

```bash
git add docs/ai-agents/pico-de-gallo-hal-examples.md
git commit -m "docs(repo): fix syntax in HAL agent guide snippet (<which>)

Co-authored-by: Copilot <223556219+Copilot@users.noreply.github.com>
Assisted-by: <AGENT>:<MODEL>"
```

- [ ] **Step 5: Acceptance criterion 5 — AGENTS.md updated**

```bash
grep "docs/ai-agents/pico-de-gallo-hal-examples.md" AGENTS.md
```
Expected: at least one match (the row appended in Task 15).

- [ ] **Step 6: Acceptance criterion 6 — commit shape**

```bash
git --no-pager log --oneline | head -20
```
Expected: a sequence of 14–16 commits (Tasks 1–15 plus any fix-up
from Step 4 above), all on the current branch, **all** with
Conventional Commit headers using scope `repo` and bodies that
include the `Co-authored-by: Copilot …` and `Assisted-by: …`
trailers. **None** carry `Signed-off-by:`.

Verify trailers on every commit in the series:

```bash
git --no-pager log --format='%H %s%n%b%n---' | head -200
```
Read through and confirm each commit has both trailers and no DCO
sign-off.

- [ ] **Step 7: Push only after the user says so**

Do **not** push. Per `AGENTS.md` §4 hard rule #8, pushing requires
explicit user permission. Report back with:

```bash
git --no-pager log --oneline | head -20
wc -l docs/ai-agents/pico-de-gallo-hal-examples.md
```

and a one-line note that all acceptance criteria pass, then wait
for the user to decide whether to push or open a PR.

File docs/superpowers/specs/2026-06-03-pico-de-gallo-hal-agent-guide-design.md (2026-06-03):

# Spec: AI-Agent Guide for `pico-de-gallo-hal` Examples

- **Date:** 2026-06-03
- **Status:** Draft — pending user approval
- **Scope:** Add one new markdown file to the repository, plus a small
  amount of supporting plumbing, so that an AI coding agent can fetch
  the file over HTTP and use it as a complete recipe for generating a
  working host-side example or HIL test against `pico-de-gallo-hal`.

## 1. Goal

Produce a single markdown file in this repository,
`docs/ai-agents/pico-de-gallo-hal-examples.md`, that is the canonical
reference an AI coding agent consults whenever it is asked to write an
example program or hardware-in-the-loop test exercising an
`embedded-hal` driver against real hardware through a Pico de Gallo USB
bridge.

The file's primary consumer is a future opencode skill called
`generate-pico-de-gallo-example` (or similar). That skill:

- Independently knows Rust, `cargo`, and how to edit `Cargo.toml`.
- Fetches the markdown file over HTTP via `webfetch`.
- Uses the file as the only source of truth for **Pico-de-Gallo-specific
  idioms, API choices, gotchas, and conventions**.

The skill is out of scope for this spec. This spec specifies only the
markdown file (and the small amount of plumbing required to keep it
from drifting from the HAL source).

## 2. Non-goals

- This file is not a Rust tutorial.
- It is not a `cargo` tutorial.
- It does not duplicate `embedded-hal` trait documentation.
- It is not a marketing or onboarding document; the existing
  `book/src/driver/` chapter covers that audience.
- It is not the skill itself.

## 3. Audience

A coding agent (LLM-driven) that has been asked to produce one of:

1. A standalone host-side binary at `examples/<chip>.rs` that runs
   against a real device via Pico de Gallo and prints/asserts
   something interesting.
2. A `#[cfg(feature = "hil")] #[test]` block inside an
   `embedded-hal` driver crate, gated behind a `hil` Cargo feature,
   that exercises the driver against real hardware.

The agent is expected to be reasonably capable but **not** expected to
read `crates/pico-de-gallo-hal/src/lib.rs` itself before generating
output. Anything not covered in the markdown file should be considered
unavailable to the agent for the purposes of producing the example.

## 4. File location and fetch URL

- **Path on disk:** `docs/ai-agents/pico-de-gallo-hal-examples.md`
- **Raw fetch URL:** `https://raw.githubusercontent.com/OpenDevicePartnership/pico-de-gallo/main/docs/ai-agents/pico-de-gallo-hal-examples.md`
- The `docs/ai-agents/` directory is new. It establishes a namespace
  for any future agent-targeted documentation (e.g. a future file for
  `pyco-de-gallo` or for the `gallo` CLI).
- The file is **not** served by mdBook. It is a standalone file
  consumed via raw GitHub content URLs. This is a deliberate choice
  so the agent fetches plain markdown without HTML chrome.
- The file is **MIT-licensed** under the repository's existing top-level
  `LICENSE`. No per-file license header.

## 5. Length budget

- Target: 500–800 lines of markdown.
- Hard ceiling: 900 lines. Above that, the agent's working memory
  starts paying a real cost per fetch.

> **Amendment 2026-06-03** (during implementation): the original
> 400–600 / 700 budget proved too tight once §6 was depth-weighted
> per §9. Six Deep-tier peripherals with full HIL snippets, gotchas,
> and config knobs alone reach ~600 lines; the rules sections,
> decision tree, worked example, and drift note push the total
> above 700. The new 500–800 / 900 budget reflects what good
> coverage actually costs, while still being cheap relative to a
> typical HTML page.

## 6. Tone and voice

- Technical, terse, present tense.
- Matches the voice of the repository's `AGENTS.md`.
- Imperative or declarative; no second-person "you" coaching.
- No emoji.
- No marketing language.
- LF line endings (per repo-wide convention in `.gitattributes`).

## 7. Structural decisions (locked)

These decisions were settled during brainstorming and are not open for
revision in the implementation phase:

| Decision | Choice |
|---|---|
| File purpose | Reference + decision tree (not tutorial, not pure copy-paste). |
| Coverage | Full HAL public surface as it actually exists in `crates/pico-de-gallo-hal/src/lib.rs` (verified against the source — see §11). |
| Sync vs. async | Both documented, with an explicit selection rule. |
| Output shape | Both documented (binary and HIL test), with an explicit selection rule that has a tiebreaker. |
| File location | `docs/ai-agents/pico-de-gallo-hal-examples.md`, raw-served. |
| Internal structure | Option A: TL;DR → rules → decision tree → uniform per-peripheral subsections → worked example → checklist → drift note. |
| Depth | I²C, SPI device (with CS), and GPIO get deep treatment. UART, PWM, ADC, 1-Wire, raw SPI bus, Delay get short stubs. |
| Default execution model | Binary, blocking, unless explicit signals shift the choice. |
| Drift prevention | Add one row to `AGENTS.md` §15.1 mapping table; recommend a one-line CI grep check; full automation is future work. |

## 8. File structure (top-level)

The file is organized into nine numbered sections in this order:

1. **TL;DR** (~10–15 lines)
2. **Output-shape rule** — binary vs. HIL test (~15–25 lines)
3. **Sync-vs-async rule** (~15–25 lines), including a mandatory warning
   about `current_thread` tokio runtimes (see §10.3 below).
4. **Cargo setup** (~10 lines) — pared down to a short paragraph naming
   the crates involved, with no version pins. The downstream skill
   handles version resolution.
5. **Peripheral decision tree** (~20–30 lines) — flat lookup table.
6. **Per-peripheral reference** (~250–350 lines) — twelve subsections,
   uniform template, depth-weighted as described in §9.
7. **Worked end-to-end example** (~40 lines) — one fully-runnable I²C
   binary with a fixed-format decision-log header comment (see §10.7).
8. **Completion checklist** (~15 lines).
9. **Drift-prevention note for maintainers** (~10 lines).

## 9. Depth weighting

The HAL exposes twelve relevant peripheral surfaces. They are not
equally important to a driver-validation workflow. The file treats them
in three tiers:

| Tier | Peripherals | Treatment |
|---|---|---|
| Deep | I²C; SPI device (with CS); GPIO output; GPIO input; GPIO async wait; GPIO subscribe | Full template: when-to-use, accessor, traits, binary snippet, HIL-test snippet, gotchas, config knobs. |
| Medium | SPI bus (no CS); ADC; 1-Wire | Full template **except** the HIL-test snippet may be omitted if no meaningful invariant exists (see §10.4). |
| Stub | PWM; UART; Delay | One-paragraph description + one snippet + gotchas. No HIL-test snippet. Link out to `docs.rs` for more. |

Total peripheral subsections: twelve. Total subsection content:
~250–350 lines.

## 10. Authoritative content rules

These rules govern what the file says about specific HAL behaviors. They
were verified against `crates/pico-de-gallo-hal/src/lib.rs` and
`crates/pico-de-gallo-firmware/src/` during design review. Any
implementation that violates one of these rules is wrong.

### 10.1 GPIO pin range

The firmware exposes exactly **four** GPIO pins, indexed `0..=3`. This
matches `NUM_GPIOS: usize = 4` in
`crates/pico-de-gallo-firmware/src/context.rs:33`.

The file must state pin range as `0..=3` for all GPIO operations
(get, put, set_config, subscribe, wait_for_*, CS pin for `spi_device`).

> Side finding (not in scope here, file as separate issue): the
> doc-comment on `pico-de-gallo-internal/src/lib.rs` says GPIO pin
> range is `0..=7`. That comment contradicts firmware reality.

### 10.2 No `Hal::system_reset_subscriptions` and no `Hal::validate`

The HAL crate **does not** expose `system_reset_subscriptions` or
`validate`. `Hal::new` constructs a `PicoDeGallo` and wraps it in an
`Arc<Mutex<>>`; it does not call either method
(`crates/pico-de-gallo-hal/src/lib.rs:79–120`).

The file must not promise these methods. The GPIO-subscribe gotcha
must say plainly:

> If a previous host process died while holding a subscription,
> subsequent GPIO operations on that pin fail with `GpioError::PinMonitored`.
> The HAL does not expose a recovery method. Recover by power-cycling
> the board, or by depending on `pico-de-gallo-lib` directly and
> calling `PicoDeGallo::system_reset_subscriptions`.

> Side finding (not in scope): adding `Hal::system_reset_subscriptions`
> and `Hal::validate` accessors would close this gap. File as a
> separate issue.

### 10.3 Async footgun: `current_thread` runtimes panic

`Hal::in_async_context()` only checks `Handle::try_current().is_ok()`
(`lib.rs:463`). It cannot distinguish a `current_thread` runtime from
a `multi_thread` one. Every blocking trait impl then unconditionally
calls `tokio::task::block_in_place(...)` — which is documented by tokio
to panic on `current_thread` runtimes.

The sync-vs-async section (§3 of the file) must include a prominent
**mandatory warning**:

> If you pick async, you must use the **default multi-thread** tokio
> runtime: `#[tokio::main]` is correct;
> `#[tokio::main(flavor = "current_thread")]` will panic the first
> time a driver issues a blocking I²C, SPI, GPIO, UART, PWM, ADC, or
> 1-Wire call.

This warning must also be repeated as a one-line gotcha in every
peripheral subsection whose blocking trait impls call `block_in_place`:
I²C, SPI bus, SPI device, GPIO output, GPIO input, PWM, ADC, 1-Wire,
UART. (GPIO async wait uses the native async path and is not
affected.)

### 10.4 No `Hal::uart_set_config`

There is **no** `pub fn uart_set_config` on `Hal`. The only UART-side
mutator the HAL exposes is `Uart::set_timeout_ms` (`lib.rs:1299`).

The file must not promise a `Hal::uart_set_config`. The UART
subsection's gotchas must state plainly:

> Baud rate is fixed at the firmware default. The HAL does not expose
> a baud-rate setter. To change baud, depend on `pico-de-gallo-lib`
> directly and call `PicoDeGallo::uart_set_config`.

> Side finding (not in scope): the doc comment at
> `lib.rs:1282` references a `Hal::uart_set_config` that doesn't
> exist. File as a separate issue.

### 10.5 `AdcChannel` is not re-exported from the HAL

`AdcChannel` is imported in `lib.rs:47` for use in HAL function
signatures, but is not in the `pub use pico_de_gallo_lib::{...}` block
at `lib.rs:56–58`.

The ADC subsection must show the import explicitly:

```rust
use pico_de_gallo_hal::Hal;
use pico_de_gallo_lib::AdcChannel;  // not re-exported by the HAL

let raw = hal.adc_read(AdcChannel::Adc0)?;
```

> Side finding (not in scope): add `AdcChannel` to the HAL's
> `pub use` block. File as a separate issue.

### 10.6 SPI device — `TransferInPlace` allocates

`SpiDev::transaction_inner` allocates a per-operation `Vec<u8>` to
back any `Operation::TransferInPlace` so the batch encoder has a
stable reference (`lib.rs:1116, 1129, 1199, 1212`).

The SPI-device subsection's gotchas must state:

> `Operation::TransferInPlace(buf)` is supported, but the implementation
> allocates a `Vec` of the same size as `buf` for each occurrence in a
> transaction. For large in-place transfers, prefer
> `Operation::Transfer(read, write)` with separate buffers.

### 10.7 Decision-log header — fixed format

The worked-example section (§7 of the file) and the completion
checklist (§8 of the file) must both reference a single fixed
four-line header format that the agent should prepend to every
generated example:

```
// pico-de-gallo decision log:
//   shape:        binary | hil-test
//   sync/async:   sync | async (reason: …)
//   peripherals:  i2c, gpio(3)
//   hal version:  <crate version observed at generation time>
```

The format is mandatory and literal. Free-form variants are not
permitted. (Rationale: a literal format is grep-checkable by the CI
hook described in §13.2 and is consistently reproducible by a
low-thinking model.)

## 11. Verified peripheral surface

The file documents exactly these accessors and types. Each is
verified against `crates/pico-de-gallo-hal/src/lib.rs`. The
implementation phase must not add, remove, or rename any of these.

| Subsection | HAL accessor | Returned handle | Traits implemented | Tier |
|---|---|---|---|---|
| 6.1 I²C | `hal.i2c()` | `I2c` | `embedded_hal::i2c::I2c`, `embedded_hal_async::i2c::I2c` | Deep |
| 6.2 SPI bus (no CS) | `hal.spi()` | `Spi` | `embedded_hal::spi::SpiBus`, `embedded_hal_async::spi::SpiBus` | Medium |
| 6.3 SPI device (with CS) | `hal.spi_device(cs_pin)` → `Result<SpiDev, SpiHalError>` | `SpiDev` | `embedded_hal::spi::SpiDevice`, `embedded_hal_async::spi::SpiDevice` | Deep |
| 6.4 GPIO output | `hal.gpio(pin)` | `Gpio` | `OutputPin`, `StatefulOutputPin` | Deep |
| 6.5 GPIO input | `hal.gpio(pin)` | `Gpio` | `InputPin` | Deep |
| 6.6 GPIO async wait | `hal.gpio(pin)` | `Gpio` | `embedded_hal_async::digital::Wait` | Deep |
| 6.7 GPIO subscribe | `hal.gpio_subscribe(pin, edge)` + `hal.gpio_unsubscribe(pin)` | (no handle; push-based) | n/a | Deep |
| 6.8 PWM | `hal.pwm_channel(channel)` | `PwmChannel` | `embedded_hal::pwm::SetDutyCycle` | Stub |
| 6.9 ADC | `hal.adc_read(channel)` → `Result<u16, AdcHalError>` | n/a | n/a (no embedded-hal 1.0 ADC trait) | Medium |
| 6.10 1-Wire | `hal.onewire()` | `OneWire` | n/a (no embedded-hal 1-Wire trait) | Medium |
| 6.11 UART | `hal.uart()` | `Uart` | `embedded_io::{Read,Write}`, `embedded_io_async::{Read,Write}` | Stub |
| 6.12 Delay | `hal.delay()` | `Delay` | `embedded_hal::delay::DelayNs`, `embedded_hal_async::delay::DelayNs` | Stub |

Configuration setters/getters the file must also document (in §3
or §6.x as appropriate):

- `Hal::i2c_set_config(I2cFrequency)`, `Hal::i2c_get_config()`,
  `Hal::i2c_scan(include_reserved: bool)`
- `Hal::spi_set_config(freq, phase, polarity)`, `Hal::spi_get_config()`
- `Hal::pwm_set_config(channel, freq_hz, phase_correct)`,
  `Hal::pwm_get_config(channel)`
- `Hal::adc_get_config()`
- `Uart::set_timeout_ms(u32)`
- `Hal::new_with_serial_number(&str)` for multi-board setups

## 12. Per-peripheral subsection template

Every Tier-Deep and Tier-Medium subsection in §6 must use this exact
structure:

```
### <Title>

When to use: <one sentence>.
HAL accessor: `hal.<method>(<args>)` → returns `<Type>`.
Traits implemented: <comma-separated list>, or "n/a" with reason.

#### Snippet — binary form

```rust
// examples/<chip>.rs
// pico-de-gallo decision log:
//   shape:        binary
//   sync/async:   <sync|async> (reason: <reason>)
//   peripherals:  <list>
//   hal version:  <current version>

use pico_de_gallo_hal::Hal;
// ... 5–10 lines of canonical idiomatic use, no error-handling shortcuts ...
```

#### Snippet — HIL-test form

(Omit only for Tier-Medium peripherals that have no meaningful
invariant in isolation, and for all Tier-Stub peripherals.)

```rust
#[cfg(feature = "hil")]
#[test]
fn <chip>_<assertion>() {
    let hal = pico_de_gallo_hal::Hal::new();
    // ... 5–10 lines that assert something the user would actually
    // want to know is true for their hardware ...
}
```

#### Gotchas

- <one bullet per real gotcha, 1–4 bullets per subsection>

#### Config knobs (only if non-trivial)

- `hal.<setter>(...)` — what it changes, when to call it, default value.
```

Tier-Stub subsections (PWM, UART, Delay) use a collapsed form:

```
### <Title>

When to use: <one sentence>.
HAL accessor: `hal.<method>(<args>)` → returns `<Type>`.

```rust
// minimal snippet
```

Gotchas: <inline bullets, no subheading>.

See [`pico-de-gallo-hal` docs.rs](https://docs.rs/pico-de-gallo-hal)
for the full surface.
```

## 13. Drift prevention

### 13.1 AGENTS.md §15.1 mapping row

Add one row to the per-area mapping table in `AGENTS.md` §15.1:

| Code area | Book chapter(s) |
|-----------|-----------------|
| `crates/pico-de-gallo-hal/src/...` — public API | `book/src/crates/hal.md`, `book/src/driver/*`, **`docs/ai-agents/pico-de-gallo-hal-examples.md`** |

This means any PR that changes the HAL public surface must update the
agent guide in the same PR, and reviewers (human + automated) treat
omissions as blockers under the existing parity rule.

### 13.2 Recommended CI check (described, not implemented in this spec)

A cheap regex-based CI check should grep the markdown for every
identifier of the form `hal\.\w+\(` and `Hal::\w+`, then sanity-check
each one against `grep -oE 'pub fn \w+' crates/pico-de-gallo-hal/src/lib.rs`.

Out of scope for this spec. Listed as a recommended follow-up inside
the generated file's own drift-prevention note (its §9) and as a
future issue (see §14 of this spec, item 5).

### 13.3 Header in the file itself

The file's frontmatter (top ~5 lines) names the source of truth and
states the rule:

> **Source of truth:** `crates/pico-de-gallo-hal/src/lib.rs` on `main`.
> If this file contradicts that file, the source wins — file an issue.

## 14. Out of scope

These items came up during design but are deliberately not part of
this spec. They will be filed as separate issues:

1. Add `Hal::system_reset_subscriptions` and `Hal::validate` accessors.
2. Add `AdcChannel` to the HAL's `pub use` re-export block.
3. Fix the stale `Hal::uart_set_config` reference in
   `crates/pico-de-gallo-hal/src/lib.rs:1282`.
4. Fix the `pico-de-gallo-internal` doc comment that incorrectly says
   GPIO pin range is `0..=7`.
5. Implement the §13.2 CI grep check.
6. Build the downstream `generate-pico-de-gallo-example` opencode
   skill that consumes this file.
7. Apply the same agent-guide pattern to `pyco-de-gallo` and the
   `gallo` CLI.

## 15. Acceptance criteria

The implementation phase is complete when all of the following hold:

1. `docs/ai-agents/pico-de-gallo-hal-examples.md` exists, follows the
   structure in §8, honors every authoritative content rule in §10,
   documents only the surface in §11, and uses the template in §12.
2. The file is between 500 and 900 lines, with LF line endings.
3. Every HAL accessor named in the file resolves to a real `pub fn`
   in `crates/pico-de-gallo-hal/src/lib.rs`. The implementer verifies
   this manually before opening the PR by running, from the repo root:
   ```bash
   grep -oE '(hal\.[a-z_]+\()|(Hal::[a-z_]+\b)' \
       docs/ai-agents/pico-de-gallo-hal-examples.md | sort -u
   grep -oE 'pub fn [a-z_]+' \
       crates/pico-de-gallo-hal/src/lib.rs | sort -u
   ```
   and confirming every name in the first list has a backing entry in
   the second (or is a method on `Gpio`, `I2c`, `Spi`, `SpiDev`,
   `Uart`, `PwmChannel`, `Delay`, or `OneWire`, which the §11 surface
   table covers).
4. Every snippet in the file is valid Rust syntax that would
   `cargo check` if dropped into a fresh crate with the correct
   dependencies. Snippets do not need to be standalone-compilable
   inside the markdown (no doctest harness); syntactic validity is
   sufficient.
5. `AGENTS.md` §15.1 includes the new mapping row from §13.1.
6. The file is committed in a single PR with a Conventional Commit of
   the form `docs(repo): add AI-agent guide for pico-de-gallo-hal`
   (scope is `repo` because the file lives outside any one crate).
7. CHANGELOG entries are not required; this is a docs-only change
   with no released-artifact impact.

## 16. Open questions

None. All decisions are locked.

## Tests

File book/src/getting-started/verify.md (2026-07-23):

# Verifying Your Device

Plug the freshly-flashed Pico de Gallo into your host and run:

```console
$ gallo version
Pico de Gallo FW v0.8.0
Schema v0.4.0
HW revision 2
Capabilities: I2C ✓ | SPI ✓ | UART ✓ | GPIO ✓ | PWM ✓ | ADC ✓ | 1-Wire ✓
```

If you see that block, you're done. Success 🎉.

## What Each Field Means

| Field | What it tells you |
|---|---|
| `Pico de Gallo FW v...` | The firmware semver. Lockstepped with the wire crate at release time. |
| `Schema v...` | The wire-protocol schema version. The host crate must understand this. |
| `HW revision` | `1` if you flashed `hw-rev1` firmware, `2` for `hw-rev2`. |
| `Capabilities`  | Which peripherals **this firmware build** exposes. A `✗` means the endpoint returns `Unsupported`. |

> [!IMPORTANT]
>
> The `HW revision` line reflects the **firmware build**, not the
> PCB you have. If you flashed the wrong build, re-enter BOOTSEL
> and flash the right one. See [Assembly &
> Flashing](../hardware/assembly.md).

## Ping

For a quick round-trip sanity check:

```console
$ gallo ping
Ping OK
```

`ping` sends a random `u32` to the firmware and asserts the echo
matches. If you can ping, USB and the wire protocol are fully
functional.

## Listing Multiple Devices

If you have more than one Pico de Gallo connected, `gallo list`
shows them:

```console
$ gallo list
Serial Number         Bus    Address
E6633861A34B8C24      2      14
E6633861A34B9F17      1      8
```

Pick a specific device with `-s` (or `--serial-number`):

```console
$ gallo -s E6633861A34B8C24 version
```

Without `-s`, `gallo` uses the first device it finds — which is
non-deterministic if you have more than one plugged in.

## Schema Mismatch

If the firmware and your host CLI disagree on the wire protocol,
`gallo version` will tell you:

```console
$ gallo version
Error: schema mismatch (firmware v0.5.0, host expects v0.4.x)
```

The fix is to update whichever side is behind. See
[Releases & Compatibility](../internals/releases.md) for the rules
on which versions are compatible.

## Next

You're up and running. Pick an interface to play with — start
with [I²C](../interfaces/i2c.md) or [GPIO](../interfaces/gpio.md),
or skip to [Writing a Device Driver](../driver/index.md) for the
guided tour.

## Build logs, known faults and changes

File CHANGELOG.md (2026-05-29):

# Changelog

All notable changes to this project will be documented in this file.

The format is based on [Keep a Changelog](https://keepachangelog.com/en/1.1.0/),
and this project adheres to [Semantic Versioning](https://semver.org/spec/v2.0.0.html).

## [Unreleased]

### Breaking Changes

- **internal**: New `system/reset-subscriptions` endpoint appended to
  the wire protocol. Schema version bumps via the
  `pico-de-gallo-internal` version bump (`0.5.0` → `0.6.0`); under the
  pre-1.0 schema-versioning rule this is a breaking schema bump, so
  hosts and firmware must be upgraded together. Lockstep version
  bumps: `pico-de-gallo-internal` `0.5.0` → `0.6.0`,
  `pico-de-gallo-lib` `0.5.0` → `0.6.0`, `pico-de-gallo-hal` `0.5.0`
  → `0.6.0`, `pico-de-gallo-ffi` `0.6.0` → `0.7.0`, `gallo` (CLI)
  `0.6.0` → `0.7.0`, `pyco-de-gallo` `0.2.0` → `0.3.0`,
  `pico-de-gallo-firmware` `0.9.0` → `0.10.0`. ([REVIEW-2026-05-29
  P1-3])

### Added

- **internal/firmware**: `system/reset-subscriptions` endpoint
  (request `()`, response `u8` count). Firmware iterates its GPIO
  monitor slots, signals stop on each live one, awaits the `Flex` pin
  back from the monitor task, and returns it to `Context`. Idempotent
  and cheap when no subscriptions are active. The endpoint is the
  recovery path for the leak described in P1-3: GPIO subscriptions
  are server-side state that survives the USB transport, so a host
  process that crashed (or was killed, or dropped its
  `nusb::Interface`) without sending `gpio/unsubscribe` would
  permanently strand the affected pins until a power cycle.
- **lib**: `PicoDeGallo::system_reset_subscriptions()` host method
  returns the number of subscriptions reset. The recommended connect
  sequence is now `new()` → `validate().await?` →
  `system_reset_subscriptions().await?`.
- **ffi**: `gallo_system_reset_subscriptions(const PicoDeGallo *,
  uint8_t *out_reset)`. `out_reset` may be `NULL`. New appended
  `Status` code: `SystemResetSubscriptionsFailed = -69`.
- **pyco**: `PycoDeGallo.system_reset_subscriptions()` returns an
  `int`.
- **ffi**: `gallo_spi_transfer`, `gallo_spi_batch`, and `gallo_i2c_batch`
  expose the high-throughput SPI full-duplex and atomic CS-held batch
  primitives (and the equivalent I<sup>2</sup>C multi-op primitive) to C
  consumers that previously could only call them from Rust. Batch ops
  are passed via C-friendly tagged structs (`GalloSpiBatchOp`,
  `GalloI2cBatchOp`); on per-operation failure, an optional
  `out_failed_op` pointer receives the zero-based index of the failing
  op. Three new appended `Status` codes: `I2cBatchFailed = -66`,
  `SpiBatchFailed = -67`, `SpiTransferFailed = -68`. The wire protocol
  is unchanged — these are pure FFI surface additions over existing
  endpoints. ([REVIEW-2026-05-29 P1-2])
- **lib**: `MAX_BATCH_OPS` and `MAX_TRANSFER_SIZE` are now re-exported
  from `pico-de-gallo-internal` so downstream consumers don't have to
  pull in the wire crate just to validate batch sizes.

### Changed

- **ffi**: All `gallo_*` functions now take `const PicoDeGallo *` for the
  device handle (previously `PicoDeGallo *` on every function except
  `gallo_init*` / `gallo_free`). The C ABI (pointer width, calling
  convention, status codes) is unchanged, but C consumers that typed their
  handle as `PicoDeGallo *` and previously cast away `const` on every call
  can now drop those casts. Header consumers with `-Wcast-qual` enabled
  will stop warning. The opaque handle remains thread-safe (`Send + Sync`)
  and interior-mutable. ([REVIEW-2026-05-29 P1-4])

### Fixed

- **lib**: `PicoDeGallo::validate()` no longer mis-classifies transport,
  postcard-decode, and frame-size errors as `ValidateError::LegacyFirmware`.
  Only `WireError::UnknownKey` and `WireError::KeyTooSmall` (the
  postcard-rpc signals for "this firmware has no handler for that
  endpoint key") map to `LegacyFirmware`; every other host error routes
  to `ValidateError::Comms`, so users see "comms failure" instead of
  being told to upgrade firmware that is already current. Surfaces in
  `gallo_get_device_info` as the correct `Status::CommsFailed` (−1) when
  the wire is the actual problem. ([REVIEW-2026-05-29 P1-1])

## [0.9.0] — 2026-05-04

**Crate versions:** internal 0.5.0, lib 0.5.0, hal 0.5.0, ffi 0.6.0, app 0.6.0, firmware 0.9.0, pyco 0.2.0

### Breaking Changes

- **internal**: `UartGetConfigurationResponse` and `AdcGetConfigurationResponse`
  are now `Result<…>` instead of bare struct values, so endpoints can
  report `Unsupported` on hardware revisions that don't route the peripheral.
  Wire protocol is **not** backward compatible — firmware and host must be
  upgraded together.
- **internal**: New `Unsupported` variant added to `UartError`, `AdcError`, and
  `OneWireError`. Because these enums are not `#[non_exhaustive]`, existing
  exhaustive matches in downstream code must add the new arm.
- **lib**: `uart_get_config()` now returns `PicoDeGalloError<UartError>` and
  `adc_get_config()` now returns `PicoDeGalloError<AdcError>` (was
  `PicoDeGalloError<Infallible>`).

### Added

- **hardware**: v1.1 landing board — single keyed 2×12 (0.1″ pitch)
  shrouded header replacing the seven individual connectors of v1.0.
  Routes all 20 firmware signals (UART, SPI CS, 1-Wire, ADC now
  connected). On-board passives: 4.7 kΩ I²C pull-ups (R1/R2), 100 Ω ADC
  series resistors (R3–R5), 100 nF decoupling capacitor (C1). VREF pin
  hardwired to 3.3 V. Uses `hw-rev2` firmware.

- **internal**: `GetDeviceInfo` endpoint (`"device/info"`), `DeviceInfo` struct,
  `Capabilities` bitflag newtype (`u64`) with named constants (`I2C`, `SPI`,
  `UART`, `GPIO`, `PWM`, `ADC`, `ONEWIRE`). Schema version constants
  auto-generated from `Cargo.toml` via `build.rs`.
- **firmware**: `hw-rev1` and `hw-rev2` Cargo feature flags (mutually exclusive).
  `hw-rev1` is the default and matches the current v1 landing board.
  Unsupported peripherals (UART, ADC, 1-Wire on v1) return `Unsupported`
  errors instead of silently failing.
- **firmware**: `device_info_handler` returning firmware version, schema version,
  hardware revision, and capabilities bitfield. Capabilities are gated by
  hardware revision feature flag.
- **lib**: `device_info()` and `validate()` methods, `ValidateError` enum.
  Re-exported `Capabilities` and `DeviceInfo`.
- **ffi**: `gallo_get_device_info()` function, `GalloDeviceInfo` C struct with
  `capabilities` u64 bitfield, `GALLO_CAP_*` constants. 4 new status codes:
  `DeviceInfoFailed` (−62), `SchemaMismatch` (−63), `LegacyFirmware` (−64),
  `Unsupported` (−65).
- **app**: `gallo version` now shows schema version, HW revision, and
  capabilities with graceful fallback for legacy firmware.
- **book**: Updated FFI docs with device info section, C constants, and
  `Unsupported` status code. Added hardware revision notes to getting-started
  pin map, UART, ADC, and 1-Wire pages.
- **ci**: `nostd.yml` now builds and lints firmware for both `hw-rev1` and
  `hw-rev2`. `release-firmware.yml` produces per-revision release assets
  (`firmware-rev1.uf2`, `firmware-rev2.uf2`).
- **ci**: `pyco-de-gallo` is now part of the `check.yml` matrix
  (fmt, clippy, doc, hack, test, msrv) on equal footing with the
  other host crates.

### Changed

- **ci/firmware**: `release-firmware.yml` now generates the `.uf2`
  with [`elf2uf2-rs`](https://github.com/JoNil/elf2uf2-rs) instead of
  downloading `picotool` from the `pico-sdk-tools` release tarball.
  The tool is installed from git (`cargo install --git ... --locked`)
  because the published crates.io 2.2.0 release does not yet expose
  the `--family` CLI option. The conversion uses `--family rp2350-arm-ns`
  (non-secure Cortex-M33; TrustZone is not enabled). Output artifact
  names (`firmware-{rev1,rev2}.uf2` and
  `pico-de-gallo-firmware-{rev1,rev2}` ELF) are unchanged.
- **firmware/release**: Renamed firmware crate package from
  `pico-de-gallo-fw` to `pico-de-gallo-firmware` (matches the
  directory name). The release ELF asset uploaded by
  `release-firmware.yml` is now
  `pico-de-gallo-firmware-{rev1,rev2}` (was
  `pico-de-gallo-fw-{rev1,rev2}`). The `firmware-{rev1,rev2}.uf2`
  artifact name is unchanged.

### Fixed

- **firmware**: Pin `embassy-usb-driver = "=0.2.0"` to work around an
  upstream incompatibility — `embassy-usb-driver 0.2.1` bumped
  `embedded-io-async` from 0.6 to 0.7, but `embassy-usb 0.5.1`'s
  CDC-ACM `embedded_io_async::ErrorType` impl still expects the 0.6
  trait. The mismatch produces an `EndpointError: embedded_io_async::Error`
  trait-bound error inside `embassy-usb`. We can't move to embassy-usb
  0.6 because `postcard-rpc 0.12` only ships an `embassy-usb-0_5-server`
  feature.

## [0.8.0] — 2026-04-22

**Crate versions:** internal 0.4.0, lib 0.4.0, hal 0.4.0, ffi 0.5.0, app 0.5.0, firmware 0.8.0

### Breaking Changes

- **firmware/internal**: Reduced GPIO count from 8 (GPIO 8–15) to 4
  (GPIO 8–11). GPIO 12–15 are now reserved for PWM output. All GPIO
  indices are now 0–3 instead of 0–7.
- **internal**: Replaced 12 unit-struct error types (`I2cReadFail`, `SpiWriteFail`,
  etc.) with 3 rich error enums: `I2cError` (7 variants), `SpiError` (2 variants),
  `GpioError` (2 variants). Wire protocol is **not** backward compatible —
  firmware and host must be upgraded together.
- **internal**: `GpioError` now has 4 variants — added `PinMonitored` and
  `PinNotMonitored` for the GPIO event subscription system.
- **firmware**: `gpios` field in `Context` changed from `[Flex<'static>; NUM_GPIOS]`
  to `[Option<Flex<'static>>; NUM_GPIOS]`. GPIO operations on a monitored pin
  return `GpioError::PinMonitored`.
- **lib**: All method return types updated from `PicoDeGalloError<*Fail>` to
  `PicoDeGalloError<I2cError>`, `PicoDeGalloError<SpiError>`, or
  `PicoDeGalloError<GpioError>`.
- **hal**: Single `Error` type replaced with `I2cHalError`, `SpiHalError`, and
  `GpioHalError` — each wraps the endpoint-specific error plus a `Comms` variant.
  I2C `ErrorKind` mapping now returns accurate variants (NoAcknowledge,
  ArbitrationLoss, Bus, Overrun) instead of `Other` for all errors.
- **ffi**: Added 8 new status codes (`I2cNack`, `I2cBusError`,
  `I2cArbitrationLoss`, `I2cOverrun`, `BufferTooLong`, `I2cAddressOutOfRange`,
  `GpioInvalidPin`, `CommsFailed`).
- **firmware**: I2C handlers now map embassy-rp `AbortReason` variants to rich
  error types. SPI `set-config` validates frequency before applying (prevents
  panic on zero frequency).
- **hal**: `I2c::transaction()` and `SpiDevice::transaction()` now use batch
  endpoints under the hood — one USB round-trip per transaction instead of
  one per operation. This is a behavioral change: previously each operation
  in a transaction was an independent USB transfer.

### Added

- **internal**: `GpioEventTopic` (device-to-host topic), `GpioEdge` enum
  (Rising/Falling/Any), `GpioEvent` struct (pin, edge, timestamp_us),
  `GpioSubscribe`/`GpioUnsubscribe` endpoints with request/response types.
  `TOPICS_OUT_LIST` now contains the GPIO event topic.
- **firmware**: GPIO event monitoring via 4 pooled `gpio_monitor_task` instances.
  Subscribe takes ownership of the pin, monitors for edges, and publishes
  `GpioEvent` via `Sender::publish`. Unsubscribe returns the pin to the
  context. Static channels for start/stop/return/armed synchronization.
- **lib**: `gpio_subscribe(pin, edge)`, `gpio_unsubscribe(pin)`, and
  `subscribe_gpio_events(depth)` methods. Re-exported `GpioEdge`, `GpioEvent`,
  `IoClosed`, `MultiSubscription`.
- **hal**: `gpio_subscribe(pin, edge)` and `gpio_unsubscribe(pin)` blocking
  methods. Re-exported `GpioEdge`, `GpioEvent`.
- **ffi**: `gallo_gpio_subscribe(pin, edge)` and `gallo_gpio_unsubscribe(pin)`
  FFI functions. 4 new status codes: `GpioPinMonitored` (-54),
  `GpioPinNotMonitored` (-55), `GpioSubscribeFailed` (-56),
  `GpioUnsubscribeFailed` (-57).
- **app**: `gallo gpio monitor --pin N --edge rising|falling|any` command.
  Subscribes, prints edge events with timestamps, unsubscribes on Ctrl+C.
- **internal**: `I2cBatch` and `SpiBatch` endpoints, `I2cBatchOp`/`SpiBatchOp`
  enums, `I2cBatchRequest`/`SpiBatchRequest`/`I2cBatchError`/`SpiBatchError`
  types, `encode_i2c_batch_ops`/`encode_spi_batch_ops` helpers,
  `i2c_batch_response_len`/`spi_batch_response_len`/`count_i2c_batch_ops`/
  `count_spi_batch_ops` parsing helpers. Constants: `MAX_BATCH_OPS`,
  `BATCH_OP_READ`, `BATCH_OP_WRITE`, `BATCH_OP_TRANSFER`, `BATCH_OP_DELAY_NS`.
- **firmware**: `i2c_batch_handler` and `spi_batch_handler` with pre-validation,
  CS assertion/deassertion for SPI batches. SPI batch executes atomically
  under chip-select.
- **lib**: `i2c_batch(address, ops)` and `spi_batch(cs, ops)` async methods.
  Re-exported `I2cBatchOp`, `SpiBatchOp`, `encode_i2c_batch_ops`,
  `encode_spi_batch_ops`, `I2cBatchError`, `SpiBatchError`.
- **hal**: `I2c::transaction()` and `SpiDevice::transaction()` (blocking and
  async) rewritten to use batch endpoints — 10–50× fewer USB round-trips for
  multi-operation transactions.
- **app**: `gallo i2c batch` and `gallo spi batch` CLI commands for executing
  batched operations (e.g., `--op write:0x00,0x10 --op read:16`).
- **internal**: 6 PWM endpoints (`pwm/set-duty-cycle`, `pwm/get-duty-cycle`,
  `pwm/enable`, `pwm/disable`, `pwm/set-config`, `pwm/get-config`), `PwmError`
  enum (4 variants), request/response types, `PwmDutyCycleInfo` and
  `PwmConfigurationInfo` structs, `NUM_PWM_CHANNELS` constant.
- **firmware**: PWM output on GPIO 12–15 (PWM slices 6–7, 4 channels).
  Frequency/phase-correct configuration with automatic top/divider computation.
  Duty-cycle compare values scaled proportionally when frequency changes.
- **lib**: `pwm_set_duty_cycle`, `pwm_get_duty_cycle`, `pwm_enable`,
  `pwm_disable`, `pwm_set_config`, `pwm_get_config` async methods.
  Re-exported `PwmError`, `PwmDutyCycleInfo`, `PwmConfigurationInfo`.
- **hal**: `PwmChannel` wrapper implementing `embedded_hal::pwm::SetDutyCycle`.
  `PwmHalError` type. `Hal::pwm_channel(n)` accessor. `pwm_set_config` and
  `pwm_get_config` convenience methods on `Hal`.
- **ffi**: 6 PWM FFI functions (`gallo_pwm_set_duty_cycle`,
  `gallo_pwm_get_duty_cycle`, `gallo_pwm_enable`, `gallo_pwm_disable`,
  `gallo_pwm_set_config`, `gallo_pwm_get_config`) and 9 status codes (-41 to -49).
- **app**: `gallo pwm` subcommand group with `set-duty`, `get-duty`, `enable`,
  `disable`, `set-config`, and `get-config` commands.
- **internal**: 2 ADC endpoints (`adc/read`,
  `adc/get-config`), `AdcChannel` enum (4 variants: Adc0–Adc3),
  `AdcError` enum (2 variants), `AdcReadRequest` and `AdcConfigurationInfo`
  types. Constants: `NUM_ADC_GPIO_CHANNELS`, `ADC_RESOLUTION_BITS`,
  `ADC_NOMINAL_REFERENCE_MV`.
- **firmware**: ADC support on GPIO 26–29 (4 GPIO channels).
  Uses `Adc::new_blocking` for single-shot reads.
- **lib**: `adc_read(channel)`, `adc_get_config()`
  methods. Re-exported `AdcChannel`, `AdcError`, `AdcConfigurationInfo`.
- **hal**: `AdcHalError` type. `Hal::adc_read(channel)`,
  `adc_get_config()` convenience methods.
- **ffi**: 2 ADC FFI functions (`gallo_adc_read`,
  `gallo_adc_get_config`) and 4 status codes (-50 to -53).
- **app**: `gallo adc` subcommand group with `read` and
  `info` commands.
- **internal**: 6 1-Wire endpoints (`onewire/reset`, `onewire/read`, `onewire/write`,
  `onewire/write-pullup`, `onewire/search`, `onewire/search-next`), `OneWireError`
  enum (4 variants), `OneWireReadRequest`, `OneWireWriteRequest`,
  `OneWireWritePullupRequest` types. Response type aliases with `use-std` feature
  gating for `onewire/read`.
- **firmware**: 1-Wire support via PIO0/SM0 on GPIO 16 using embassy-rp's
  `PioOneWire` driver. 6 async handlers. ROM search state held in Context.
- **lib**: `onewire_reset()`, `onewire_read(len)`, `onewire_write(data)`,
  `onewire_write_pullup(data, duration_ms)`, `onewire_search()`,
  `onewire_search_next()` methods. Re-exported `OneWireError`.
- **hal**: `OneWire` handle struct with blocking wrappers. `OneWireHalError` type.
  `Hal::onewire()` accessor.
- **ffi**: 5 1-Wire FFI functions (`gallo_onewire_reset`, `gallo_onewire_read`,
  `gallo_onewire_write`, `gallo_onewire_write_pullup`, `gallo_onewire_search`)
  and 5 status codes (-57 to -61).
- **app**: `gallo onewire` subcommand group with `reset`, `read`, `write`,
  `write-pullup`, and `search` commands.
- **book**: New "1-Wire Bus" chapter with DS18B20 temperature sensor examples
  (CLI, Rust, C, HAL).
- **internal**: 5 UART endpoints (`uart/read`, `uart/write`, `uart/flush`,
  `uart/set-config`, `uart/get-config`), `UartError` enum (7 variants),
  `UartReadRequest`, `UartWriteRequest`, `UartSetConfigurationRequest`, and
  `UartConfigurationInfo` types. Response type aliases with `use-std` feature
  gating for owned vs borrowed data.
- **firmware**: UART0 support via `BufferedUart` (interrupt-driven, 1024-byte
  TX/RX buffers). 5 UART handlers with timeout support on reads. Baud rate
  validation (must be > 0). Uses GPIO0 (TX) and GPIO1 (RX).
- **lib**: `uart_read(count, timeout_ms)`, `uart_write(contents)`,
  `uart_flush()`, `uart_set_config(baud_rate)`, `uart_get_config()` methods.
  Re-exported `UartError` and `UartConfigurationInfo`.
- **hal**: `Uart` wrapper struct implementing `embedded_io::Read`,
  `embedded_io::Write`, `embedded_io_async::Read`, and
  `embedded_io_async::Write`. `UartHalError` type with `embedded_io::Error`
  impl. `Hal::uart()` accessor with 1000ms default timeout.
- **ffi**: 5 UART FFI functions (`gallo_uart_read`, `gallo_uart_write`,
  `gallo_uart_flush`, `gallo_uart_set_config`, `gallo_uart_get_config`) and
  10 status codes (-31 to -40).
- **app**: `gallo uart` subcommand group with `read`, `write`, `flush`,
  `set-config`, and `get-config` commands.
- **internal**: `I2cScan` endpoint and `I2cScanRequest` type for firmware-side bus
  scanning. Returns a `Vec<u8>` of responding addresses — a single USB
  round-trip replaces 112 individual reads.
- **firmware**: `i2c_scan_handler` — probes addresses by 1-byte read, collects
  responding addresses. Supports `include_reserved` flag.
- **lib**: `PicoDeGallo::i2c_scan(include_reserved)` method returning `Vec<u8>`.
- **hal**: `Hal::i2c_scan(include_reserved)` method returning `Vec<u8>`.
- **ffi**: `gallo_i2c_scan()` function (writes responding addresses to caller
  buffer) and `I2cScanFailed` status code.
- **app**: `gallo i2c scan` now uses the dedicated scan endpoint (single round-trip)
  instead of 112 individual reads.
- **hal**: `SpiDev` type implementing both `embedded_hal::spi::SpiDevice` and
  `embedded_hal_async::spi::SpiDevice`. Manages chip-select (CS) via a GPIO pin,
  asserting CS low before operations and deasserting high afterward with
  automatic flush. Created via `Hal::spi_device(cs_pin)`.
- **internal**: `GpioDirection` and `GpioPull` enums, `GpioSetConfigurationRequest`,
  `GpioSetConfigurationResponse`, and `GpioSetConfiguration` endpoint for runtime
  GPIO pin direction and pull-resistor configuration.
- **internal**: `GpioError::WrongDirection` variant — returned when a get/wait is
  attempted on a pin configured as output, or a put on a pin configured as input.
- **firmware**: `gpio_set_config_handler` and per-pin `PinMode` tracking. Once a
  pin is configured via `gpio/set-config`, it enters explicit mode and
  get/put/wait respect the configured direction (returns `WrongDirection` on
  mismatch). Legacy auto-switching preserved for unconfigured pins.
- **lib**: `PicoDeGallo::gpio_set_config(pin, direction, pull)` method;
  re-exported `GpioDirection` and `GpioPull`.
- **hal**: `Gpio::set_config(pin, direction, pull)` method.
- **ffi**: `gallo_gpio_set_config()` function and `GpioSetConfigFailed` /
  `GpioWrongDirection` status codes.
- **app**: `gallo gpio set-config`, `gallo gpio get`, and `gallo gpio put`
  subcommands for direct GPIO access from the command line.
- **internal**: `I2cGetConfiguration` and `SpiGetConfiguration` endpoints with
  `SpiConfigurationInfo` struct for querying the active bus configuration without
  relying on local state.
- **firmware**: `i2c_get_config_handler` and `spi_get_config_handler` — return
  the currently active configuration. Firmware now tracks config values set by
  `set-config` endpoints.
- **lib**: `PicoDeGallo::i2c_get_config()` and `spi_get_config()` methods;
  re-exported `SpiConfigurationInfo`.
- **hal**: `Hal::i2c_get_config()` and `spi_get_config()` methods.
- **ffi**: `gallo_i2c_get_config()` and `gallo_spi_get_config()` functions,
  `I2cGetConfigFailed` and `SpiGetConfigFailed` status codes.
- **app**: `gallo i2c get-config` and `gallo spi get-config` subcommands.

### Fixed

- **lib**: Corrected `MAX_TRANSFER_SIZE` references in rustdoc for `i2c_read`,
  `i2c_write_read`, and `spi_read` (was 512, actual value is 4096)

## [0.7.0] — 2025-04-20

### Breaking Changes

- **internal 0.3.0**: Split `SetConfigurationRequest` into `I2cSetConfigurationRequest`
  and `SpiSetConfigurationRequest`
- **internal 0.3.0**: Replaced raw `u32` I2C frequency with `I2cFrequency` enum
  (`Standard`, `Fast`, `FastPlus`)
- **lib 0.3.0**: Split `set_config()` into `i2c_set_config()` and `spi_set_config()`
- **lib 0.3.0**: `PicoDeGalloError` is now generic over the endpoint error type
- **hal 0.3.0**: Split `set_config()` into `i2c_set_config()` and `spi_set_config()`
- **ffi 0.4.0**: Split `gallo_set_config()` into `gallo_i2c_set_config()` and
  `gallo_spi_set_config()`
- **app 0.4.0**: CLI `set-config` command replaced by `i2c set-config` and
  `spi set-config` subcommands
- **firmware 0.7.0**: Wire protocol updated — firmware and host must be upgraded together

### Added

- **spi**: Full-duplex transfer endpoint (`spi/transfer`) using DMA
- **lib**: `list_devices()` function for enumerating connected boards
- **app**: `list` command to show connected devices with serial numbers
- **lib**: `Display` and `std::error::Error` implementations for `PicoDeGalloError`
- **internal**: `From<bool>` / `Into<bool>` conversions for `GpioState`
- **internal**: `MAX_TRANSFER_SIZE` constant (4096 bytes) shared across crates
- **ffi**: Compile-time `Send + Sync` assertion for thread safety
- **hal**: Per-call async context detection (reuses existing tokio runtime if available)
- **docs**: Comprehensive rustdoc documentation across all crates
- **docs**: Repository-level Copilot instructions (`.github/copilot-instructions.md`)
- **ci**: Fixed Windows release asset naming (`.dll` extension)

### Changed

- **firmware**: Handler functions modernized with improved ergonomics
- **firmware**: Buffer increased to `MAX_TRANSFER_SIZE` (4096 bytes)
- **firmware**: `PacketBuffers` sized to `MAX_TRANSFER_SIZE + 1024` per direction
- **lib**: `client` field made private (was accidentally public)
- **app**: `I2cFrequency` exposed as `--frequency standard|fast|fast-plus` CLI arg

## [firmware-v0.6.0] — 2025-03-15

### Added

- Updated all Embassy and postcard-rpc dependencies
- Addressed critical safety issues and improved API ergonomics
- Added more tests and extracted `connect()` helper

## [application-v0.2.1] — 2025-03-15

### Fixed

- Bumped library dependency for latest fixes

## [ffi-v0.3.0] — 2025-03-15

### Changed

- Updated dependencies to match library changes

## [hal-v0.2.0] — 2025-03-15

### Changed

- Updated dependencies and API to match library

---

[Unreleased]: https://github.com/OpenDevicePartnership/pico-de-gallo/compare/firmware-v0.9.0...HEAD
[0.9.0]: https://github.com/OpenDevicePartnership/pico-de-gallo/compare/firmware-v0.8.0...firmware-v0.9.0
[0.8.0]: https://github.com/OpenDevicePartnership/pico-de-gallo/compare/firmware-v0.7.0...firmware-v0.8.0
[0.7.0]: https://github.com/OpenDevicePartnership/pico-de-gallo/compare/firmware-v0.6.0...firmware-v0.7.0
[firmware-v0.6.0]: https://github.com/OpenDevicePartnership/pico-de-gallo/releases/tag/firmware-v0.6.0
[application-v0.2.1]: https://github.com/OpenDevicePartnership/pico-de-gallo/releases/tag/application-v0.2.1
[ffi-v0.3.0]: https://github.com/OpenDevicePartnership/pico-de-gallo/releases/tag/ffi-v0.3.0
[hal-v0.2.0]: https://github.com/OpenDevicePartnership/pico-de-gallo/releases/tag/hal-v0.2.0

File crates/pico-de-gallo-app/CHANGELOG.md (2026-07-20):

# Changelog

All notable changes to `gallo` will be documented in this file.

The format is based on [Keep a Changelog](https://keepachangelog.com/en/1.1.0/),
and this project adheres to [Semantic Versioning](https://semver.org/spec/v2.0.0.html).

## [0.7.1] — 2026-07-20

### Fixed

- `gallo` now opens a **single** USB connection per invocation and
  shares it (by reference) across schema validation and the command
  handler. Previously every subcommand except `list`/`version`
  opened one connection to run `validate()`, dropped it, then opened
  a second connection for the operation (`spi write-read` opened a
  third). On Windows, WinUSB grants exclusive access to one session
  per interface, and the first connection's background `nusb` worker
  had not released the handle before the second `claim_interface`,
  so the operation panicked with
  `Failed claiming interface: … Access is denied`. Commands such as
  `gallo i2c scan`, `i2c get-config`, and `adc info` failed
  deterministically on Windows, while `version`/`list` (single/zero
  connections) worked — making it look like a driver or permissions
  problem. Linux and macOS release the interface synchronously on
  drop, so CI never caught it. Regression from the 2026-06-04
  up-front `validate()` change (Category A finding #4). No CLI
  surface changed.

## [0.7.0] — 2026-06-22

### Fixed (2026-06-04 — Category A hotfix host-only PR)

- `gallo` now calls `validate()` at the top of every subcommand
  except `list` and `version`. Previously the CLI connected
  lazily and surfaced schema-version mismatches as confusing
  `CommsFailed` errors on the first RPC; now the mismatch is
  reported up-front with an actionable error message that
  points at `gallo version` for the device-reported schema and
  recommends either re-flashing the firmware or installing a
  matching `gallo` build. Closes Category A finding #4 (reviewer
  R4) at the CLI layer.

  `list` is exempt because it doesn't touch a connected device.
  `version` is exempt because it IS the diagnostic subcommand
  that reports schema skew (it already handles legacy firmware
  via `device_info()` with fallback).

### Changed (2026-06-04 — Category A hotfix host-only PR)

- Bumped `pico-de-gallo-lib` dependency to 0.6.0 (validate() now
  also checks `schema_major`, so any future major-version skew
  surfaces immediately rather than silently mis-decoding wire
  bytes).

### Changed (2026-06-03 — Category A hotfix wire PR)

- Bumped `pico-de-gallo-lib` dependency to 0.6.0. Required for
  lockstep release with the wire-protocol schema bump in
  `pico-de-gallo-internal` 0.6.0 / `pico-de-gallo-firmware` 0.10.0
  (`timeout_ms` field on `GpioWaitRequest`, `GpioError::Timeout`
  variant).
- Existing `gallo` CLI behavior is unchanged in this release: the
  pre-existing `gpio` subcommands (`get`, `put`, `set-config`,
  `monitor`) all keep working. The CLI does not currently expose
  `gpio wait-for-*` subcommands, so no new flags are added here.
  Bounded waits remain accessible to Rust / C / Python consumers
  via `pico-de-gallo-lib`, `pico-de-gallo-hal`, and `pico-de-gallo-ffi`.

## [0.6.0] — 2026-05-04

### Added

- `gallo version` now shows schema version, HW revision, and
  capabilities with graceful fallback for legacy firmware.

## [0.5.0] — 2026-04-22

### Added

- `gallo gpio monitor --pin N --edge rising|falling|any` command.
  Subscribes, prints edge events with timestamps, unsubscribes on
  Ctrl+C.
- `gallo i2c batch` and `gallo spi batch` CLI commands for
  executing batched operations (e.g.,
  `--op write:0x00,0x10 --op read:16`).
- `gallo pwm` subcommand group with `set-duty`, `get-duty`,
  `enable`, `disable`, `set-config`, and `get-config` commands.
- `gallo adc` subcommand group with `read` and `info` commands.
- `gallo onewire` subcommand group with `reset`, `read`, `write`,
  `write-pullup`, and `search` commands.
- `gallo uart` subcommand group with `read`, `write`, `flush`,
  `set-config`, and `get-config` commands.
- `gallo i2c scan` now uses the dedicated scan endpoint (single
  round-trip) instead of 112 individual reads.
- `gallo gpio set-config`, `gallo gpio get`, and `gallo gpio put`
  subcommands for direct GPIO access from the command line.
- `gallo i2c get-config` and `gallo spi get-config` subcommands.

## [0.4.0] — 2025-04-20

### Breaking Changes

- CLI `set-config` command replaced by `i2c set-config` and
  `spi set-config` subcommands.

### Added

- `list` command to show connected devices with serial numbers.

### Changed

- `I2cFrequency` exposed as `--frequency standard|fast|fast-plus`
  CLI arg.

## [0.2.1] — 2025-03-15

### Fixed

- Bumped library dependency for latest fixes.

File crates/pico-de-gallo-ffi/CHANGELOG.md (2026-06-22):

# Changelog

All notable changes to `pico-de-gallo-ffi` will be documented in this file.

The format is based on [Keep a Changelog](https://keepachangelog.com/en/1.1.0/),
and this project adheres to [Semantic Versioning](https://semver.org/spec/v2.0.0.html).

## [0.7.0] — 2026-06-22

### Added (2026-06-04 — Category A hotfix host-only PR)

- `gallo_init_strict()` and `gallo_init_strict_with_serial_number(c_serial_number)`.
  Both call `PicoDeGallo::validate()` internally before returning
  the opaque pointer. Return `NULL` on device-not-found, schema
  version mismatch, legacy firmware, or any validation error.
  Prefer in production C code over the lazy `gallo_init` —
  failures (device not present, schema mismatch) surface at
  construct time rather than on the first RPC. Closes Category A
  finding #4 at the FFI layer.

### Changed (2026-06-04 — Category A hotfix host-only PR)

- Bumped `pico-de-gallo-lib` dependency to 0.6.0 (validate() now
  also checks `schema_major`, so the new `gallo_init_strict`
  surfaces major-version skew that the previous validation
  silently accepted).

### Added (2026-06-03 — Category A hotfix wire PR)

- `gallo_gpio_wait_for_{high,low,rising_edge,falling_edge,any_edge}_with_timeout_ms`
  C functions. `timeout_ms == 0` preserves wait-forever behavior;
  non-zero bounds the firmware-side wait and returns
  `Status::GpioTimeout` on expiry. Available on firmware schema
  0.6+; older firmware returns `Status::SchemaMismatch`.
- `Status::GpioTimeout = -70` enum variant (appended at end of
  `Status` enum; preserves stable C ABI per AGENTS.md §8).

### Changed (2026-06-03 — Category A hotfix wire PR)

- Bumped `pico-de-gallo-lib` dependency to 0.6.0 for the
  `gpio_wait_for_*_with_timeout` host methods.

### Added

- `gallo_system_reset_subscriptions(const PicoDeGallo *, uint8_t
  *out_reset)`. `out_reset` may be `NULL`. New appended `Status`
  code: `SystemResetSubscriptionsFailed = -69`.
- `gallo_spi_transfer`, `gallo_spi_batch`, and `gallo_i2c_batch`
  expose the high-throughput SPI full-duplex and atomic CS-held
  batch primitives (and the equivalent I<sup>2</sup>C multi-op
  primitive) to C consumers that previously could only call them
  from Rust. Batch ops are passed via C-friendly tagged structs
  (`GalloSpiBatchOp`, `GalloI2cBatchOp`); on per-operation failure,
  an optional `out_failed_op` pointer receives the zero-based index
  of the failing op. Three new appended `Status` codes:
  `I2cBatchFailed = -66`, `SpiBatchFailed = -67`,
  `SpiTransferFailed = -68`. The wire protocol is unchanged — these
  are pure FFI surface additions over existing endpoints.
  ([REVIEW-2026-05-29 P1-2])

### Changed

- All `gallo_*` functions now take `const PicoDeGallo *` for the
  device handle (previously `PicoDeGallo *` on every function
  except `gallo_init*` / `gallo_free`). The C ABI (pointer width,
  calling convention, status codes) is unchanged, but C consumers
  that typed their handle as `PicoDeGallo *` and previously cast
  away `const` on every call can now drop those casts. Header
  consumers with `-Wcast-qual` enabled will stop warning. The
  opaque handle remains thread-safe (`Send + Sync`) and
  interior-mutable. ([REVIEW-2026-05-29 P1-4])

## [0.6.0] — 2026-05-04

### Added

- `gallo_get_device_info()` function, `GalloDeviceInfo` C struct
  with `capabilities` u64 bitfield, `GALLO_CAP_*` constants. 4 new
  status codes: `DeviceInfoFailed` (−62), `SchemaMismatch` (−63),
  `LegacyFirmware` (−64), `Unsupported` (−65).

## [0.5.0] — 2026-04-22

### Breaking Changes

- Added 8 new status codes (`I2cNack`, `I2cBusError`,
  `I2cArbitrationLoss`, `I2cOverrun`, `BufferTooLong`,
  `I2cAddressOutOfRange`, `GpioInvalidPin`, `CommsFailed`).

### Added

- `gallo_gpio_subscribe(pin, edge)` and `gallo_gpio_unsubscribe(pin)`
  FFI functions. 4 new status codes: `GpioPinMonitored` (-54),
  `GpioPinNotMonitored` (-55), `GpioSubscribeFailed` (-56),
  `GpioUnsubscribeFailed` (-57).
- 6 PWM FFI functions (`gallo_pwm_set_duty_cycle`,
  `gallo_pwm_get_duty_cycle`, `gallo_pwm_enable`,
  `gallo_pwm_disable`, `gallo_pwm_set_config`,
  `gallo_pwm_get_config`) and 9 status codes (-41 to -49).
- 2 ADC FFI functions (`gallo_adc_read`, `gallo_adc_get_config`)
  and 4 status codes (-50 to -53).
- 5 1-Wire FFI functions (`gallo_onewire_reset`,
  `gallo_onewire_read`, `gallo_onewire_write`,
  `gallo_onewire_write_pullup`, `gallo_onewire_search`) and 5
  status codes (-57 to -61).
- 5 UART FFI functions (`gallo_uart_read`, `gallo_uart_write`,
  `gallo_uart_flush`, `gallo_uart_set_config`,
  `gallo_uart_get_config`) and 10 status codes (-31 to -40).
- `gallo_i2c_scan()` function (writes responding addresses to
  caller buffer) and `I2cScanFailed` status code.
- `gallo_gpio_set_config()` function and `GpioSetConfigFailed` /
  `GpioWrongDirection` status codes.
- `gallo_i2c_get_config()` and `gallo_spi_get_config()` functions,
  `I2cGetConfigFailed` and `SpiGetConfigFailed` status codes.

## [0.4.0] — 2025-04-20

### Breaking Changes

- Split `gallo_set_config()` into `gallo_i2c_set_config()` and
  `gallo_spi_set_config()`.

### Added

- Compile-time `Send + Sync` assertion for thread safety.

## [0.3.0] — 2025-03-15

### Changed

- Updated dependencies to match library changes.

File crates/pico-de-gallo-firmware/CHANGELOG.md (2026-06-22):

# Changelog

All notable changes to `pico-de-gallo-firmware` will be documented in this file.

The format is based on [Keep a Changelog](https://keepachangelog.com/en/1.1.0/),
and this project adheres to [Semantic Versioning](https://semver.org/spec/v2.0.0.html).

## [0.10.0] — 2026-06-22

### Added (2026-06-03 — Category A hotfix)

- `gpio_wait_for_*` handlers now honor the per-request `timeout_ms`
  field added in `pico-de-gallo-internal` 0.6. A value of `0`
  preserves the pre-0.6 wait-forever behavior. Non-zero wraps the
  embassy `wait_for_*_edge()` future in
  `embassy_time::with_timeout(Duration::from_millis(timeout_ms))`
  and returns `GpioError::Timeout` on expiry.
- Embassy-rp watchdog enabled at 2-second timeout, fed every
  800 ms by a dedicated `watchdog_feeder_task`. `pause_on_debug(true)`
  is set so debugger sessions don't reset the chip. Recovers the
  device from any future handler hang regression (1-Wire PIO
  stalls, embassy-rp peripheral bugs, etc.). The feeder is a
  separate embassy task — RPC handlers cannot be trusted to feed
  because a wedged handler would also wedge any handler-based
  feed scheme (see closed dispatcher-wedge regression below).

### Fixed (2026-06-03 — Category A hotfix)

- `i2c_scan_handler` now wraps each per-address probe in
  `with_timeout(Duration::from_millis(50))`. A single stuck
  address (slave NAKs slowly, electrical issue, etc.) no longer
  burns the entire scan budget. The watchdog feeder task runs
  independently so the device stays alive even during long scans.

### Why

- Closes the dispatcher-wedge regression where a `gpio_wait_for_*`
  on a never-transitioning pin blocked **every other endpoint**
  until power-cycle (reliability finding B1, captured in
  `docs/superpowers/specs/2026-06-03-pico-de-gallo-category-a-review-synthesis.md`).
- Closes the no-recovery-from-handler-hang gap (reliability
  finding R5).
- Reduces worst-case impact of a flaky I²C bus on `i2c_scan`
  (reliability finding B2 / #33).

### Lockstep

- Coupled to `pico-de-gallo-internal` 0.6.0 (schema minor bump
  adding `timeout_ms` to `GpioWaitRequest` and `GpioError::Timeout`
  variant). See AGENTS.md §6.5.

### Added (system/reset-subscriptions)

- `system/reset-subscriptions` endpoint handler. Firmware iterates
  its GPIO monitor slots, signals stop on each live one, awaits the
  `Flex` pin back from the monitor task, and returns it to
  `Context`. Idempotent and cheap when no subscriptions are active.
  The endpoint is the recovery path for the leak described in P1-3:
  a host process that crashed without sending `gpio/unsubscribe`
  would previously strand the affected pins until a power cycle.

## [0.9.0] — 2026-05-04

### Added

- `hw-rev1` and `hw-rev2` Cargo feature flags (mutually exclusive).
  `hw-rev1` is the default and matches the current v1 landing
  board. Unsupported peripherals (UART, ADC, 1-Wire on v1) return
  `Unsupported` errors instead of silently failing.
- `device_info_handler` returning firmware version, schema version,
  hardware revision, and capabilities bitfield. Capabilities are
  gated by hardware revision feature flag.
- Hardware v1.1 landing board — single keyed 2×12 (0.1″ pitch)
  shrouded header replacing the seven individual connectors of
  v1.0. Routes all 20 firmware signals (UART, SPI CS, 1-Wire, ADC
  now connected). On-board passives: 4.7 kΩ I²C pull-ups (R1/R2),
  100 Ω ADC series resistors (R3–R5), 100 nF decoupling capacitor
  (C1). VREF pin hardwired to 3.3 V. Uses `hw-rev2` firmware.

### Changed

- `release-firmware.yml` now generates the `.uf2` with
  [`elf2uf2-rs`](https://github.com/JoNil/elf2uf2-rs) instead of
  downloading `picotool` from the `pico-sdk-tools` release tarball.
  The tool is installed from git (`cargo install --git ...
  --locked`) because the published crates.io 2.2.0 release does not
  yet expose the `--family` CLI option. The conversion uses
  `--family rp2350-arm-ns` (non-secure Cortex-M33; TrustZone is not
  enabled). Output artifact names (`firmware-{rev1,rev2}.uf2` and
  `pico-de-gallo-firmware-{rev1,rev2}` ELF) are unchanged.
- Renamed firmware crate package from `pico-de-gallo-fw` to
  `pico-de-gallo-firmware` (matches the directory name). The
  release ELF asset uploaded by `release-firmware.yml` is now
  `pico-de-gallo-firmware-{rev1,rev2}` (was
  `pico-de-gallo-fw-{rev1,rev2}`). The `firmware-{rev1,rev2}.uf2`
  artifact name is unchanged.
- CI: `nostd.yml` now builds and lints firmware for both `hw-rev1`
  and `hw-rev2`. `release-firmware.yml` produces per-revision
  release assets (`firmware-rev1.uf2`, `firmware-rev2.uf2`).

### Fixed

- Pin `embassy-usb-driver = "=0.2.0"` to work around an upstream
  incompatibility — `embassy-usb-driver 0.2.1` bumped
  `embedded-io-async` from 0.6 to 0.7, but `embassy-usb 0.5.1`'s
  CDC-ACM `embedded_io_async::ErrorType` impl still expects the 0.6
  trait. The mismatch produces an `EndpointError:
  embedded_io_async::Error` trait-bound error inside `embassy-usb`.
  We can't move to embassy-usb 0.6 because `postcard-rpc 0.12` only
  ships an `embassy-usb-0_5-server` feature.

## [0.8.0] — 2026-04-22

### Breaking Changes

- Reduced GPIO count from 8 (GPIO 8–15) to 4 (GPIO 8–11). GPIO
  12–15 are now reserved for PWM output. All GPIO indices are now
  0–3 instead of 0–7. (Joint firmware/internal change.)
- `gpios` field in `Context` changed from `[Flex<'static>;
  NUM_GPIOS]` to `[Option<Flex<'static>>; NUM_GPIOS]`. GPIO
  operations on a monitored pin return `GpioError::PinMonitored`.
- I2C handlers now map embassy-rp `AbortReason` variants to rich
  error types. SPI `set-config` validates frequency before applying
  (prevents panic on zero frequency).

### Added

- GPIO event monitoring via 4 pooled `gpio_monitor_task` instances.
  Subscribe takes ownership of the pin, monitors for edges, and
  publishes `GpioEvent` via `Sender::publish`. Unsubscribe returns
  the pin to the context. Static channels for
  start/stop/return/armed synchronization.
- `i2c_batch_handler` and `spi_batch_handler` with pre-validation,
  CS assertion/deassertion for SPI batches. SPI batch executes
  atomically under chip-select.
- PWM output on GPIO 12–15 (PWM slices 6–7, 4 channels).
  Frequency/phase-correct configuration with automatic
  top/divider computation. Duty-cycle compare values scaled
  proportionally when frequency changes.
- ADC support on GPIO 26–29 (4 GPIO channels). Uses
  `Adc::new_blocking` for single-shot reads.
- 1-Wire support via PIO0/SM0 on GPIO 16 using embassy-rp's
  `PioOneWire` driver. 6 async handlers. ROM search state held in
  Context.
- UART0 support via `BufferedUart` (interrupt-driven, 1024-byte
  TX/RX buffers). 5 UART handlers with timeout support on reads.
  Baud rate validation (must be > 0). Uses GPIO0 (TX) and GPIO1
  (RX).
- `i2c_scan_handler` — probes addresses by 1-byte read, collects
  responding addresses. Supports `include_reserved` flag.
- `gpio_set_config_handler` and per-pin `PinMode` tracking. Once a
  pin is configured via `gpio/set-config`, it enters explicit mode
  and get/put/wait respect the configured direction (returns
  `WrongDirection` on mismatch). Legacy auto-switching preserved
  for unconfigured pins.
- `i2c_get_config_handler` and `spi_get_config_handler` — return
  the currently active configuration. Firmware now tracks config
  values set by `set-config` endpoints.

## [0.7.0] — 2025-04-20

### Breaking Changes

- Wire protocol updated — firmware and host must be upgraded
  together.

### Changed

- Handler functions modernized with improved ergonomics.
- Buffer increased to `MAX_TRANSFER_SIZE` (4096 bytes).
- `PacketBuffers` sized to `MAX_TRANSFER_SIZE + 1024` per
  direction.

## [0.6.0] — 2025-03-15

### Added

- Updated all Embassy and postcard-rpc dependencies.
- Addressed critical safety issues and improved API ergonomics.
- Added more tests and extracted `connect()` helper.

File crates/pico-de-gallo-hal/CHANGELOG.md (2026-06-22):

# Changelog

All notable changes to `pico-de-gallo-hal` will be documented in this file.

The format is based on [Keep a Changelog](https://keepachangelog.com/en/1.1.0/),
and this project adheres to [Semantic Versioning](https://semver.org/spec/v2.0.0.html).

## [0.6.0] — 2026-06-22

### Added (2026-06-04 — Category A hotfix host-only PR)

- `Hal::new_validated()` and
  `Hal::new_validated_with_serial_number(serial)` constructors call
  `validate()` before returning, failing loudly on
  device-not-connected or schema-version mismatch. The existing
  lazy `Hal::new()` / `Hal::new_with_serial_number()` continue to
  defer failures until the first RPC.
- `Hal::validate()` accessor for callers that constructed via the
  lazy constructors and want to validate after the fact.
- `Hal::system_reset_subscriptions() -> Result<u8, SystemHalError>`
  exposes the firmware-side subscription teardown previously only
  reachable via `pico-de-gallo-lib`. Recommended after
  `new_validated()` in any application that uses GPIO subscriptions,
  so a prior host's crashed-mid-subscription state is cleared.
- `HalInitError` (wraps `pico_de_gallo_lib::ValidateError`) and
  `SystemHalError` (just `Comms` today).
- Re-exported `AdcChannel`, `AdcConfigurationInfo`, `GpioDirection`,
  `GpioEdge`, `GpioPull` from `pico-de-gallo-lib`. Driver authors
  no longer need to add `pico-de-gallo-lib` to their `Cargo.toml`
  for these types.

### Fixed (2026-06-04 — Category A hotfix host-only PR)

- Removed the stale doc-comment reference to a non-existent
  `Hal::uart_set_config` method on the `Uart` struct. Documentation
  now correctly notes that UART baud is fixed at the firmware
  default and changes require dropping to `pico-de-gallo-lib`.

### Changed (2026-06-04 — Category A hotfix host-only PR)

- Bumped `pico-de-gallo-lib` dependency to 0.6.0 (validate() now
  also checks `schema_major`).
- Updated `docs/ai-agents/pico-de-gallo-hal-examples.md`:
  - §4 Cargo setup: removed the "not re-exported by the HAL"
    bullet for `AdcChannel` et al. (they are re-exported now).
  - §6.4–§6.7 GPIO snippets: switched `use pico_de_gallo_lib::{...}`
    to `use pico_de_gallo_hal::{...}` for `GpioDirection`,
    `GpioPull`, `GpioEdge`.
  - §6.7 GPIO subscribe gotcha: documents
    `hal.system_reset_subscriptions()` as the recovery path.
  - §6.9 ADC snippet/HIL/gotchas: switched `AdcChannel` import
    to the HAL re-export; historical note preserved.

### Added (2026-06-03 — Category A hotfix wire PR)

- `Gpio::wait_for_{high,low,rising_edge,falling_edge,any_edge}_with_timeout`
  async methods accept a `std::time::Duration` and return
  `Err(GpioHalError::Gpio(GpioError::Timeout))` on expiry.
  `embedded-hal-async`'s `Wait` trait does not support timeouts, so
  these are exposed as inherent methods on `Gpio` instead. Recommended
  for production code; the trait methods retain their wait-forever
  semantics for compatibility with existing drivers.

### Changed (2026-06-03 — Category A hotfix wire PR)

- Bumped `pico-de-gallo-lib` dependency to 0.6.0.
- Updated `docs/ai-agents/pico-de-gallo-hal-examples.md` §6.6 Gotchas
  to recommend the bounded `_with_timeout` variants for production
  use.

## [0.4.0] — 2026-04-22

### Breaking Changes

- Single `Error` type replaced with `I2cHalError`, `SpiHalError`,
  and `GpioHalError` — each wraps the endpoint-specific error plus
  a `Comms` variant. I2C `ErrorKind` mapping now returns accurate
  variants (NoAcknowledge, ArbitrationLoss, Bus, Overrun) instead
  of `Other` for all errors.
- `I2c::transaction()` and `SpiDevice::transaction()` now use batch
  endpoints under the hood — one USB round-trip per transaction
  instead of one per operation. This is a behavioral change:
  previously each operation in a transaction was an independent USB
  transfer.

### Added

- `gpio_subscribe(pin, edge)` and `gpio_unsubscribe(pin)` blocking
  methods. Re-exported `GpioEdge`, `GpioEvent`.
- `I2c::transaction()` and `SpiDevice::transaction()` (blocking and
  async) rewritten to use batch endpoints — 10–50× fewer USB
  round-trips for multi-operation transactions.
- `PwmChannel` wrapper implementing
  `embedded_hal::pwm::SetDutyCycle`. `PwmHalError` type.
  `Hal::pwm_channel(n)` accessor. `pwm_set_config` and
  `pwm_get_config` convenience methods on `Hal`.
- `AdcHalError` type. `Hal::adc_read(channel)`, `adc_get_config()`
  convenience methods.
- `OneWire` handle struct with blocking wrappers. `OneWireHalError`
  type. `Hal::onewire()` accessor.
- `Uart` wrapper struct implementing `embedded_io::Read`,
  `embedded_io::Write`, `embedded_io_async::Read`, and
  `embedded_io_async::Write`. `UartHalError` type with
  `embedded_io::Error` impl. `Hal::uart()` accessor with 1000ms
  default timeout.
- `Hal::i2c_scan(include_reserved)` method returning `Vec<u8>`.
- `SpiDev` type implementing both `embedded_hal::spi::SpiDevice`
  and `embedded_hal_async::spi::SpiDevice`. Manages chip-select
  (CS) via a GPIO pin, asserting CS low before operations and
  deasserting high afterward with automatic flush. Created via
  `Hal::spi_device(cs_pin)`.
- `Gpio::set_config(pin, direction, pull)` method.
- `Hal::i2c_get_config()` and `spi_get_config()` methods.

## [0.3.0] — 2025-04-20

### Breaking Changes

- Split `set_config()` into `i2c_set_config()` and
  `spi_set_config()`.

### Added

- Per-call async context detection (reuses existing tokio runtime
  if available).

## [0.2.0] — 2025-03-15

### Changed

- Updated dependencies and API to match library.

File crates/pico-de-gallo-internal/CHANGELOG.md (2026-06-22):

# Changelog

All notable changes to `pico-de-gallo-internal` will be documented in this file.

The format is based on [Keep a Changelog](https://keepachangelog.com/en/1.1.0/),
and this project adheres to [Semantic Versioning](https://semver.org/spec/v2.0.0.html).

## [0.6.0] — 2026-06-22

### Breaking Changes (2026-06-03 — Category A hotfix)

- `GpioWaitRequest` gained a `timeout_ms: u32` field, used by all
  five `gpio/wait-*` endpoints (`gpio/wait-high`, `wait-low`,
  `wait-rising`, `wait-falling`, `wait-any`). A value of `0`
  preserves pre-0.6 wait-forever behavior; non-zero bounds the
  firmware-side wait and returns `GpioError::Timeout` on expiry.
- `GpioError::Timeout` variant appended at end of enum (safe wire-
  protocol addition per AGENTS.md §6.1).
- Schema version bumps via the `pico-de-gallo-internal` version
  bump (`0.5.0` → `0.6.0`); under the pre-1.0 schema-versioning
  rule this is a breaking schema bump, so hosts and firmware must
  be upgraded together. This work ships in the same `0.6.0`
  release as the `system/reset-subscriptions` change below.
  Lockstep version bumps: `pico-de-gallo-internal` `0.5.0` →
  `0.6.0`, `pico-de-gallo-lib` `0.5.0` → `0.6.0`,
  `pico-de-gallo-hal` `0.5.0` → `0.6.0`, `pico-de-gallo-ffi`
  `0.6.0` → `0.7.0`, `gallo` (CLI) `0.6.0` → `0.7.0`,
  `pyco-de-gallo` `0.2.0` → `0.4.2`, `pico-de-gallo-firmware`
  `0.9.0` → `0.10.0`. Closes Category A finding #2 (reliability
  subagent B1: GPIO `wait_for_*` on a never-transitioning pin
  previously wedged the entire firmware dispatcher).

### Breaking Changes

- New `system/reset-subscriptions` endpoint appended to the wire
  protocol. Schema version bumps via the `pico-de-gallo-internal`
  version bump (`0.5.0` → `0.6.0`); under the pre-1.0
  schema-versioning rule this is a breaking schema bump, so hosts
  and firmware must be upgraded together. Lockstep version bumps:
  `pico-de-gallo-internal` `0.5.0` → `0.6.0`, `pico-de-gallo-lib`
  `0.5.0` → `0.6.0`, `pico-de-gallo-hal` `0.5.0` → `0.6.0`,
  `pico-de-gallo-ffi` `0.6.0` → `0.7.0`, `gallo` (CLI) `0.6.0` →
  `0.7.0`, `pyco-de-gallo` `0.2.0` → `0.4.2`,
  `pico-de-gallo-firmware` `0.9.0` → `0.10.0`. ([REVIEW-2026-05-29
  P1-3])

### Added

- `system/reset-subscriptions` endpoint (request `()`, response `u8`
  count). The endpoint is the recovery path for the leak described
  in P1-3: GPIO subscriptions are server-side state that survives
  the USB transport, so a host process that crashed (or was killed,
  or dropped its `nusb::Interface`) without sending
  `gpio/unsubscribe` would permanently strand the affected pins
  until a power cycle.

## [0.5.0] — 2026-05-04

### Breaking Changes

- `UartGetConfigurationResponse` and `AdcGetConfigurationResponse`
  are now `Result<…>` instead of bare struct values, so endpoints
  can report `Unsupported` on hardware revisions that don't route
  the peripheral. Wire protocol is **not** backward compatible —
  firmware and host must be upgraded together.
- New `Unsupported` variant added to `UartError`, `AdcError`, and
  `OneWireError`. Because these enums are not `#[non_exhaustive]`,
  existing exhaustive matches in downstream code must add the new
  arm.

### Added

- `GetDeviceInfo` endpoint (`"device/info"`), `DeviceInfo` struct,
  `Capabilities` bitflag newtype (`u64`) with named constants
  (`I2C`, `SPI`, `UART`, `GPIO`, `PWM`, `ADC`, `ONEWIRE`). Schema
  version constants auto-generated from `Cargo.toml` via `build.rs`.

## [0.4.0] — 2026-04-22

### Breaking Changes

- Reduced GPIO count from 8 (GPIO 8–15) to 4 (GPIO 8–11). GPIO
  12–15 are now reserved for PWM output. All GPIO indices are now
  0–3 instead of 0–7. (Joint firmware/internal change.)
- Replaced 12 unit-struct error types (`I2cReadFail`,
  `SpiWriteFail`, etc.) with 3 rich error enums: `I2cError` (7
  variants), `SpiError` (2 variants), `GpioError` (2 variants).
  Wire protocol is **not** backward compatible — firmware and host
  must be upgraded together.
- `GpioError` now has 4 variants — added `PinMonitored` and
  `PinNotMonitored` for the GPIO event subscription system.

### Added

- `GpioEventTopic` (device-to-host topic), `GpioEdge` enum
  (Rising/Falling/Any), `GpioEvent` struct (pin, edge,
  timestamp_us), `GpioSubscribe`/`GpioUnsubscribe` endpoints with
  request/response types. `TOPICS_OUT_LIST` now contains the GPIO
  event topic.
- `I2cBatch` and `SpiBatch` endpoints, `I2cBatchOp`/`SpiBatchOp`
  enums, `I2cBatchRequest`/`SpiBatchRequest`/`I2cBatchError`/
  `SpiBatchError` types, `encode_i2c_batch_ops`/
  `encode_spi_batch_ops` helpers, `i2c_batch_response_len`/
  `spi_batch_response_len`/`count_i2c_batch_ops`/
  `count_spi_batch_ops` parsing helpers. Constants:
  `MAX_BATCH_OPS`, `BATCH_OP_READ`, `BATCH_OP_WRITE`,
  `BATCH_OP_TRANSFER`, `BATCH_OP_DELAY_NS`.
- 6 PWM endpoints (`pwm/set-duty-cycle`, `pwm/get-duty-cycle`,
  `pwm/enable`, `pwm/disable`, `pwm/set-config`, `pwm/get-config`),
  `PwmError` enum (4 variants), request/response types,
  `PwmDutyCycleInfo` and `PwmConfigurationInfo` structs,
  `NUM_PWM_CHANNELS` constant.
- 2 ADC endpoints (`adc/read`, `adc/get-config`), `AdcChannel` enum
  (4 variants: Adc0–Adc3), `AdcError` enum (2 variants),
  `AdcReadRequest` and `AdcConfigurationInfo` types. Constants:
  `NUM_ADC_GPIO_CHANNELS`, `ADC_RESOLUTION_BITS`,
  `ADC_NOMINAL_REFERENCE_MV`.
- 6 1-Wire endpoints (`onewire/reset`, `onewire/read`,
  `onewire/write`, `onewire/write-pullup`, `onewire/search`,
  `onewire/search-next`), `OneWireError` enum (4 variants),
  `OneWireReadRequest`, `OneWireWriteRequest`,
  `OneWireWritePullupRequest` types. Response type aliases with
  `use-std` feature gating for `onewire/read`.
- 5 UART endpoints (`uart/read`, `uart/write`, `uart/flush`,
  `uart/set-config`, `uart/get-config`), `UartError` enum (7
  variants), `UartReadRequest`, `UartWriteRequest`,
  `UartSetConfigurationRequest`, and `UartConfigurationInfo` types.
  Response type aliases with `use-std` feature gating for owned vs
  borrowed data.
- `I2cScan` endpoint and `I2cScanRequest` type for firmware-side
  bus scanning. Returns a `Vec<u8>` of responding addresses — a
  single USB round-trip replaces 112 individual reads.
- `GpioDirection` and `GpioPull` enums,
  `GpioSetConfigurationRequest`, `GpioSetConfigurationResponse`,
  and `GpioSetConfiguration` endpoint for runtime GPIO pin
  direction and pull-resistor configuration.
- `GpioError::WrongDirection` variant — returned when a get/wait is
  attempted on a pin configured as output, or a put on a pin
  configured as input.
- `I2cGetConfiguration` and `SpiGetConfiguration` endpoints with
  `SpiConfigurationInfo` struct for querying the active bus
  configuration without relying on local state.

## [0.3.0] — 2025-04-20

### Breaking Changes

- Split `SetConfigurationRequest` into `I2cSetConfigurationRequest`
  and `SpiSetConfigurationRequest`.
- Replaced raw `u32` I2C frequency with `I2cFrequency` enum
  (`Standard`, `Fast`, `FastPlus`).

### Added

- SPI full-duplex transfer endpoint (`spi/transfer`) using DMA.
- `From<bool>` / `Into<bool>` conversions for `GpioState`.
- `MAX_TRANSFER_SIZE` constant (4096 bytes) shared across crates.

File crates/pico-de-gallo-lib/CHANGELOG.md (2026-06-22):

# Changelog

All notable changes to `pico-de-gallo-lib` will be documented in this file.

The format is based on [Keep a Changelog](https://keepachangelog.com/en/1.1.0/),
and this project adheres to [Semantic Versioning](https://semver.org/spec/v2.0.0.html).

## [0.6.0] — 2026-06-22

### Fixed (2026-06-04 — Category A hotfix host-only PR)

- `PicoDeGallo::validate()` now checks `schema_major` in addition
  to `schema_minor`. Previously, a firmware reporting a bumped
  major version with a matching minor would silently pass
  validation and the host would subsequently mis-decode wire
  bytes (silent garbage out). The schema-check policy is now
  extracted into a private `check_schema_compatible(&DeviceInfo)`
  helper with four regression tests covering matching versions
  and the three rejection cases (bumped major, bumped minor,
  both bumped).
- `ValidateError::SchemaMismatch` payload extended with
  `expected_major` and `actual_major` fields; `Display` impl
  shows the full `MAJOR.MINOR.x` skew rather than just the minor
  versions.

  This is a structural change to a public enum variant payload.
  Direct constructors and exhaustive matches against
  `SchemaMismatch` will need to add the two new fields. The
  variant is not on the wire (`ValidateError` is a host-side
  type), so there is no schema impact.

### Added (2026-06-03 — Category A hotfix wire PR)

- `PicoDeGallo::gpio_wait_for_{high,low,rising_edge,falling_edge,any_edge}_with_timeout`
  methods take a `std::time::Duration` and return
  `Err(PicoDeGalloError::Endpoint(GpioError::Timeout))` on expiry.
  The existing two-arg methods (`gpio_wait_for_high(pin)` etc.)
  preserve the wait-forever behavior by passing `timeout_ms: 0`
  on the wire. Closes Category A finding #2 at the host-library
  layer.

### Changed (2026-06-03 — Category A hotfix wire PR)

- Bumped `pico-de-gallo-internal` dependency to 0.6.0 (wire schema
  change: append-only `timeout_ms: u32` on `GpioWaitRequest`,
  append-only `GpioError::Timeout` variant). Lockstep with firmware
  0.10.0 per AGENTS.md §6.5.

### Added

- `PicoDeGallo::system_reset_subscriptions()` host method returns
  the number of subscriptions reset. The recommended connect
  sequence is now `new()` → `validate().await?` →
  `system_reset_subscriptions().await?`.
- `MAX_BATCH_OPS` and `MAX_TRANSFER_SIZE` are now re-exported from
  `pico-de-gallo-internal` so downstream consumers don't have to
  pull in the wire crate just to validate batch sizes.

### Fixed

- `PicoDeGallo::validate()` no longer mis-classifies transport,
  postcard-decode, and frame-size errors as
  `ValidateError::LegacyFirmware`. Only `WireError::UnknownKey` and
  `WireError::KeyTooSmall` (the postcard-rpc signals for "this
  firmware has no handler for that endpoint key") map to
  `LegacyFirmware`; every other host error routes to
  `ValidateError::Comms`, so users see "comms failure" instead of
  being told to upgrade firmware that is already current. Surfaces
  in `gallo_get_device_info` as the correct `Status::CommsFailed`
  (−1) when the wire is the actual problem. ([REVIEW-2026-05-29
  P1-1])

## [0.5.0] — 2026-05-04

### Breaking Changes

- `uart_get_config()` now returns `PicoDeGalloError<UartError>` and
  `adc_get_config()` now returns `PicoDeGalloError<AdcError>` (was
  `PicoDeGalloError<Infallible>`).

### Added

- `device_info()` and `validate()` methods, `ValidateError` enum.
  Re-exported `Capabilities` and `DeviceInfo`.

## [0.4.0] — 2026-04-22

### Breaking Changes

- All method return types updated from `PicoDeGalloError<*Fail>` to
  `PicoDeGalloError<I2cError>`, `PicoDeGalloError<SpiError>`, or
  `PicoDeGalloError<GpioError>`.

### Added

- `gpio_subscribe(pin, edge)`, `gpio_unsubscribe(pin)`, and
  `subscribe_gpio_events(depth)` methods. Re-exported `GpioEdge`,
  `GpioEvent`, `IoClosed`, `MultiSubscription`.
- `i2c_batch(address, ops)` and `spi_batch(cs, ops)` async methods.
  Re-exported `I2cBatchOp`, `SpiBatchOp`, `encode_i2c_batch_ops`,
  `encode_spi_batch_ops`, `I2cBatchError`, `SpiBatchError`.
- `pwm_set_duty_cycle`, `pwm_get_duty_cycle`, `pwm_enable`,
  `pwm_disable`, `pwm_set_config`, `pwm_get_config` async methods.
  Re-exported `PwmError`, `PwmDutyCycleInfo`,
  `PwmConfigurationInfo`.
- `adc_read(channel)`, `adc_get_config()` methods. Re-exported
  `AdcChannel`, `AdcError`, `AdcConfigurationInfo`.
- `onewire_reset()`, `onewire_read(len)`, `onewire_write(data)`,
  `onewire_write_pullup(data, duration_ms)`, `onewire_search()`,
  `onewire_search_next()` methods. Re-exported `OneWireError`.
- `uart_read(count, timeout_ms)`, `uart_write(contents)`,
  `uart_flush()`, `uart_set_config(baud_rate)`,
  `uart_get_config()` methods. Re-exported `UartError` and
  `UartConfigurationInfo`.
- `PicoDeGallo::i2c_scan(include_reserved)` method returning
  `Vec<u8>`.
- `PicoDeGallo::gpio_set_config(pin, direction, pull)` method;
  re-exported `GpioDirection` and `GpioPull`.
- `PicoDeGallo::i2c_get_config()` and `spi_get_config()` methods;
  re-exported `SpiConfigurationInfo`.

### Fixed

- Corrected `MAX_TRANSFER_SIZE` references in rustdoc for
  `i2c_read`, `i2c_write_read`, and `spi_read` (was 512, actual
  value is 4096).

## [0.3.0] — 2025-04-20

### Breaking Changes

- Split `set_config()` into `i2c_set_config()` and
  `spi_set_config()`.
- `PicoDeGalloError` is now generic over the endpoint error type.

### Added

- `list_devices()` function for enumerating connected boards.
- `Display` and `std::error::Error` implementations for
  `PicoDeGalloError`.

### Changed

- `client` field made private (was accidentally public).

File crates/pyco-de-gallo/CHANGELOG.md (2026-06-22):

# Changelog

All notable changes to `pyco-de-gallo` will be documented in this file.

The format is based on [Keep a Changelog](https://keepachangelog.com/en/1.1.0/),
and this project adheres to [Semantic Versioning](https://semver.org/spec/v2.0.0.html).

## [0.4.2] — 2026-06-22

### Added (2026-06-04 — Category A hotfix host-only PR)

- `pyco_de_gallo.open_strict()` and
  `pyco_de_gallo.open_strict_with_serial_number(serial_number)`.
  Both call `PicoDeGallo::validate()` internally before returning
  the `PycoDeGallo` handle. Raise `RuntimeError` on device-not-found,
  schema version mismatch, legacy firmware, or any validation error.
  Prefer in production Python code over the lazy `open()` /
  `open_with_serial_number()` — failures surface at construct time
  rather than on the first RPC. Closes Category A finding #4 at
  the Python layer.

### Changed (2026-06-04 — Category A hotfix host-only PR)

- Bumped `pico-de-gallo-lib` dependency to 0.6.0 (validate() now
  also checks `schema_major`).
- Updated `book/src/crates/python.md` to document the two new
  entry points.

### Added (2026-06-03 — Category A hotfix wire PR)

- `PycoDeGallo.gpio_wait_for_{high,low,rising_edge,falling_edge,any_edge}_with_timeout`
  Python methods accept a `timeout_ms: int`. 0 waits forever
  (matches the existing methods); non-zero bounds the wait and
  raises `RuntimeError` on `GpioError::Timeout`. Available on
  firmware schema 0.6+.

### Changed (2026-06-03 — Category A hotfix wire PR)

- Bumped `pico-de-gallo-lib` dependency to 0.6.0. Lockstep release
  with `pico-de-gallo-internal` 0.6.0 / `pico-de-gallo-firmware`
  0.10.0 per AGENTS.md §6.5.

### Added

- `PycoDeGallo.system_reset_subscriptions()` returns an `int`.

## [0.2.0] — 2026-05-04

### Added

- `pyco-de-gallo` is now part of the `check.yml` CI matrix (fmt,
  clippy, doc, hack, test, msrv) on equal footing with the other
  host crates.

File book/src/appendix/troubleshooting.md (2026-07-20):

# Troubleshooting

## Device Doesn''t Show Up

### `gallo list` finds nothing

1. Confirm the LED on the Pico 2 is lit. If not, check the USB
   cable — many USB-C cables are power-only.
2. Confirm the firmware is flashed. Hold **BOOTSEL** while
   plugging in. If the board mounts as a `RPI-RP2` mass-storage
   device, the firmware **is not** running — see
   [Assembly & Flashing](../hardware/assembly.md).
3. **Linux**: install the udev rule from
   [USB & OS Notes](../getting-started/usb.md). Without it,
   `nusb` can''t claim the interface as a regular user.
4. **Windows**: install the WinUSB driver via Zadig. The default
   Windows USB driver does not expose vendor-specific endpoints
   to user space.
5. Check `dmesg` (Linux), Device Manager (Windows), or
   `system_profiler SPUSBDataType` (macOS) for VID `045E` and
   PID `067D`.

### `gallo ping` fails with a comms error

A successful `gallo list` followed by a failing `gallo ping`
usually means another process has the device open — typically a
previous `gallo` instance that didn''t exit cleanly, or a Python
script holding a `PycoDeGallo`. Close it.

### `SchemaMismatch` (status code −63)

The host library was built against a different
`SCHEMA_VERSION_MINOR` than the running firmware. Re-flash the
matching firmware release, or upgrade/downgrade the host crates
to match. See [Releases & Compatibility](../internals/releases.md).

### `LegacyFirmware` (status code −64)

The firmware is too old to answer `device/info`. Re-flash a
recent firmware build.

## Peripheral Errors

### `Unsupported` (status code −65)

The peripheral exists in the protocol but isn''t wired on this
hardware revision. Check the capability bitfield from
`gallo info`. See [Revisions](../hardware/revisions.md).

### I²C `Nack` (−18)

The target didn''t acknowledge. Common causes:

- Wrong address. `gallo i2c scan` confirms which addresses ACK.
- Missing pull-ups. v1.1 boards have on-board 4.7 kΩ pull-ups;
  v1.0 does not.
- Target powered off, or VCC level mismatch (Pico de Gallo runs
  at 3.3 V on the bus pads).

### I²C `BusError` (−19) / `ArbitrationLoss` (−20)

Usually a wiring issue (long stub leads, no pull-ups, multi-master
collisions). Try a slower clock with `gallo i2c set-config --frequency standard`.

### `BufferTooLong` (−22)

The firmware caps a single transfer at 4096 bytes. Split larger
transfers, or use batch operations to keep them in one USB
round-trip even when broken into smaller chunks.

### GPIO `WrongDirection` (−28)

You read from a pin configured as output (or vice versa). Call
`gpio_set_config` first with the matching direction.

## Firmware Build Issues

### `embassy-usb-driver 0.2.1` breaks the build

A known regression. Pin `embassy-usb-driver = "=0.2.0"` in the
firmware `Cargo.toml`. See `AGENTS.md` §13.10 for the full story.

### `elf2uf2-rs 2.2.0` from crates.io is stale

The CI installs it from git because the crates.io version is
missing the `--family` flag. Use `picotool` or install from git.

## Driver Development

### "It worked over USB but not on the real MCU"

A few things to check:

- **Timing.** USB introduces ~1 ms round-trip latency. If your
  driver relies on tight inter-byte timing (some 1-Wire and
  WS2812-style protocols), the on-host loop will look fine while
  the on-target loop fails.
- **Clock speed.** Pico de Gallo''s I²C / SPI clocks are
  configurable but discrete. Confirm the target MCU''s HAL can
  produce the same speed.
- **Pull-ups and levels.** Voltage-level mismatches show up as
  intermittent NACKs.

### `transaction()` is slower than expected

If you call `embedded_hal::i2c::I2c::write_read()` or
`SpiDevice::transaction()` and it issues multiple USB round-trips,
the HAL didn''t catch the batchable case. File an issue with the
Operations list — coverage for newer trait shapes is an active
work area.

## Where to Get Help

- File issues at
  [github.com/OpenDevicePartnership/pico-de-gallo](https://github.com/OpenDevicePartnership/pico-de-gallo/issues).
- Discussions:
  [github.com/OpenDevicePartnership/pico-de-gallo/discussions](https://github.com/OpenDevicePartnership/pico-de-gallo/discussions).
- The `AGENTS.md` file at the repo root has §13 "Common Gotchas"
  written from real regressions — worth a read before opening an
  issue.

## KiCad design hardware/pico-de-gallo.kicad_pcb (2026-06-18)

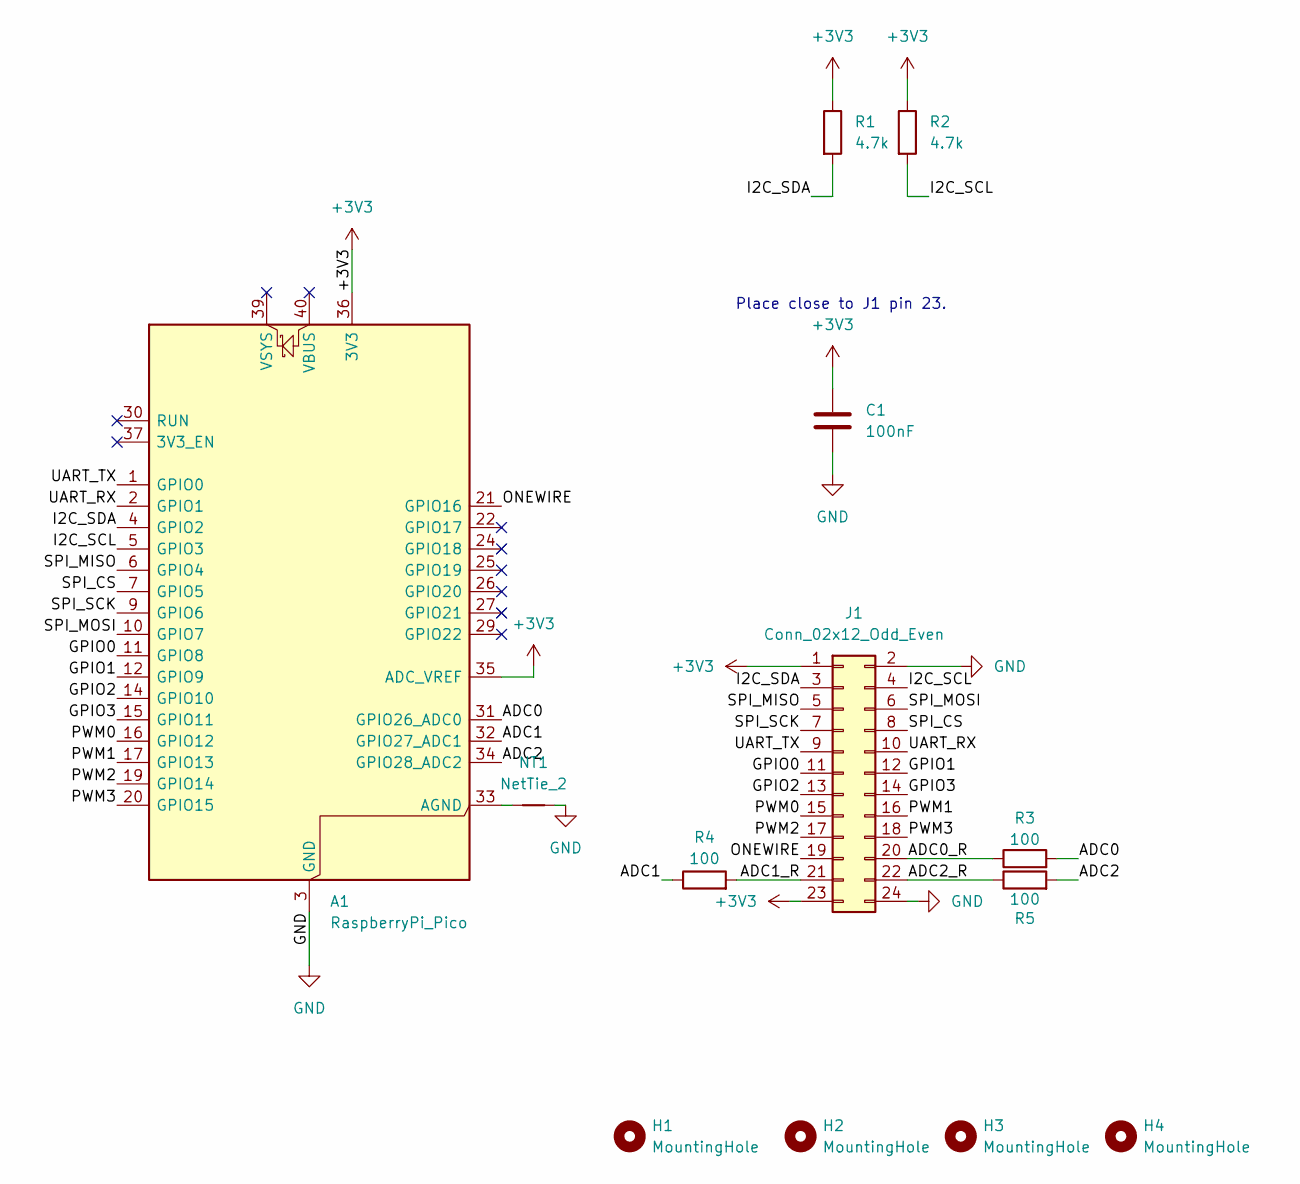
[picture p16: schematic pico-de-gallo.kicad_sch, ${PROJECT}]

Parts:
A1: RaspberryPi_Pico; RaspberryPi_Pico_Common_Unspecified; LCSC C41407547
C1: 100nF; C_0603_1608Metric_Pad1.08x0.95mm_HandSolder; LCSC C14663
H1, H2, H3, H4: MountingHole; MountingHole_3.2mm_M3
J1: Conn_02x12_Odd_Even; IDC-Header_2x12_P2.54mm_Vertical; LCSC C9137
NT1: NetTie_2; NetTie-2_SMD_Pad0.5mm
R1, R2: 4.7k; R_0603_1608Metric_Pad0.98x0.95mm_HandSolder; LCSC C23162
R3, R4, R5: 100; R_0603_1608Metric_Pad0.98x0.95mm_HandSolder; LCSC C22775

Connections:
+3V3: A1.35 (ADC_VREF), A1.36 (3V3), C1.1, J1.1, J1.23, R1.1, R2.1
/ADC0: A1.31 (GPIO26_ADC0), R3.2
/ADC0_R: J1.20, R3.1
/ADC1: A1.32 (GPIO27_ADC1), R4.1
/ADC1_R: J1.21, R4.2
/ADC2: A1.34 (GPIO28_ADC2), R5.2
/ADC2_R: J1.22, R5.1
/GPIO0: A1.11 (GPIO8), J1.11
/GPIO1: A1.12 (GPIO9), J1.12
/GPIO2: A1.14 (GPIO10), J1.13
/GPIO3: A1.15 (GPIO11), J1.14
/I2C_SCL: A1.5 (GPIO3), J1.4, R2.2
/I2C_SDA: A1.4 (GPIO2), J1.3, R1.2
/ONEWIRE: A1.21 (GPIO16), J1.19
/PWM0: A1.16 (GPIO12), J1.15
/PWM1: A1.17 (GPIO13), J1.16
/PWM2: A1.19 (GPIO14), J1.17
/PWM3: A1.20 (GPIO15), J1.18
/SPI_CS: A1.7 (GPIO5), J1.8
/SPI_MISO: A1.6 (GPIO4), J1.5
/SPI_MOSI: A1.10 (GPIO7), J1.6
/SPI_SCK: A1.9 (GPIO6), J1.7
/UART_RX: A1.2 (GPIO1), J1.10
/UART_TX: A1.1 (GPIO0), J1.9
GND: A1.3 (GND), A1.8 (GND), A1.13 (GND), A1.18 (GND), A1.23 (GND), A1.28 (GND), A1.38 (GND), C1.2, J1.2, J1.24, NT1.2
unnamed: A1.33 (AGND), NT1.1

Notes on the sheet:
Place close to J1 pin 23.

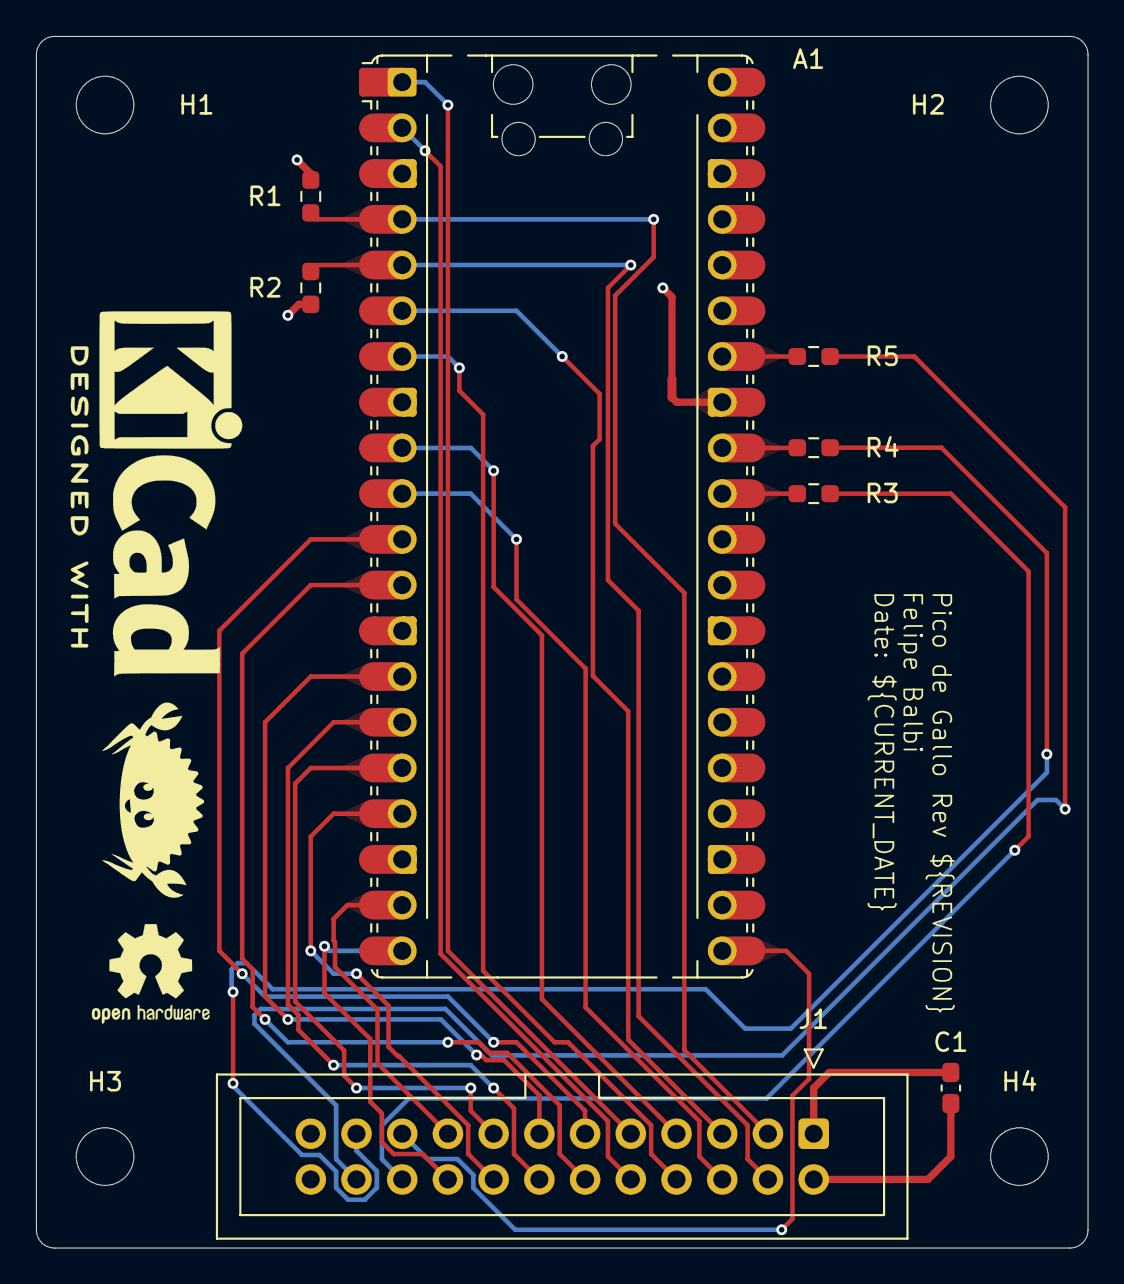
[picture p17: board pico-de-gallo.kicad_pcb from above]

Board: 4 copper layers, 58.4 x 67.3 mm, 13 parts (0 on the bottom side), 26 nets.

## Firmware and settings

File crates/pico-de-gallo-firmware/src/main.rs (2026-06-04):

#![no_std]
#![no_main]
//! Pico de Gallo firmware for the Raspberry Pi Pico 2 (RP2350).
//!
//! This firmware implements a USB bridge that exposes I2C, SPI, UART, GPIO,
//! PWM, ADC, and 1-Wire peripherals to a host computer via [postcard-rpc](https://docs.rs/postcard-rpc)
//! endpoints. It runs on the [Embassy](https://embassy.dev) async runtime.
//!
//! # Peripheral Mapping
//!
//! | Function | RP2350 Pins | Notes |
//! |----------|-------------|-------|
//! | UART0 TX | GPIO 0 | Buffered, interrupt-driven |
//! | UART0 RX | GPIO 1 | |
//! | I2C1 SDA | GPIO 2 | 7-bit addressing, async mode |
//! | I2C1 SCL | GPIO 3 | |
//! | SPI0 SCK | GPIO 6 | DMA-backed full-duplex |
//! | SPI0 TX  | GPIO 7 | |
//! | SPI0 RX  | GPIO 4 | |
//! | GPIO 0–3 | GPIO 8–11 | Input/output/edge-wait |
//! | PWM 0    | GPIO 12 | Slice 6 channel A |
//! | PWM 1    | GPIO 13 | Slice 6 channel B |
//! | PWM 2    | GPIO 14 | Slice 7 channel A |
//! | PWM 3    | GPIO 15 | Slice 7 channel B |
//! | 1-Wire   | GPIO 16 | PIO0/SM0, open-drain |
//! | ADC 0    | GPIO 26 | 12-bit, 0–3.3 V nominal |
//! | ADC 1    | GPIO 27 | 12-bit, 0–3.3 V nominal |
//! | ADC 2    | GPIO 28 | 12-bit, 0–3.3 V nominal |
//! | ADC 3    | GPIO 29 | 12-bit, 0–3.3 V nominal |
//! | USB      | Native USB | postcard-rpc transport |
//!
//! # Endpoints
//!
//! See [`pico_de_gallo_internal::ENDPOINT_LIST`] for the full list of
//! supported endpoints and their request/response types.
//!
//! # Buffer Size
//!
//! The firmware uses a shared buffer of [`MAX_TRANSFER_SIZE`](pico_de_gallo_internal::MAX_TRANSFER_SIZE)
//! (4096) bytes for I2C and SPI data. Requests exceeding this limit are
//! rejected with an error.

#[cfg(all(feature = "hw-rev1", feature = "hw-rev2"))]
compile_error!("Features `hw-rev1` and `hw-rev2` are mutually exclusive");
#[cfg(not(any(feature = "hw-rev1", feature = "hw-rev2")))]
compile_error!("One of `hw-rev1` or `hw-rev2` must be enabled");

mod context;
mod handlers;

use core::sync::atomic::{AtomicU16, Ordering};
use defmt::{debug, warn};
use embassy_executor::Spawner;
#[cfg(feature = "hw-rev2")]
use embassy_rp::adc::{self, Adc};
use embassy_rp::clocks::ClockConfig;
#[cfg(feature = "hw-rev2")]
use embassy_rp::gpio::Pull;
use embassy_rp::gpio::{Flex, Level};
#[cfg(feature = "hw-rev2")]
use embassy_rp::peripherals::PIO0;
#[cfg(feature = "hw-rev2")]
use embassy_rp::pio;
#[cfg(feature = "hw-rev2")]
use embassy_rp::pio_programs::onewire::{PioOneWire, PioOneWireProgram};
use embassy_rp::pwm::{self, Pwm};
#[cfg(feature = "hw-rev2")]
use embassy_rp::uart::{self, BufferedUart};
use embassy_rp::usb::Driver;
use embassy_rp::watchdog::Watchdog;
use embassy_sync::blocking_mutex::raw::CriticalSectionRawMutex;
use embassy_sync::blocking_mutex::raw::ThreadModeRawMutex;
use embassy_sync::channel::Channel;
use embassy_sync::signal::Signal;
use embassy_time::{Duration, Instant, Timer};
use embassy_usb::{Config, UsbDevice};
use pico_de_gallo_internal::{
    AdcGetConfiguration, AdcRead, ENDPOINT_LIST, GetDeviceInfo, GpioEdge, GpioEvent, GpioEventTopic, GpioGet, GpioPut,
    GpioSetConfiguration, GpioState, GpioSubscribe, GpioUnsubscribe, GpioWaitForAny, GpioWaitForFalling,
    GpioWaitForHigh, GpioWaitForLow, GpioWaitForRising, I2cBatch, I2cGetConfiguration, I2cRead, I2cScan,
    I2cSetConfiguration, I2cWrite, I2cWriteRead, MAX_TRANSFER_SIZE, MICROSOFT_VID, OneWireRead, OneWireReset,
    OneWireSearch, OneWireSearchNext, OneWireWrite, OneWireWritePullup, PICO_DE_GALLO_PID, PingEndpoint, PwmDisable,
    PwmEnable, PwmGetConfiguration, PwmGetDutyCycle, PwmSetConfiguration, PwmSetDutyCycle, SpiBatch, SpiFlush,
    SpiGetConfiguration, SpiRead, SpiSetConfiguration, SpiTransfer, SpiWrite, SystemResetSubscriptions, TOPICS_IN_LIST,
    TOPICS_OUT_LIST, UartFlush, UartGetConfiguration, UartRead, UartSetConfiguration, UartWrite, Version,
};
use postcard_rpc::{
    define_dispatch,
    header::VarKeyKind,
    server::{
        Dispatch, Sender, Server,
        impls::embassy_usb_v0_5::{
            PacketBuffers,
            dispatch_impl::{WireRxBuf, WireRxImpl, WireSpawnImpl, WireStorage, WireTxImpl},
        },
    },
};
use static_cell::ConstStaticCell;
use static_cell::StaticCell;
use {defmt_rtt as _, panic_probe as _};

use context::*;

use handlers::*;

/// Binary info entries for `picotool info` identification.
///
/// These entries are placed in the `.bi_entries` linker section and allow
/// `picotool` to display the firmware name, description, version, and
/// build info without running the firmware.
#[unsafe(link_section = ".bi_entries")]
#[used]
pub static PICOTOOL_ENTRIES: [embassy_rp::binary_info::EntryAddr; 4] = [
    embassy_rp::binary_info::rp_program_name!(c"Pico de Gallo"),
    embassy_rp::binary_info::rp_program_description!(c"USB bridge to various buses such as I2C, SPI, UART, and ADC"),
    embassy_rp::binary_info::rp_cargo_version!(),
    embassy_rp::binary_info::rp_program_build_attribute!(),
];

// auto-generated version information from Cargo.toml
include!(concat!(env!("OUT_DIR"), "/version.rs"));

/// Hardware revision. Bump when the physical board layout changes.
#[cfg(feature = "hw-rev1")]
pub(crate) const HW_VERSION: u8 = 1;
#[cfg(feature = "hw-rev2")]
pub(crate) const HW_VERSION: u8 = 2;

/// USB driver type for the RP2350.
type AppDriver = Driver<'static, embassy_rp::peripherals::USB>;
/// postcard-rpc wire storage with ThreadMode mutex.
type AppStorage = WireStorage<ThreadModeRawMutex, AppDriver, 256, 256, 64, 256>;
/// Packet buffer storage sized for [`MAX_TRANSFER_SIZE`] plus protocol overhead.
type BufStorage = PacketBuffers<{ MAX_TRANSFER_SIZE + 1024 }, { MAX_TRANSFER_SIZE + 1024 }>;
/// postcard-rpc transmit implementation.
type AppTx = WireTxImpl<ThreadModeRawMutex, AppDriver>;
/// postcard-rpc receive implementation.
type AppRx = WireRxImpl<AppDriver>;
/// The complete postcard-rpc server type.
type AppServer = Server<AppTx, AppRx, WireRxBuf, PicoDeGallo>;

static PBUFS: ConstStaticCell<BufStorage> = ConstStaticCell::new(BufStorage::new());
static STORAGE: AppStorage = AppStorage::new();

// --- GPIO event monitoring infrastructure ---

/// Channel for sending a (Flex, GpioEdge) pair to start monitoring pin `n`.
static GPIO_MONITOR_START: [Channel<CriticalSectionRawMutex, (Flex<'static>, GpioEdge), 1>; NUM_GPIOS] =
    [Channel::new(), Channel::new(), Channel::new(), Channel::new()];

/// Signal to stop monitoring pin `n`.
static GPIO_MONITOR_STOP: [Signal<CriticalSectionRawMutex, ()>; NUM_GPIOS] =
    [Signal::new(), Signal::new(), Signal::new(), Signal::new()];

/// Channel for returning the Flex pin after monitoring stops.
static GPIO_MONITOR_RETURN: [Channel<CriticalSectionRawMutex, Flex<'static>, 1>; NUM_GPIOS] =
    [Channel::new(), Channel::new(), Channel::new(), Channel::new()];

/// Ack channel: monitor task signals it is armed and listening.
static GPIO_MONITOR_ARMED: [Channel<CriticalSectionRawMutex, (), 1>; NUM_GPIOS] =
    [Channel::new(), Channel::new(), Channel::new(), Channel::new()];

/// Monotonic sequence counter for published GPIO events.
static GPIO_EVENT_SEQ: AtomicU16 = AtomicU16::new(0);

/// Background task that monitors GPIO pin `N` for edge events.
///
/// The task waits for a `(Flex, GpioEdge)` on `GPIO_MONITOR_START[N]`,
/// sends an armed ack, then loops detecting edges and publishing
/// `GpioEvent` topics until `GPIO_MONITOR_STOP[N]` is signalled.
/// After stopping, the `Flex` pin is returned via `GPIO_MONITOR_RETURN[N]`.
///
/// Edge detection is best-effort: if the pin changes faster than the
/// monitor loop cadence, intermediate transitions may be missed.
#[embassy_executor::task(pool_size = 4)]
async fn gpio_monitor_task(slot: usize, tx: AppTx, vkk: VarKeyKind) {
    let sender = Sender::new(tx, vkk);

    loop {
        // Wait for a subscribe request to hand us a pin
        let (mut flex, edge) = GPIO_MONITOR_START[slot].receive().await;

        // Configure as input for edge detection
        flex.set_as_input();

        // Signal that we are armed and listening
        GPIO_MONITOR_ARMED[slot].send(()).await;

        debug!("gpio monitor[{}]: armed, edge={=u8}", slot, edge as u8);

        // Monitor loop: wait for edge or stop signal
        loop {
            use embassy_futures::select::{Either, select};

            let edge_future = async {
                match edge {
                    GpioEdge::Rising => flex.wait_for_rising_edge().await,
                    GpioEdge::Falling => flex.wait_for_falling_edge().await,
                    GpioEdge::Any => flex.wait_for_any_edge().await,
                }
            };

            match select(edge_future, GPIO_MONITOR_STOP[slot].wait()).await {
                Either::First(()) => {
                    let state = match flex.get_level() {
                        Level::Low => GpioState::Low,
                        Level::High => GpioState::High,
                    };
                    let timestamp_us = Instant::now().as_micros();
                    let seq = GPIO_EVENT_SEQ.fetch_add(1, Ordering::Relaxed);

                    let event = GpioEvent {
                        pin: slot as u8,
                        edge,
                        state,
                        timestamp_us,
                    };

                    debug!(
                        "gpio monitor[{}]: edge detected, state={=u8}, ts={=u64}",
                        slot, state as u8, timestamp_us
                    );

                    let _ = sender.publish::<GpioEventTopic>(seq.into(), &event).await;
                }
                Either::Second(()) => {
                    debug!("gpio monitor[{}]: stop requested", slot);
                    GPIO_MONITOR_RETURN[slot].send(flex).await;
                    break;
                }
            }
        }
    }
}

/// Build the USB device configuration.
///
/// Reads the chip unique ID from OTP to generate a deterministic serial
/// number string. Falls back to all-zeros if OTP read fails.
fn usb_config() -> Config<'static> {
    // Obtain the chip unique ID for USB serial number.
    // Falls back to "UNKNOWN" if OTP read fails (e.g. on some dev boards).
    let unique_id: u64 = embassy_rp::otp::get_chipid().unwrap_or_else(|e| {
        warn!("Failed to read chip ID: {:?}, using fallback serial", e);
        0
    });

    static SERIAL_STRING: StaticCell<[u8; 16]> = StaticCell::new();
    let mut ser_buf = [b'0'; 16];
    unique_id
        .to_be_bytes()
        .iter()
        .zip(ser_buf.chunks_exact_mut(2))
        .for_each(|(b, chs)| {
            let mut b = *b;
            for c in chs {
                *c = match b >> 4 {
                    v @ 0..10 => b'0' + v,
                    v @ 10..16 => b'A' + (v - 10),
                    _ => b'X',
                };
                b <<= 4;
            }
        });
    let ser_buf = SERIAL_STRING.init(ser_buf);
    // Safety: ser_buf contains only ASCII hex digits, which are valid UTF-8.
    let ser_buf = core::str::from_utf8(ser_buf.as_slice()).unwrap();

    let mut config = Config::new(MICROSOFT_VID, PICO_DE_GALLO_PID);
    config.manufacturer = Some("Microsoft");
    config.product = Some("Pico de Gallo");
    config.serial_number = Some(ser_buf);
    config.max_power = 100;
    config.max_packet_size_0 = 64;
    config.self_powered = false;
    config.composite_with_iads = false;
    config.device_class = 0xff;
    config.device_sub_class = 0xff;
    config.device_protocol = 0xff;

    config
}

define_dispatch! {
    app: PicoDeGallo;
    spawn_fn: spawn_fn;
    tx_impl: AppTx;
    spawn_impl: WireSpawnImpl;
    context: Context;

    endpoints: {
        list: ENDPOINT_LIST;

        | EndpointTy           | kind     | handler                       |
        | ----------           | ----     | -------                       |
        | PingEndpoint         | blocking | ping_handler                  |
        | I2cRead              | async    | i2c_read_handler              |
        | I2cWrite             | async    | i2c_write_handler             |
        | I2cWriteRead         | async    | i2c_write_read_handler        |
        | SpiRead              | async    | spi_read_handler              |
        | SpiWrite             | async    | spi_write_handler             |
        | SpiFlush             | async    | spi_flush_handler             |
        | SpiTransfer          | async    | spi_transfer_handler          |
        | GpioGet              | async    | gpio_get_handler              |
        | GpioPut              | async    | gpio_put_handler              |
        | GpioWaitForHigh      | async    | gpio_wait_for_high_handler    |
        | GpioWaitForLow       | async    | gpio_wait_for_low_handler     |
        | GpioWaitForRising    | async    | gpio_wait_for_rising_handler  |
        | GpioWaitForFalling   | async    | gpio_wait_for_falling_handler |
        | GpioWaitForAny       | async    | gpio_wait_for_any_handler     |
        | GpioSetConfiguration | async    | gpio_set_config_handler       |
        | GpioSubscribe        | async    | gpio_subscribe_handler        |
        | GpioUnsubscribe      | async    | gpio_unsubscribe_handler      |
        | I2cSetConfiguration  | async    | i2c_set_config_handler        |
        | I2cScan              | async    | i2c_scan_handler              |
        | I2cBatch             | async    | i2c_batch_handler             |
        | SpiSetConfiguration  | async    | spi_set_config_handler        |
        | I2cGetConfiguration  | blocking | i2c_get_config_handler        |
        | SpiGetConfiguration  | blocking | spi_get_config_handler        |
        | SpiBatch             | async    | spi_batch_handler             |
        | UartRead             | async    | uart_read_handler             |
        | UartWrite            | async    | uart_write_handler            |
        | UartFlush            | async    | uart_flush_handler            |
        | UartSetConfiguration | async    | uart_set_config_handler       |
        | UartGetConfiguration | blocking | uart_get_config_handler       |
        | PwmSetDutyCycle      | blocking | pwm_set_duty_cycle_handler    |
        | PwmGetDutyCycle      | blocking | pwm_get_duty_cycle_handler    |
        | PwmEnable            | blocking | pwm_enable_handler            |
        | PwmDisable           | blocking | pwm_disable_handler           |
        | PwmSetConfiguration  | blocking | pwm_set_config_handler        |
        | PwmGetConfiguration  | blocking | pwm_get_config_handler        |
        | AdcRead              | blocking | adc_read_handler              |
        | AdcGetConfiguration  | blocking | adc_get_config_handler        |
        | OneWireReset         | async    | onewire_reset_handler         |
        | OneWireRead          | async    | onewire_read_handler          |
        | OneWireWrite         | async    | onewire_write_handler         |
        | OneWireWritePullup   | async    | onewire_write_pullup_handler  |
        | OneWireSearch        | async    | onewire_search_handler        |
        | OneWireSearchNext    | async    | onewire_search_next_handler   |
        | Version              | async    | version_handler               |
        | GetDeviceInfo        | blocking | device_info_handler           |
        | SystemResetSubscriptions | async | system_reset_subscriptions_handler |
    };
    topics_in: {
        list: TOPICS_IN_LIST;

        | TopicTy                   | kind      | handler                 |
        | ----------                | ----      | -------                 |
    };
    topics_out: {
        list: TOPICS_OUT_LIST;
    };
}

#[embassy_executor::main]
async fn main(spawner: Spawner) {
    let config = embassy_rp::config::Config::new(ClockConfig::system_freq(150_000_000).unwrap());
    let p = embassy_rp::init(config);

    // Arm the hardware watchdog as defence-in-depth against handler hangs.
    spawner.must_spawn(watchdog_feeder_task(Watchdog::new(p.WATCHDOG)));

    // USB/RPC INIT
    let driver = Driver::new(p.USB, Irqs);
    let pbufs = PBUFS.take();
    let config = usb_config();

    let i2c = embassy_rp::i2c::I2c::new_async(p.I2C1, p.PIN_3, p.PIN_2, Irqs, embassy_rp::i2c::Config::default());
    let spi = embassy_rp::spi::Spi::new(
        p.SPI0,
        p.PIN_6,
        p.PIN_7,
        p.PIN_4,
        p.DMA_CH0,
        p.DMA_CH1,
        Irqs,
        embassy_rp::spi::Config::default(),
    );

    let gpios = [
        Flex::new(p.PIN_8),
        Flex::new(p.PIN_9),
        Flex::new(p.PIN_10),
        Flex::new(p.PIN_11),
    ];

    // PWM on GPIO12-15 (slices 6-7)
    let pwm_config = pwm::Config::default();
    let pwm_slices = [
        Pwm::new_output_ab(p.PWM_SLICE6, p.PIN_12, p.PIN_13, pwm_config.clone()),
        Pwm::new_output_ab(p.PWM_SLICE7, p.PIN_14, p.PIN_15, pwm_config.clone()),
    ];
    let pwm_configs = [pwm::Config::default(), pwm::Config::default()];

    // UART0 on GPIO0 (TX) and GPIO1 (RX) — default Pico 2 header pins
    #[cfg(feature = "hw-rev2")]
    let uart = {
        static UART_TX_BUF: StaticCell<[u8; 1024]> = StaticCell::new();
        static UART_RX_BUF: StaticCell<[u8; 1024]> = StaticCell::new();
        let uart_tx_buf = UART_TX_BUF.init([0u8; 1024]);
        let uart_rx_buf = UART_RX_BUF.init([0u8; 1024]);
        BufferedUart::new(
            p.UART0,
            p.PIN_0,
            p.PIN_1,
            Rev2Irqs,
            uart_tx_buf,
            uart_rx_buf,
            uart::Config::default(),
        )
    };

    // ADC — blocking mode for single-shot reads (GPIO26–29)
    #[cfg(feature = "hw-rev2")]
    let adc = Adc::new_blocking(p.ADC, adc::Config::default());
    #[cfg(feature = "hw-rev2")]
    let adc_channels = [
        adc::Channel::new_pin(p.PIN_26, Pull::None),
        adc::Channel::new_pin(p.PIN_27, Pull::None),
        adc::Channel::new_pin(p.PIN_28, Pull::None),
        adc::Channel::new_pin(p.PIN_29, Pull::None),
    ];

    // 1-Wire — PIO0/SM0 on GPIO16
    #[cfg(feature = "hw-rev2")]
    let onewire = {
        let pio::Pio { mut common, sm0, .. } = pio::Pio::new(p.PIO0, Rev2Irqs);
        static OW_PROGRAM: StaticCell<PioOneWireProgram<'static, PIO0>> = StaticCell::new();
        let ow_program = OW_PROGRAM.init(PioOneWireProgram::new(&mut common));
        PioOneWire::new(&mut common, sm0, p.PIN_16, ow_program)
    };

    #[cfg(feature = "hw-rev2")]
    let context = Context::new(
        i2c,
        spi,
        uart,
        gpios,
        pwm_slices,
        pwm_configs,
        adc,
        adc_channels,
        onewire,
    );

    #[cfg(not(feature = "hw-rev2"))]
    let context = Context::new(i2c, spi, gpios, pwm_slices, pwm_configs);

    let (device, tx_impl, rx_impl) = STORAGE.init(
        driver,
        config,
        pbufs.tx_buf.as_mut_slice(),
        postcard_rpc::server::impls::embassy_usb_v0_5::USB_FS_MAX_PACKET_SIZE,
    );
    let dispatcher = PicoDeGallo::new(context, spawner.into());
    let vkk = dispatcher.min_key_len();

    // Spawn GPIO monitor tasks before creating the server.
    // EUsbWireTx is Clone, so we clone tx_impl for each task.
    for slot in 0..NUM_GPIOS {
        spawner.must_spawn(gpio_monitor_task(slot, tx_impl.clone(), vkk));
    }

    let mut server: AppServer = Server::new(tx_impl, rx_impl, pbufs.rx_buf.as_mut_slice(), dispatcher, vkk);
    spawner.must_spawn(usb_task(device));

    loop {
        // If the host disconnects, we'll return an error here.
        // If this happens, just wait until the host reconnects
        let _ = server.run().await;
    }
}

/// This handles the low level USB management
#[embassy_executor::task]
pub async fn usb_task(mut usb: UsbDevice<'static, AppDriver>) {
    usb.run().await;
}

/// Dedicated watchdog feeder task.
///
/// Feeds the embassy-rp watchdog every 800 ms with a 2-second timeout.
/// The 800 ms cadence leaves margin for the embassy executor's scheduling
/// jitter while keeping the worst-case recovery time under 2 seconds when
/// a handler genuinely wedges (e.g., a 1-Wire PIO program stalling on a
/// shorted bus, an embassy-rp peripheral bug).
///
/// This task MUST be the only feeder. RPC handlers cannot be trusted to
/// feed — the dispatcher-wedge regression closed in commit fdb3ba15e64d
/// means a wedged handler would also wedge any handler-based feed scheme.
/// See docs/superpowers/specs/2026-06-03-pico-de-gallo-category-a-review-synthesis.md
/// finding #3.
#[embassy_executor::task]
async fn watchdog_feeder_task(mut watchdog: Watchdog) {
    watchdog.start(Duration::from_secs(2));
    watchdog.pause_on_debug(true);
    loop {
        Timer::after(Duration::from_millis(800)).await;
        watchdog.feed(Duration::from_secs(2));
    }
}

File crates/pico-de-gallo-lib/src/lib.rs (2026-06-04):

//! Host-side library for communicating with a Pico de Gallo USB bridge.
//!
//! This crate provides [`PicoDeGallo`], an async client for interacting with
//! the Pico de Gallo firmware over USB. It supports I2C reads/writes, SPI
//! operations (including full-duplex transfers), UART reads/writes, GPIO
//! control, PWM output, ADC sampling, 1-Wire bus operations, and device
//! configuration — all via [postcard-rpc](https://docs.rs/postcard-rpc)
//! endpoints.
//!
//! # Quick Start
//!
//! ```no_run
//! use pico_de_gallo_lib::PicoDeGallo;
//!
//! #[tokio::main]
//! async fn main() {
//!     let gallo = PicoDeGallo::new();
//!     let version = gallo.version().await.unwrap();
//!     println!("Firmware v{}.{}.{}", version.major, version.minor, version.patch);
//! }
//! ```
//!
//! # Multiple Devices
//!
//! When multiple Pico de Gallo boards are connected, use [`list_devices`] to
//! enumerate them and [`PicoDeGallo::new_with_serial_number`] to connect to a
//! specific board:
//!
//! ```no_run
//! use pico_de_gallo_lib::{PicoDeGallo, list_devices};
//!
//! #[tokio::main]
//! async fn main() {
//!     for dev in list_devices() {
//!         println!("Found: {:?}", dev.serial_number);
//!     }
//!     let gallo = PicoDeGallo::new_with_serial_number("ABCD1234");
//! }
//! ```
//!
//! # Error Handling
//!
//! All methods return [`Result<T, PicoDeGalloError<E>>`](PicoDeGalloError)
//! where `E` is the endpoint-specific error type. Errors are either
//! communication failures ([`PicoDeGalloError::Comms`]) or endpoint-level
//! errors ([`PicoDeGalloError::Endpoint`]).

pub mod decode;

use nusb::DeviceInfo as NusbDeviceInfo;
use pico_de_gallo_internal::{
    AdcGetConfiguration, AdcRead, AdcReadRequest, GetDeviceInfo, GpioEventTopic, GpioGet, GpioGetRequest, GpioPut,
    GpioPutRequest, GpioSetConfiguration, GpioSetConfigurationRequest, GpioSubscribe, GpioSubscribeRequest,
    GpioUnsubscribe, GpioUnsubscribeRequest, GpioWaitForAny, GpioWaitForFalling, GpioWaitForHigh, GpioWaitForLow,
    GpioWaitForRising, GpioWaitRequest, I2cBatch, I2cBatchRequest, I2cGetConfiguration, I2cRead, I2cReadRequest,
    I2cScan, I2cScanRequest, I2cSetConfiguration, I2cSetConfigurationRequest, I2cWrite, I2cWriteRead,
    I2cWriteReadRequest, I2cWriteRequest, MICROSOFT_VID, OneWireRead, OneWireReadRequest, OneWireReset, OneWireSearch,
    OneWireSearchNext, OneWireWrite, OneWireWritePullup, OneWireWritePullupRequest, OneWireWriteRequest,
    PICO_DE_GALLO_PID, PwmDisable, PwmDisableRequest, PwmEnable, PwmEnableRequest, PwmGetConfiguration,
    PwmGetConfigurationRequest, PwmGetDutyCycle, PwmGetDutyCycleRequest, PwmSetConfiguration,
    PwmSetConfigurationRequest, PwmSetDutyCycle, PwmSetDutyCycleRequest, SCHEMA_VERSION_MAJOR, SCHEMA_VERSION_MINOR,
    SpiBatch, SpiBatchRequest, SpiFlush, SpiGetConfiguration, SpiRead, SpiReadRequest, SpiSetConfiguration,
    SpiSetConfigurationRequest, SpiTransfer, SpiTransferRequest, SpiWrite, SpiWriteRequest, SystemResetSubscriptions,
    UartFlush, UartGetConfiguration, UartRead, UartReadRequest, UartSetConfiguration, UartSetConfigurationRequest,
    UartWrite, UartWriteRequest, Version,
};

pub use pico_de_gallo_internal::{
    AdcChannel, AdcConfigurationInfo, Capabilities, DeviceInfo, GpioDirection, GpioEdge, GpioEvent, GpioPull,
    GpioState, I2cBatchOp, I2cFrequency, PwmConfigurationInfo, PwmDutyCycleInfo, SpiBatchOp, SpiConfigurationInfo,
    SpiPhase, SpiPolarity, UartConfigurationInfo, VersionInfo,
};
pub use pico_de_gallo_internal::{
    AdcError, GpioError, I2cBatchError, I2cError, OneWireError, PwmError, SpiBatchError, SpiError, UartError,
};
pub use pico_de_gallo_internal::{MAX_BATCH_OPS, MAX_TRANSFER_SIZE};
pub use pico_de_gallo_internal::{
    encode_i2c_batch_ops, encode_spi_batch_ops, i2c_batch_response_len, spi_batch_response_len,
};

pub use postcard_rpc::host_client::{IoClosed, MultiSubscription};
use postcard_rpc::{
    header::VarSeqKind,
    host_client::{HostClient, HostErr},
    standard_icd::{ERROR_PATH, PingEndpoint, WireError},
};
use std::convert::Infallible;

/// Description of a connected Pico de Gallo device.
#[derive(Debug, Clone)]
pub struct DeviceDescription {
    /// USB serial number (unique per board, derived from chip ID).
    pub serial_number: Option<String>,
    /// USB manufacturer string.
    pub manufacturer: Option<String>,
    /// USB product string.
    pub product: Option<String>,
}

/// List all connected Pico de Gallo devices.
///
/// Returns a description for each device found on the USB bus matching the
/// Pico de Gallo VID/PID. Use the serial number with
/// [`PicoDeGallo::new_with_serial_number`] to connect to a specific device.
pub fn list_devices() -> Vec<DeviceDescription> {
    let devices = match nusb::list_devices() {
        Ok(iter) => iter,
        Err(_) => return Vec::new(),
    };
    devices
        .filter(|dev| dev.vendor_id() == MICROSOFT_VID && dev.product_id() == PICO_DE_GALLO_PID)
        .map(|dev| DeviceDescription {
            serial_number: dev.serial_number().map(String::from),
            manufacturer: dev.manufacturer_string().map(String::from),
            product: dev.product_string().map(String::from),
        })
        .collect()
}

/// Error type for Pico de Gallo operations.
///
/// Every method on [`PicoDeGallo`] returns this error type, parameterized by the
/// endpoint-specific error `E`. In practice, `E` is a rich error enum like
/// [`I2cError`], [`SpiError`], or [`GpioError`].
#[derive(Debug)]
pub enum PicoDeGalloError<E> {
    /// A transport-level communication error (USB disconnect, timeout, wire format error).
    Comms(HostErr<WireError>),
    /// The firmware processed the request but returned an error.
    Endpoint(E),
}

impl<E: core::fmt::Display> core::fmt::Display for PicoDeGalloError<E> {
    fn fmt(&self, f: &mut core::fmt::Formatter<'_>) -> core::fmt::Result {
        match self {
            Self::Comms(e) => write!(f, "communication error: {e:?}"),
            Self::Endpoint(e) => write!(f, "endpoint error: {e}"),
        }
    }
}

impl<E: core::fmt::Debug + core::fmt::Display> std::error::Error for PicoDeGalloError<E> {}

impl<E> From<HostErr<WireError>> for PicoDeGalloError<E> {
    fn from(value: HostErr<WireError>) -> Self {
        Self::Comms(value)
    }
}
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

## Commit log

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2026-04-20 app, hal, lib, internal: usability improvements
    HAL:
    - Add Error::Message variant with descriptive string context
    - Implement Display and std::error::Error for Error
    - Implement StatefulOutputPin for Gpio (is_set_low/is_set_high)
    Lib:
    - Remove FlattenErr trait; inline .map_err(PicoDeGalloError::Endpoint)
    - Update tests to match
    App:
    - Add --format flag (hex, binary, ascii) for read output
    - Add I2C 7-bit address validation (reject > 0x7F)
    All crates:
    - Add rust-version = "1.90" to all Cargo.toml manifests
    [lib.rs]
2026-04-20 ffi: add compile-time Send + Sync assertion for thread safety
    The FFI handle is passed as a raw pointer to C code which may call
    functions from multiple threads concurrently. All FFI functions take
    only shared references to the inner PicoDeGallo, which is safe because
    HostClient is internally Arc-wrapped and Send + Sync.
    Add a const assertion that will produce a compile error if the inner
    type ever loses its Send + Sync bounds, preventing silent unsoundness.
    [lib.rs]
2026-04-20 docs: add comprehensive documentation across all crates
    Add crate-level, struct-level, and field-level rustdoc comments to
    all six crates. Update all README files and the book to reflect
    current features.
    Source documentation:
    - internal: crate-level docs with wire compatibility warning, feature
    flags guide, and organization overview. Document all constants,
    type aliases, request/response structs with field docs, error types,
    and enum variants.
    - lib: crate-level docs with quick start examples, multi-device usage,
    and error handling guide. Document PicoDeGallo struct and
    PicoDeGalloError enum.
    - hal: crate-level docs with blocking vs async explanation and
    implemented traits tabl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
    [lib.rs, main.rs]
2026-04-20 split set-config into i2c set-config and spi set-config
    Break the unified set-config command into separate I2C and SPI
    configuration commands across the entire stack. Replace the raw u32
    I2C frequency with a type-safe I2cFrequency enum (Standard/Fast/
    FastPlus) matching the I2C specification modes supported by the
    RP2350.
    Wire protocol (internal):
    - Split SetConfigurationRequest into I2cSetConfigurationRequest and
    SpiSetConfigurationRequest
    - Split SetConfigurationFail/Response into I2c/Spi variants
    - Split endpoint "set-config" into "i2c/set-config" and
    "spi/set-config"
    - Added I2cFrequency enum: Standard (100 kHz), Fast (400 kHz),
    FastPlus (1 MHz)
    - I2cSetConfigurationRequest now us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
    [epd2in13b.rs, lib.rs, main.rs]
2026-04-20 chore: bump all crate versions for breaking changes
    internal: 0.2.1 → 0.3.0
    - Split SetConfigurationRequest into I2c/Spi variants
    - Added I2cFrequency enum replacing raw u32
    - Added SpiTransfer endpoint types
    - Added GpioState From<bool> conversions
    - Added MAX_TRANSFER_SIZE constant
    lib: 0.2.1 → 0.3.0
    - Split set_config() into i2c_set_config() / spi_set_config()
    - PicoDeGalloError became generic over endpoint error type
    - Added Display and std::error::Error impls
    - Added list_devices() and spi_transfer()
    hal: 0.2.0 → 0.3.0
    - Split set_config() into i2c_set_config() / spi_set_config()
    - Re-exports changed (I2cFrequency, SpiPhase, SpiPolarity)
    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
2026-04-21 docs: fix MAX_TRANSFER_SIZE references in lib rustdoc
    The rustdoc comments on i2c_read, i2c_write_read, and spi_read
    incorrectly stated the firmware buffer limit as 512 bytes. The actual
    value of MAX_TRANSFER_SIZE is 4096 bytes, as defined in
    pico-de-gallo-internal.
    Update ROADMAP.md to mark item 1.6 complete.
    Closes #6
    [lib.rs]
2026-04-21 feat!: replace unit-struct errors with rich error enums (#1)
    BREAKING CHANGE: wire protocol is not backward compatible — firmware
    and host crates must be upgraded together.
    Replace 12 unit-struct error types (I2cReadFail, SpiWriteFail, etc.)
    with 3 rich error enums that propagate real hardware error details:
    - I2cError: NoAcknowledge, ArbitrationLoss, Bus, Overrun,
    BufferTooLong, AddressOutOfRange, Other
    - SpiError: BufferTooLong, Other
    - GpioError: InvalidPin, Other
    Closes #1
    [lib.rs, main.rs]
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2026-04-21 feat(gpio): add runtime direction and pull-resistor configuration (#4)
    Add gpio/set-config endpoint for runtime GPIO pin direction (input/output)
    and pull-resistor (none/up/down) configuration. Once a pin is configured,
    it enters explicit mode — get/wait on output pins or put on input pins
    returns the new WrongDirection error. Unconfigured pins retain backward-
    compatible auto-switching behavior.
    Closes #4
    [lib.rs, main.rs]
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2026-04-21 Fix gpio direction and pull tests
    [lib.rs]
2026-04-21 feat: add PWM support (4 channels on GPIO 12–15)
    Add 4-channel PWM output using RP2350 PWM slices 6–7 (GPIO 12–15).
    This is a breaking change: GPIO count is reduced from 8 to 4 (GPIO 8–11)
    to free pins for PWM.
    internal:
    - 6 new endpoints: pwm/set-duty-cycle, pwm/get-duty-cycle, pwm/enable,
    pwm/disable, pwm/set-config, pwm/get-config
    - PwmError enum (4 variants), request/response types, PwmDutyCycleInfo,
    PwmConfigurationInfo, NUM_PWM_CHANNELS constant
    - Comprehensive tests (round-trip, wire stability, display, frequencies)
    firmware:
    - PWM init with Pwm::new_output_ab for slices 6–7
    - 6 handlers with frequency→top/divider computation (150 MHz sys clock)
    - Dut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
    [lib.rs, main.rs]
2026-04-21 feat: add GPIO event topics (subscribe/unsubscribe edge monitoring)
    Implement push-based GPIO edge notifications using postcard-rpc topics.
    A host can subscribe to a GPIO pin for rising, falling, or any edge
    events. The firmware transfers pin ownership to a pooled monitor task,
    publishes GpioEvent messages (pin, edge, timestamp_us) over the
    GpioEventTopic, and returns the pin on unsubscribe. While monitored,
    gpio_get/put/wait/set_config returns GpioError::PinMonitored.
    - GpioEdge enum (Rising/Falling/Any), GpioEvent struct
    - GpioSubscribe/GpioUnsubscribe endpoints, GpioEventTopic topic
    - PinMonitored/PinNotMonitored error variants on GpioError
    - 8 new unit tests (107 total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
    [lib.rs, main.rs]
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2026-04-22 chore: remove ADC temperature sensor support
    Remove the RP2350 on-die temperature sensor endpoint and all
    references. Exposing GPIO-based ADC channels:(ADC0–ADC3) remains; only
    the internal die temperature sensor is removed as it provides no
    practical value for a USB bridge.
    Changes across all 6 crates + docs:
    - internal: Remove AdcReadTemperatureResponse type alias,
    AdcReadTemperature endpoint, AdcChannel::TempSensor variant,
    has_temp_sensor field from AdcConfigurationInfo. Update/remove
    related tests (discriminant stability, round-trip, display, config).
    - firmware: Remove temp sensor import, dispatch entry, handler
    function, and ADC_TEMP_SENSOR channel. ADC channel array shrinks
    from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
    [lib.rs, main.rs]
2026-04-22 feat: add logic capture, 1-Wire, batched transactions, and ADC improvements
    Logic Capture (issue #16):
    - internal: CaptureStart/CaptureStop endpoints, CaptureDataTopic (device-
    to-host streaming), CaptureError enum (6 variants), CaptureStartRequest,
    CaptureStartInfo, CaptureStopInfo, CaptureData types. Constants:
    CAPTURE_CHANNEL_MIN/MAX (0/3), MAX_CAPTURE_CHANNELS (4),
    CAPTURE_MIN/MAX_SAMPLE_RATE_HZ.
    - firmware: PIO1/SM0 single-instruction program (in pins, 8 + autopush).
    in_base=8 set via PAC register to sample GPIO 8-11 (channels 0-3).
    Pin-taking/returning semantics (same pattern as GPIO subscribe).
    capture_task with Signal/Channel coordination, 256-byte chunk streaming.
    - li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
    [decode.rs, lib.rs, main.rs]
2026-04-23 Add hardware revision feature flags and Unsupported errors
    Introduce mutually exclusive hw-rev1 (default) and hw-rev2 Cargo
    feature flags in the firmware crate. The v1 landing board only
    routes I2C, SPI, GPIO, and PWM pins; UART, ADC, and 1-Wire are
    not physically connected. Rather than silently failing, the
    firmware now returns Unsupported errors for gated peripherals.
    Firmware changes:
    - compile_error! guards enforce exactly one feature is active
    - Split bind_interrupts into always-on Irqs and cfg-gated Rev2Irqs
    - Context struct fields cfg-gated (uart, adc, adc_channels, onewire)
    - Two Context::new() constructors per hardware revision
    - 15 handler stubs return Unsupported on hw-rev1
    - dev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
    [lib.rs, main.rs]
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2026-04-23 docs: document v1.1 landing board and v1.0 best-effort notice
    Add the v1.1 2x12 header pinout (24 pins, all 20 firmware signals) to
    the Getting Started chapter. Pin 1 (VREF) is at the top-right when the
    board is held with USB facing up; the shroud key faces right.
    Mark v1.0 as best-effort: UART, SPI CS, 1-Wire, and ADC are not routed
    on the original board.
    Update Pin Map: add SPI CS (GPIO 5), drop broken ADC3, change
    UART/ADC/1-Wire from v2 to v1.1+. Fix I²C pull-up spec to 4.7 kΩ
    (matching schematic R1/R2):.
    Update ROADMAP (Phase 4 item 4.3 shipped), CHANGELOG, README, and
    introduction page.
2026-04-24 docs: update ROADMAP to match closed GitHub issues [skip ci]
    Drop second I2C bus (#10) and second SPI bus (#11) — both confirmed
    unnecessary. Renumber 2.6 (10-bit I2C) to 2.4. Protocol sniffing
    (#16) remains as a future item.
    Update stale sections: mark UART, PWM, ADC, 1-Wire, SpiDevice,
    embedded-io, GPIO events, and transaction batching as done in the
    competitive landscape, trait matrix, and "What's Missing" sections.
    Update peripheral budget to reflect current usage.
2026-04-27 Add python bindings
    Closes #30
    [lib.rs]
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2026-05-04 chore: prepare release 0.9.0
    Bump versions across all crates for the 0.9.0 umbrella release:
    - internal, lib, hal -> 0.5.0 (wire-protocol break: Uart/Adc Get-Config
    responses now Result<...>; new Unsupported error variants)
    - ffi, app -> 0.6.0
    - firmware -> 0.9.0
    - pyco -> 0.2.0
    Pin embassy-usb-driver = "=0.2.0" in firmware: 0.2.1 bumped
    embedded-io-async to 0.7, breaking embassy-usb 0.5.1's CDC-ACM
    impl:(still on 0.6). postcard-rpc 0.12 only ships
    embassy-usb-0_5-server, so we cannot move to embassy-usb 0.6.
2026-05-04 ci(check): add lockfile-drift guard
    New `lockfile` matrix job runs `cargo check --locked` against both the
    host workspace and the firmware workspace. Fails any PR that edits a
    Cargo.toml dependency without committing the regenerated Cargo.lock,
    which is the class of bug that produced the embassy-usb-driver 0.2.1
    regression on release day.
2026-05-04 build: adopt release-please + Conventional Commits
    Replace the manual `edit 7 Cargo.toml + CHANGELOG + tag` release dance
    with release-please. Each crate has its own release component matching
    the existing tag-prefix conventions (internal-v*, library-v*, hal-v*,
    ffi-v*, application-v*, pyco-v*, firmware-v*); merging a release PR
    creates the GitHub Release and tag, which the existing release-*.yml
    workflows still consume unchanged.
    * .github/release-please-config.json: per-crate release config
    * .github/.release-please-manifest.json: current released versions
    * .github/workflows/release-please.yml: opens/maintains release PRs on
    every push to main
    * .github/RELEASE-PLEASE.md: how the workf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
2026-05-04 ci: add cargo-deny, cargo-semver-checks, and dependabot
    * deny.toml + check.yml deny job: enforces license allow-list, denies
    yanked crates and unknown registries, and warns on duplicate copies
    of a crate in the dep graph. Duplicate copies are exactly the failure
    mode behind the embassy-usb-driver 0.2.1 break (two embedded-io-async
    majors); cargo-deny would have surfaced that as a CI warning.
    * check.yml semver job: re-enabled on pico-de-gallo-internal so
    accidental wire-protocol API breaks become PR-time failures instead
    of release-day surprises.
    * .github/dependabot.yml: weekly cargo, github-actions, and pip
    updates. Lockfile-only PRs let CI's lockfile-guard validate upstre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
2026-05-04 docs(repo): expand copilot-instructions with release-please and traps
    Single coherent docs pass covering Phases A4, B4, B5, and D1-D5:
    * Commit Conventions: rewritten for Conventional Commits with crate
    scope, examples, and Co-authored-by trailer.
    * Release Process: new section. Replaces the manual 7-Cargo.toml +
    CHANGELOG + tag dance with the release-please flow. Includes the
    schema-version invariant (internal+firmware must release in lockstep)
    and the canonical tag prefix glossary.
    * GitHub Actions trap: documents that tag-triggered workflows run the
    YAML at the tagged commit, not the tip of main.
    * Dependency Change Ritual: wipe-state-then-validate procedure with
    --locked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
2026-05-04 ci(deny): fix pyco license and ignore unfixable unmaintained advisories
    First green run of cargo-deny in CI surfaced four real issues:
    * pyco-de-gallo had no license field. Set it to MIT to match the
    rest of the workspace. (publish=false doesn't exempt it from
    cargo-deny.)
    * RUSTSEC-2023-0089 (atomic-polyfill): pulled by heapless 0.7 ->
    postcard 1.x -> postcard-rpc. No upgrade path until postcard moves
    to heapless 0.8 (which uses portable-atomic).
    * RUSTSEC-2024-0370 (proc-macro-error): compile-time dev-dep via
    bilge-impl -> bilge -> is31fl3743b-driver. Not in shipped binaries.
    * RUSTSEC-2026-0110 (bare-metal): pulled by cortex-m 0.7, which is
    the foundation of the embassy-rp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
2026-05-18 chore(repo): add issue, PR, and discussion templates
    Lower the barrier to contribution by giving newcomers structured
    forms instead of a blank issue body.
    Issue templates (GitHub Issue Forms):
    - bug_report.yml: pre-titled "bug: ...", labeled bug+triage. Asks
    for affected crate(s), peripheral, firmware version + hw-rev,
    host tool version, OS, hardware-under-test, repro steps, defmt
    logs, and regression info.
    - feature_request.yml: pre-titled "feat: ...", labeled
    enhancement+triage. Captures component(s), peripheral, problem
    statement, proposed solution, alternatives, and wire-protocol
    impact (postcard enum reorders are breaking).
    - config.yml: disables blank iss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
2026-05-29 feat(internal,firmware,lib,hal,ffi,application,pyco)!: address P1 review findings
    Address all four P1 findings from the internal review doc
    REVIEW-2026-05-29.md (shared in conversation; not committed):
    P1-1 (lib): route non-key wire errors to `Comms` in `validate()`.
    Previously a transport-level postcard/RPC error during the version
    handshake was being misclassified, masking real comms failures as
    schema mismatches. Adds `map_validate_error` plus tests covering
    the key-error vs non-key-error paths.
    P1-2 (ffi): expose `spi_transfer`, `spi_batch`, and `i2c_batch`
    through the C FFI surface, including tagged batch ops so C
    consumers can drive the same batched flows the Rust host library
    alread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
    [gpio.rs, lib.rs, main.rs]
2026-05-29 ci(repo): drop ../../CHANGELOG.md changelog-path overrides
    release-please v17 (action @v5) rejects parent-directory traversal
    in `changelog-path` and fails with:
    illegal pathing characters in path:
    crates/pico-de-gallo-internal/../../CHANGELOG.md
    Drop the per-package `changelog-path` overrides so each crate falls
    back to release-please's default per-package CHANGELOG.md location.
    The root CHANGELOG.md remains as a human-maintained overview; per
    AGENTS.md §15 and .github/RELEASE-PLEASE.md neither document
    promised a single root file.
    Unblocks the seven release PRs that should auto-open after PR #45
    merges (internal 0.6.0, library 0.6.0, hal 0.6.0, ffi 0.7.0,
    application 0.7.0, pyc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
2026-06-04 feat(firmware): enable watchdog, bound gpio_wait and i2c_scan
    Three coordinated firmware fixes that close the worst reliability
    regressions identified by the crates-review subagents:
    1. gpio_wait_for_* handlers (handlers/gpio.rs) now honor the
    timeout_ms field added to GpioWaitRequest in internal 0.7. A
    value of 0 preserves the pre-0.7 wait-forever behavior. Non-zero
    wraps the embassy wait_for_*_edge future in
    embassy_time::with_timeout and returns GpioError::Timeout on
    expiry. Closes the dispatcher-wedge regression where a wait on
    a never-transitioning pin blocked every other endpoint on the
    device until power-cycle (reliability finding B1).
    2. Embassy-rp watchdog ena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
    [gpio.rs, i2c.rs, main.rs]
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2026-06-04 feat(hal): add Gpio::wait_for_*_with_timeout methods
    Five new async methods on Gpio accept a std::time::Duration and
    propagate GpioError::Timeout from the firmware-side bounded wait.
    The embedded-hal-async Wait trait doesn't support timeouts, so these
    are project-specific inherent methods on Gpio. Trait methods retain
    their wait-forever semantics for compatibility with existing
    embedded-hal drivers.
    Updates docs/ai-agents/pico-de-gallo-hal-examples.md §6.6 Gotchas
    to recommend the bounded variants for production code (AGENTS.md
    §15.1 book/code parity).
    Bumps pico-de-gallo-lib dependency to 0.7.0. Lockstep with internal
    0.7.0 / firmware 0.11.0 per AGENTS.md §6.5.
    Verified: cargo fmt --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
    [lib.rs]
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2026-06-04 style(internal): rustfmt the new gpio_wait_request tests
    The two GpioWaitRequest round-trip tests added in commit
    fdb3ba15e64d (Task 1/3 of the Category A hotfix) were written with
    the struct literal on a single line. rustfmt's default reformats
    the two-field struct literal across multiple lines, so cargo fmt
    --check failed in the host CI mirror (Task 14).
    Pure formatting; no semantic change. Should have been part of
    fdb3ba15e64d but the implementer subagent's cargo test pass didn't
    also run cargo fmt --check on the touched file.
    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
    [lib.rs]
2026-06-04 fix(lib): check schema_major in validate(), extend SchemaMismatch payload
    The major-version field was silently ignored in PicoDeGallo::validate().
    A firmware reporting a bumped major with matching minor would pass
    validation, then host RPCs would mis-decode wire bytes (silent garbage
    out, no error surfaced to the caller).
    Fix: extract the schema-check policy into a private
    check_schema_compatible(&DeviceInfo) -> Result<(), ValidateError>
    helper that checks both schema_major and schema_minor. Pre-1.0 the
    minor is the breaking-change axis per AGENTS.md §6.2; the major is
    also checked so that any future 1.0+ bump is caught immediately.
    ValidateError::SchemaMismatch payload extended with expe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
    [lib.rs]
2026-06-04 feat(hal): add new_validated/validate/system_reset_subscriptions; re-export types
    Three new accessor methods on Hal close Category A findings #5 and
    - Hal::new_validated() and Hal::new_validated_with_serial_number(serial)
    call PicoDeGallo::validate() before returning and surface a
    HalInitError on device-not-connected or schema mismatch. The
    existing lazy Hal::new() still defers failures to the first RPC.
    - Hal::validate() exposes validation as a post-construction call.
    - Hal::system_reset_subscriptions() returns Result<u8, SystemHalError>
    with the count of cleared subscriptions. Recommended after
    new_validated() in any app that uses GPIO subscriptions, so a
    prior host's crashed-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
    [lib.rs]
2026-06-04 feat(ffi): add gallo_init_strict for validation-on-construct
    Two new C constructors call PicoDeGallo::validate() before
    returning and yield NULL on failure (device not present, schema
    mismatch, legacy firmware, communication error):
    - gallo_init_strict()
    - gallo_init_strict_with_serial_number(const char *serial)
    Prefer over the lazy gallo_init in production C code: failures
    surface at construct time rather than on the first RPC, which is
    much harder to diagnose in field bug reports.
    Existing lazy gallo_init and gallo_init_with_serial_number are
    unchanged for backward compatibility.
    One new null-pointer test for the serial-number variant
    (init_strict_with_null_serial_returns_null) mirrori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
    [lib.rs]
2026-06-04 feat(pyco): add PycoDeGallo.open_strict for validation-on-construct
    Two new module-level Python functions call PicoDeGallo::validate()
    before returning and raise RuntimeError on failure:
    - pyco_de_gallo.open_strict()
    - pyco_de_gallo.open_strict_with_serial_number(serial_number)
    Prefer over the lazy open() / open_with_serial_number() in
    production: failures (device not present, schema mismatch) surface
    at construct time rather than on the first RPC. Symmetric to the
    ffi gallo_init_strict added in this same PR series.
    Updates book/src/crates/python.md per AGENTS.md §15.1.
    Closes Category A finding #4 at the Python layer.
    Bumps pico-de-gallo-lib dependency to 0.6.1. Patch bump
    0.3.0 -> 0.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
    [lib.rs]
2026-06-04 fix(application): call validate() before every device-touching subcommand
    gallo now validates the firmware schema up-front in Cli::run()
    before dispatching to any subcommand that touches the device
    (everything except 'list' and 'version'). Previously a schema
    mismatch would surface as a confusing CommsFailed on the first
    RPC; now it produces an actionable error message pointing the
    user at gallo version for the device-reported schema and
    recommending either firmware re-flash or installing a matching
    gallo build.
    list is exempt because it doesn't touch a connected device.
    version is exempt because IT is the diagnostic subcommand for
    schema skew (it already calls device_info() with legacy fal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
    [lib.rs]
2026-06-04 docs(internal): fix GPIO pin range from 0..=7 to 0..=3
    Five doc-comments on GpioGetRequest, GpioError::InvalidPin,
    GpioPutRequest, GpioPullRequest, and GpioSetConfigurationRequest
    said GPIO pin range was 0..=7. The firmware caps at 0..=3
    (NUM_GPIOS: usize = 4 in firmware/src/context.rs:33).
    The agent guide (docs/ai-agents/pico-de-gallo-hal-examples.md) and
    later GpioEvent/GpioWait doc comments already say 0..=3; this
    aligns the inconsistent ones. Pure documentation fix; no API or
    wire-protocol change.
    The test gpio_get_request_round_trip iterates 0..8u8 to exercise
    the upper end of the u8 encoding — preserved as-is since
    serialization works for any u8 (the firmware separately rejects
    pin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
    [lib.rs]
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2026-06-18 Fix JLCPCB part number
    [pico-de-gallo.kicad_pcb, pico-de-gallo.kicad_sch]
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2026-07-20 fix(application): open one USB connection per run
    `gallo` opened a throwaway USB connection to run the up-front
    `validate()` (added 2026-06-04, Category A finding #4), dropped
    it, then opened a second connection for the actual subcommand
    (`spi write-read` opened a third). postcard-rpc's
    `HostClient::new_raw_nusb` releases the nusb interface
    asynchronously on a background worker, so on Windows -- where
    WinUSB grants exclusive access to one session per interface --
    the second `claim_interface` was refused with `Access is denied`
    (ACCESS_DENIED), panicking at postcard-rpc raw_nusb.rs:330.
    Every validated subcommand (`i2c scan`, `i2c get-config`,
    `adc info`, ...) failed deterministically on Win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
    [lib.rs]
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

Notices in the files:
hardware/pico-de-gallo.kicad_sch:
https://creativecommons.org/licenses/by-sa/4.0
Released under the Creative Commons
